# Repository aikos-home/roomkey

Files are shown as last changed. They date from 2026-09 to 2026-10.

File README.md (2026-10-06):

# RoomKey

**A key for every room: a small touch screen on a mechanical keyboard switch, set into an
ordinary German light-switch frame. Doorbell, intercom, alarm and lights, one press away.
Built on ESP32-C6, ESPHome and Home Assistant.**

[Deutsch](README.de.md)

> Status: prototype. The firmware runs on a bare dev board on the desk, the microphone is
> verified, the rest of the parts are ordered. Nothing is installed in a wall yet.
> State of this page: 29 September 2026.

<p align="center">
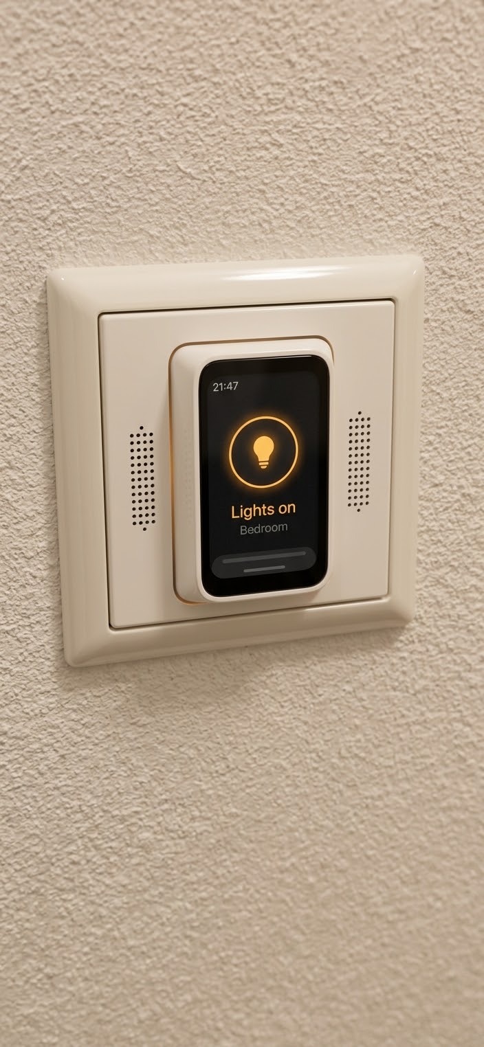
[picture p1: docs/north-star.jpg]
AI-generated concept render: a white light-switch frame with a portrait touch screen key in the middle, speaker and microphone perforations in the white side wings, a soft amber glow around the key
  
  <br><em>Target design — an AI-generated concept render (Google Gemini), not a photo of a built device.</em>
</p>

## What it is

- **A light switch first.** The white rocker around the key still switches the room light,
  with no software involved, so it works without Wi-Fi, without Home Assistant and even
  with a crashed ESP32.
- **A key with a screen.** A 1.47″ touch display on top of a mechanical keyboard switch.
  **Press** does the obvious thing, **hold** does the deliberate thing, and the screen always
  says which is which. Tap and swipe for the rest.
- **The doorbell in every bedroom.** It rings, shows who is calling, and you answer with the
  key: hold to talk, release to listen.
- **The alarm, where you are.** Armed at night? Hold the key for 1.5 s to disarm — Home
  Assistant decides whether that room is allowed to.
- **Local and standard.** ESPHome native API: Home Assistant discovers it with ordinary
  entities, events and actions. No cloud, no custom integration.

It is the in-house counterpart of [Klingelbox](https://github.com/aikos-home/intercom), the
open-hardware door intercom.

## Status

| Area | State |
|---|---|
| UI + interaction state machine (lights, alarm, doorbell, call, menu, info) | ✅ done — runs on the board, verified in simulator and on hardware (scripted tour) |
| Home Assistant contract (subscriptions, light.toggle, disarm script, events, actions) | ✅ **11/11 against a real Home Assistant** (2026.9 dev instance, `tools/ha_contract_test.py`): lights toggle, disarm via HA policy (NIGHT allowed, AWAY refused), ring → answer / talk / hang-up events; also 11/11 against the fake HA incl. audio (`tools/fake_home.py --test`) |
| Demo mode (everything works standalone, no HA needed) | ✅ on by default |
| Status LED (WS2812 on the PoC board; glow ring on the touch board) | ✅ implemented — colours per state, not visually checked |
| Microphone (INMP441) | ✅ **verified on hardware** — wired, recorded: 1 kHz test beep +30 dB, speech +18 dB over the room; 120 Hz high-pass removes knock/handling rumble. Test: `esphome/mic_test.yaml` + `tools/mic_check.py` |
| Intercom audio, voice v2 (shared `aikos_voice` block: RTP/L16 16 kHz, push-to-talk, call model) | ✅ **desk key on v2 since 02.10.**: aikos re-acceptance with the door 71/71; simulator on the same block (`tools/voice_host_check.py`). The key's own audio path (`roomkey.yaml`) stays as the fallback. Listening needs the speaker (WIP, below) |
| Speaker + ringtone (MAX98357A + Waveshare 2030 cavity speaker 8 Ω 2 W) | 🟡 **WIP / opt-in** — compiles, commented out; parts ordered |
| Touch variant of the board (tap / swipe) | 🟡 **WIP** — required by the target design; arrived 02.10.: display, tap and swipe work on the board (`esphome/roomkey_touch.yaml`); chat swipe in a real call, mic, amp and glow ring on it still untested |
| Intercom security | ✅ incoming audio accepted only during an active call; everything else is dropped unheard |
| Door station side | ⬜ other milestone — spec in [docs/intercom-protocol.md](docs/intercom-protocol.md) |
| Optional sensors: SHT31-D climate, LD2410C mmWave presence | 🟡 bought; climate on the shared I²C bus (no extra pins), radar on UART — radar placement still open. No light sensor (decided 06.10.) |
| Enclosure / wall insert | 🟡 fit model + tolerance coupon ready ([hardware/](hardware/)); desk rig (v0) → wall-size fit (v1) next |

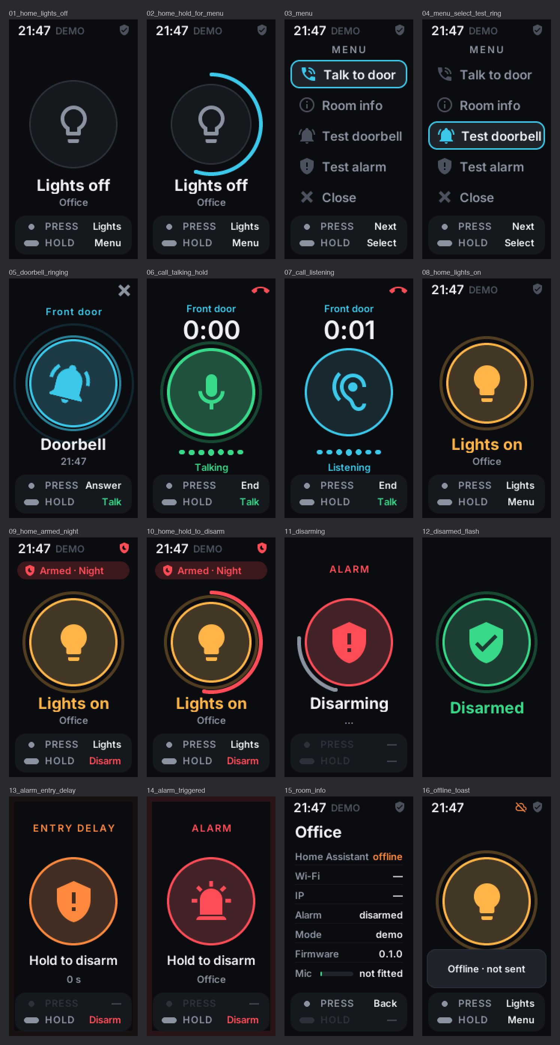
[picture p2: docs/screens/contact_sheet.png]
All screens, rendered by the desktop simulator from the same code that runs on the board


## Inputs

| Screen | Tap | Swipe ↑ | Swipe ↓ | Key press | Key hold |
|---|---|---|---|---|---|
| Home | wakes, shows a hint — never an action | menu | — | all lights | menu · **disarm** when armed |
| Ringing | answer | — | silence this room | answer (on key-down) | answer + talk |
| Call | hold the disc = talk | — | hang up | hang up | push-to-talk |
| Menu | select | — | close | next | select |
| Alarm | — | — | — | hint | **disarm** (1.5 s) |
| **White rocker** | switches this room's light, no software | | | | |

* A tap never switches anything on the home screen: the rocker surrounds the key, so fingers
  brush the screen all the time.
* A mechanical press always starts as a touch; key-down cancels that touch, so one press never
  fires twice.
* The key works on a dark screen — slap it in the dark to switch the lights.

## Hardware

The desk prototype runs on a **Waveshare ESP32-C6-LCD-1.47** (no touch). The target is the
**ESP32-C6-Touch-LCD-1.47** — same chip, touch layer, different size and pinout; the firmware
switches with one line.

### Board comparison (Waveshare drawings)

| | ESP32-C6-LCD-1.47 (PoC, non-touch) | ESP32-C6-Touch-LCD-1.47 |
|---|---|---|
| Outline | 36.4 × 20.3 mm bare PCB | 44.5 × 24.6 mm in black frame, 10.6 mm thick |
| Header | 2 × 9, one GND | 2 × 11, two GND, VBUS, VBAT |
| Mic SCK/WS/SD, L/R | IO18/IO19/IO23, L/R→IO0 | IO7/IO8/IO17, L/R→GND or IO3 |
| Amp BCLK/LRC/DIN, power | IO18/IO19/IO20, 5V | IO7/IO8/IO16, VBUS |
| Key | **IO1** + **IO2** (or the BOOT button) | BOOT + GND |

Firmware: swap the `board:` line in `roomkey.yaml`. The keycap is **not** interchangeable.

### Wiring (desk prototype: ESP32-C6-LCD-1.47)

| Part | Pins |
|---|---|
| Mechanical key switch | **IO1** + **IO2** (IO2 is held LOW by the firmware, because the header's only GND feeds the mic; no soldering; the onboard BOOT button works as the key too) |
| INMP441 mic | VDD→**3V3**, GND→**GND**, L/R→**IO0** (held low by firmware — the header has only one GND), SCK→**IO18**, WS→**IO19**, SD→**IO23** |
| I²S amp (WIP, e.g. MAX98357A) | VIN→**5V**, GND, BCLK→**IO18**, LRC→**IO19**, DIN→**IO20** |

INMP441 is bottom-port: the hole in its PCB must face the room. Mic and amp share the I²S
clocks → half-duplex by design (= push-to-talk, no echo).

Speaker: Waveshare 2030 cavity speaker (8 Ω, 2 W, 20 × 30 × 5.5 mm). Standing on its edge it fits
behind a side wing of the 55 × 55 mm rocker — see the [fit check](docs/fit-check-speaker.png).

## Quick start

```bash
cd esphome
esphome run roomkey_v2.yaml         # build + flash over USB (first time) or OTA (roomkey.yaml = own audio, the fallback)
```
1. **Wi-Fi** (nothing is hardcoded): open https://web.esphome.io in Chrome → *Connect* →
   pick the board → enter Wi-Fi. Or join the hotspot `RoomKey Office` (password: `ap_password`
   in `esphome/secrets.yaml`).
2. **Home Assistant** discovers it; add it with the `api_key` from `esphome/secrets.yaml`,
   then enable *Allow the device to perform Home Assistant actions*.
3. Copy [homeassistant/roomkey_package.yaml](homeassistant/roomkey_package.yaml) into your HA packages.
4. Turn off the key's **Demo mode** switch once the entities exist.

One file per room: copy `roomkey_v2.yaml`, change `node_name`, `room_name` and the entity ids.

## Home Assistant contract

| Direction | What |
|---|---|
| key subscribes | `light.all_lights`, `alarm_control_panel.house`, `binary_sensor.doorbell_button` |
| key calls | `light.toggle`, `script.roomkey_disarm {room, entity_id}` (policy lives in HA) |
| key fires | event `esphome.roomkey {room, node, type}` · type ∈ answer, dismiss, call_door, hangup, talk_start, talk_stop |
| key offers | `ring`, `ring_stop`, `call_state(state)`, `show_toast(message)`, `set_intercom_peer(peer_host, peer_port)`, `simulate_alarm/lights/key` |
| entities | Demo mode, Screen brightness, Input (event: press/hold/…), Screen, Test doorbell, Wi-Fi, IP, intercom counters |

**Security note:** a disarm button in every room is also a disarm button for an intruder.
The key never stores a code — it *asks* HA, and the shipped script only allows disarming
HOME/NIGHT modes and a running entry delay/alarm, never AWAY. Decide that policy consciously.

## Develop without hardware

```bash
cd esphome
esphome compile sim.yaml                                   # desktop simulator (SDL)
.esphome/build/roomkey-sim/.pioenvs/roomkey-sim/program     # SPACE = key, mouse = touch
esphome compile sim_tour.yaml && RK_TOUR=1 RK_TOUR_EXIT=1 RK_SHOTS=shots .esphome/build/roomkey-tour/.pioenvs/roomkey-tour/program  # screenshot every state, cut off from the house
esphome compile sim_v2_check.yaml && python3 ../tools/voice_host_check.py   # voice v2 on the simulator against a fake door
~/.local/share/uv/tools/esphome/bin/python ../tools/fake_home.py --host localhost --test   # HA + door contract test (its audio checks: own audio path)
~/.local/share/uv/tools/esphome/bin/python ../tools/fake_home.py --host aikos-roomkey-desk.local  # interactive fake HA
```
`tour_device.yaml` runs the same tour on the real board and logs frame timings.

## Repository

| Path | What |
|---|---|
| [`esphome/roomkey_v2.yaml`](esphome/roomkey_v2.yaml) | device entry, one per room (voice v2, `aikos_voice`) |
| [`docs/wiring-touch-board.md`](docs/wiring-touch-board.md) | **wiring of the RoomKey Touch prototype**: every wire from the board to mic, amp, sensors, keys, LEDs |
| [`esphome/roomkey.yaml`](esphome/roomkey.yaml) | the same with the key's own audio path (fallback) |
| [`esphome/packages/`](esphome/packages/) | board contracts (PoC, touch, simulator) and feature packages: core UI, HA contract, mic, intercom, speaker |
| [`esphome/src/roomkey_ui.h`](esphome/src/roomkey_ui.h) | UI, input grammar and state machine (LVGL 9) |
| [`esphome/src/roomkey_audio.h`](esphome/src/roomkey_audio.h) | RTP/L16 audio link |
| [`homeassistant/`](homeassistant/) | HA package: disarm policy, ring-stop, door hooks |
| [`tools/fake_home.py`](tools/fake_home.py) | fake Home Assistant + door station: contract test and interactive console |
| [`tools/ha_contract_test.py`](tools/ha_contract_test.py) | the same contract against a real Home Assistant (with [`homeassistant/dev/roomkey.yaml`](homeassistant/dev/roomkey.yaml) stand-ins) |
| [`tools/mic_check.py`](tools/mic_check.py) | records the microphone and checks it hears a test sound |
| [`tools/privacy_scan.py`](tools/privacy_scan.py) | runs before every push |
| [`docs/north-star.md`](docs/north-star.md) | the target design and its decisions |
| [`docs/intercom-protocol.md`](docs/intercom-protocol.md) | audio format and call sequence |
| [`docs/handoff-doorbell-thread.md`](docs/handoff-doorbell-thread.md) | the interface agreed with Klingelbox |

## Performance notes (ESP32-C6, no PSRAM)

RAM 36 % used. Measured on hardware: steady-state LVGL frames 30–80 ms, full view
switches ≈ 100 ms. Software shadows, transform-scaled press animations and a full-screen
alarm tint were replaced by outline halos, size animation and edge bars after the
first hardware run showed 140 ms frames.

## Next steps

1. Enclosure: parametric FreeCAD generator, desk test rig (v0), then a wall-size fit (v1).
2. Speaker, amp and touch board on the bench as they arrive.
3. Wi-Fi + Home Assistant on the real device.
4. Intercom with Klingelbox: a minimal SIP client is the likely path (see the handoff doc).
5. The wall: the insert itself is safety extra-low voltage only (12 V); mains parts (supply, impulse relay)
   sit in certified devices elsewhere, placed by an electrician. Draft and open questions:
   [hardware/docs/insert-design.md](hardware/docs/insert-design.md).
6. Later (decided 30.09.): voice identification, so the family members are told apart even when they
   don't say their name. Local speaker embeddings on the transcriber host, enrolled with ~1 min of speech
   per person through the key's mic. Display only, never for opening doors or disarming. Needs everyone's
   consent; visitors' voices are only compared, never stored.
7. Later (nice to have): translate a resident's answer into the visitor's language on the door screen
   (today every transcript is shown in German; the original words stay in `text_original`).

## Privacy

- The microphone only runs while you hold the key during a call, or while the *Room info*
  screen shows its live level meter. Nothing is recorded or sent otherwise.
- Exceptions you switch on yourself: "Transcriber address" sends a copy of what you say during a call
  (push-to-talk only) to your local transcriber; the WIP test switch "TEST record after ring" records the
  room after every ring and says so on screen. Both are off by default.
- Incoming audio is only accepted during an active call. Keep RoomKeys in the IoT VLAN, like the
  door devices.

## Safety

- Anything on 230 V — the low-voltage supply and the relay for the room light, both in certified devices outside the insert — is a job
  for an electrician. The desk prototype runs on USB only.
- Many older German light-switch boxes have no neutral wire; check before planning a mains supply.

## Licences

- Code (firmware, scripts): [MIT](LICENSE), except the AXS5106L touch driver in
  `esphome/components/axs5106l/`, which keeps its own [MIT licence](LICENSES/MIT-axs5106l-Olivier-Latignies.txt)
- Icon font (Material Design Icons): [Pictogrammers Free License](LICENSES/MDI-Pictogrammers-Free-License.txt)
- Hardware designs (CAD scripts, STL, STEP): [CERN-OHL-P-2.0](LICENSES/CERN-OHL-P-2.0.txt)
- Documentation and images: [CC BY 4.0](LICENSES/CC-BY-4.0.txt)

Designed and written with [Claude Code](https://claude.com/claude-code).

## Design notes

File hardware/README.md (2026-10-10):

# Hardware

Parametric FreeCAD scripts, the same method as [Klingelbox](https://github.com/aikos-home/intercom):
one file holds every dimension, generators read it, `validate()` checks the fit before anything is
printed. Licence: [CERN-OHL-P-2.0](../LICENSES/CERN-OHL-P-2.0.txt).

**→ Build it: [BUILD.md](BUILD.md)** (desk prototype, step by step) · **print it: [print/README.md](print/README.md)** (part list, ready-to-print Bambu Lab A1 files)

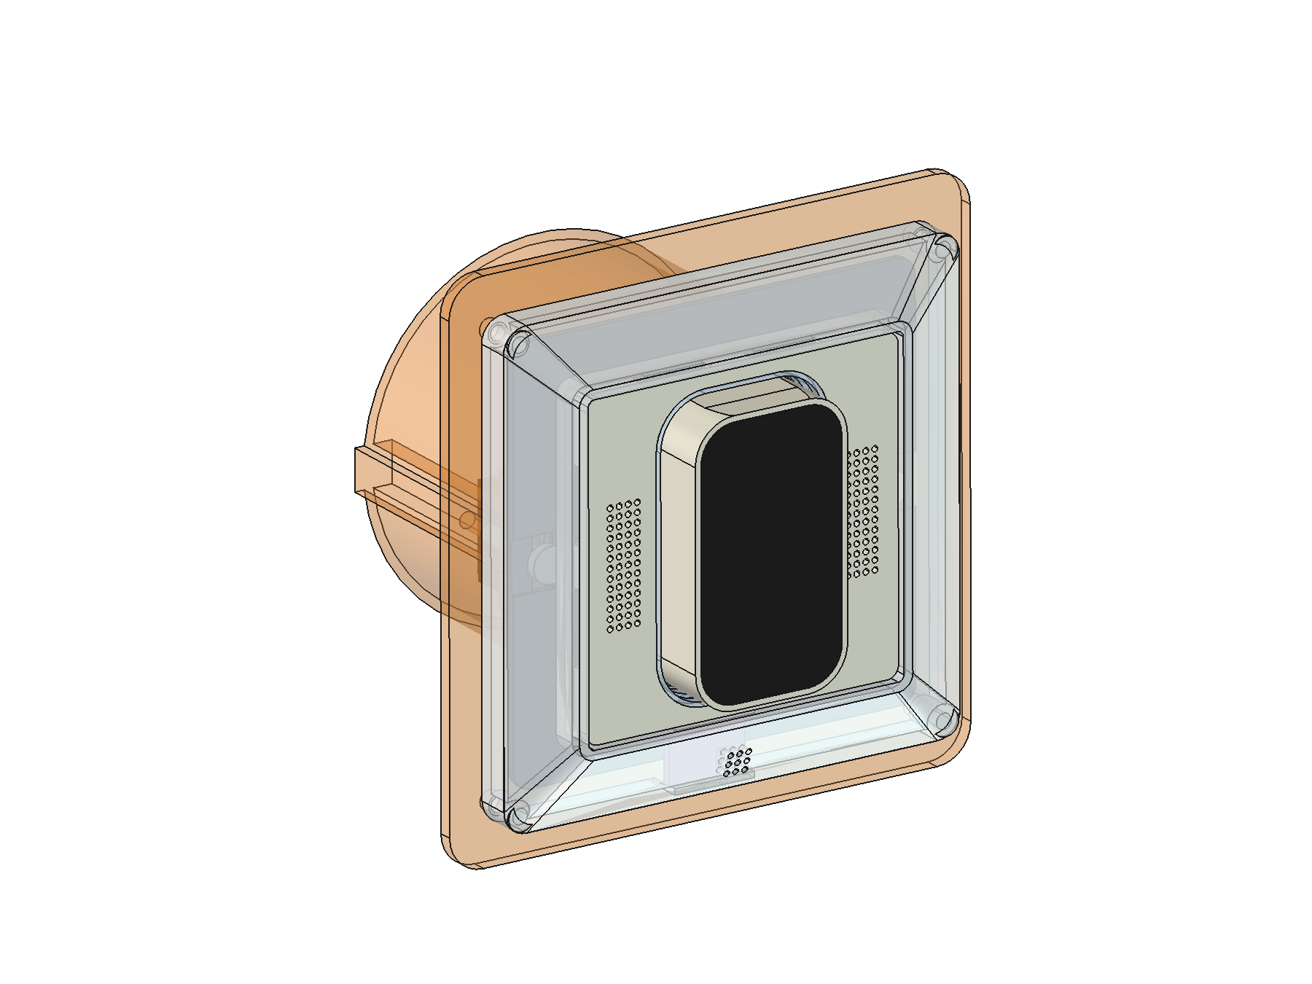
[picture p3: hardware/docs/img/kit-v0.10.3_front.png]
Kit (parts v0.10.3) in the practice box, front 3/4 (FreeCAD)


*Kit (concept v0.7, parts v0.10.3; prototype, WIP, not reviewed): the whole RoomKey in one flush box — touch key, speaker, mic, presence radar,
amplifier, humidity sensor — behind a 1-gang frame. Practice box shown transparent. Real FreeCAD screenshots, made by
[`cad/render_kit.py`](cad/render_kit.py) from the same scripts that write the print files.*

## How this hardware is made — one person and Claude

Everything in this folder comes out of a loop between **one person** (the owner: parts, printer, hands, decisions) and
**Claude** (Anthropic's AI, working in Claude Code: CAD scripts, arithmetic, checks, documentation). Together that covers
the jobs of a small product design team — industrial design, mechanical CAD, tolerance analysis, print engineering,
technical writing and design review. **In practice the owner runs a one-person product design studio.**

**One turn of the loop** (often the same evening, from "this is too tight" to a new print file):

1. **Say it from the bench, in plain words.** Usually one sentence and a phone photo: *"the board fits perfectly but I
   can hardly get it out"*, *"we have two switches — let the key rock so each can be pressed alone, and a press in the
   middle must still do something"*, *"everything goes into one box, except the power supply"*.
2. **Measure the real part.** Calliper values and photos of every module that goes in (speaker, radar, amplifier,
   sensors, the touch board, the wall frame). Each number lands in a parameter file with a tag — **[MEAS]** measured,
   **[DS]** data sheet, **[FREE]** design choice, **[TBD]** assumption — so it is always clear what is known and what is
   a guess. When a value cannot be measured, Claude researches it (vendor drawings, data sheets) and marks it [TBD].
3. **Change the parameters, not a drawing.** Claude edits the parameter files and the FreeCAD generator scripts. No part
   is drawn by hand: every solid, drawing and screenshot is rebuilt from code, so a 0.4 mm change ripples through
   all parts at once.
4. **Let the checks say no before the printer does.**
   - `validate()` runs more than 160 rules per variant (0 errors before anything is exported).
   - Every pair of parts is checked for collisions at rest, key pressed and wobbled, plate pressed at five points.
   - Every printed part must be one solid, and (except the key shell) print without supports: no large surface may
     face the bed in the air.
   - Minimum wall thickness of the printed parts, and clearances reported in millimetres.
   - For the kit, all 41 wires are routed in 3D and checked against the parts; their cut lengths come out as a table.
5. **Hand over print files.** STL per part in print orientation, plus a short print sheet (material, nozzle, layers,
   supports, order) and a wiring sheet. All on one bed of a Bambu Lab A1, PETG.
6. **Print, fit, report back.** The owner prints, tries the real parts and sends the result — which is the next step 1.
   The checks do not catch everything. At the first kit assembly the rocker key simply fell out: the stem forks had been
   sized from a clearance dimension and clamped nothing. The next turn added a catch to the collar, plus a CAD check that
   pulls the key out and must fail to get it free. One turn later the owner dropped the rocker altogether (v0.9).
7. **Review.** Larger revisions go through independent adversarial review rounds: fresh AI reviewers try to break the
   design, and every finding gets a fix or a stated assumption with a test and a fallback
   ([review log](reviews/insert-v0-review-log.md)).

**Rules that hold in every turn.**
- **Safety:** the parts here are extra-low voltage (SELV) only. Everything on 230 V is a certified device, installed by a
  qualified electrician — Claude does not design mains parts, even when asked.
- **The owner decides.** Claude proposes; when a proposal is wrong, it is dropped. Example: Claude moved the sensors into
  a second box to make room; the owner said *"everything in one box"*. The result, kit v0.7, is better: the radar looks
  through the left wing of the plate, the mic hears through a sound tube, and the humidity sensor sits in the frame
  (the owner's idea).
- **WIP is labelled WIP.** Nothing here is built to a standard or certified. Untested features say so.
- **Interfaces are agreed, not guessed.** The pin plan of the kit was checked against the RoomKey firmware by the
  firmware side before it went into this repository.

| | |
|---|---|
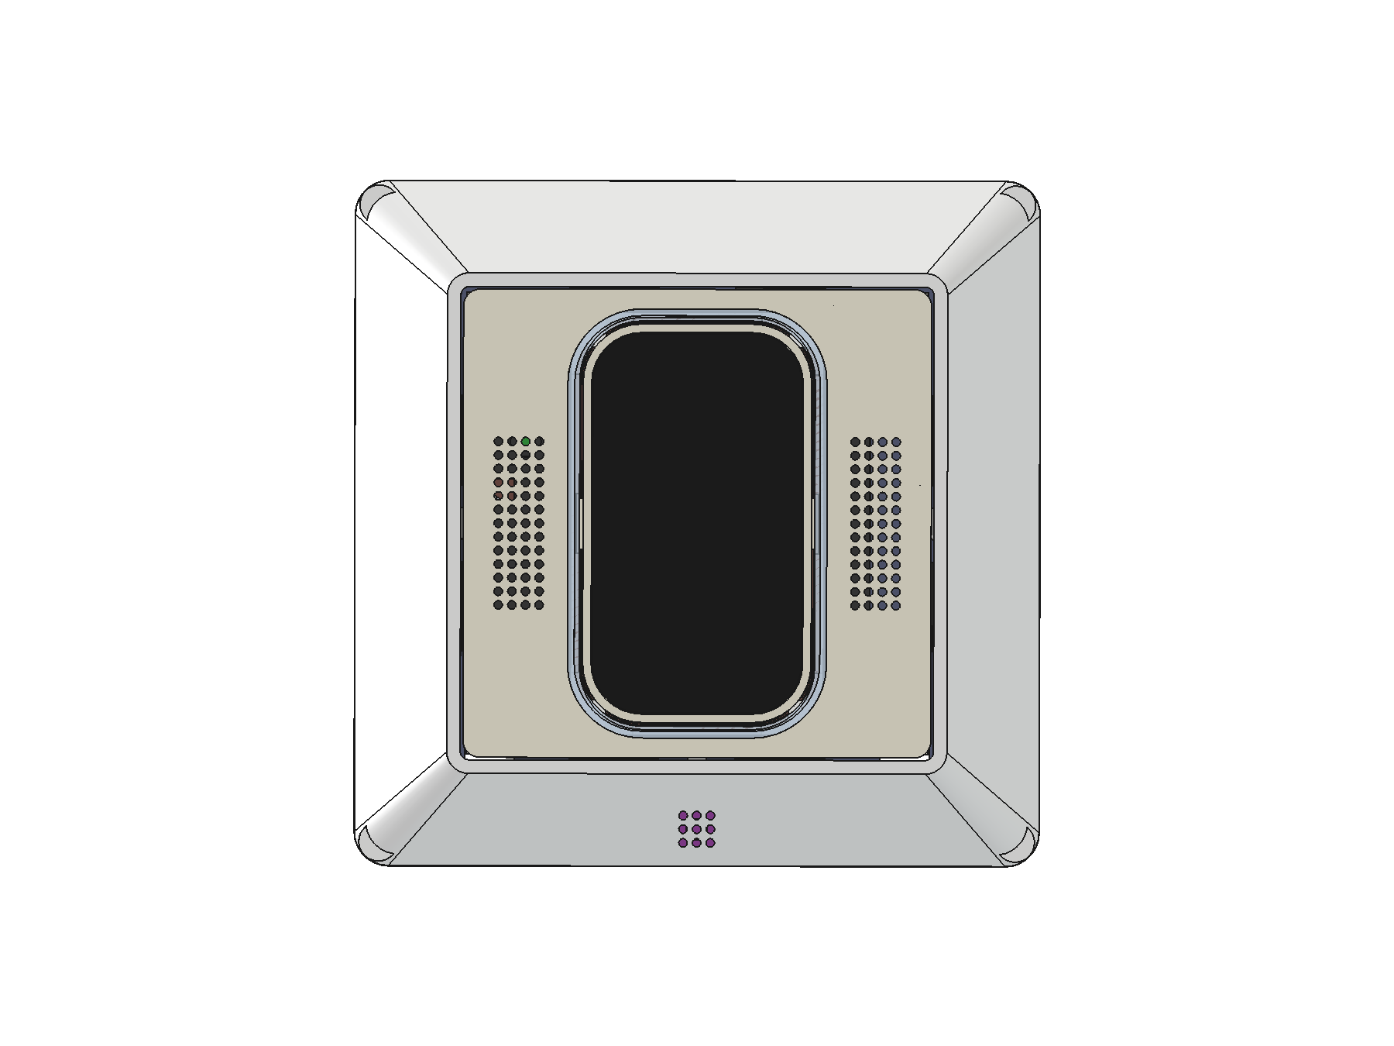
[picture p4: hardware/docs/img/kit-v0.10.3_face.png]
What you see on the wall
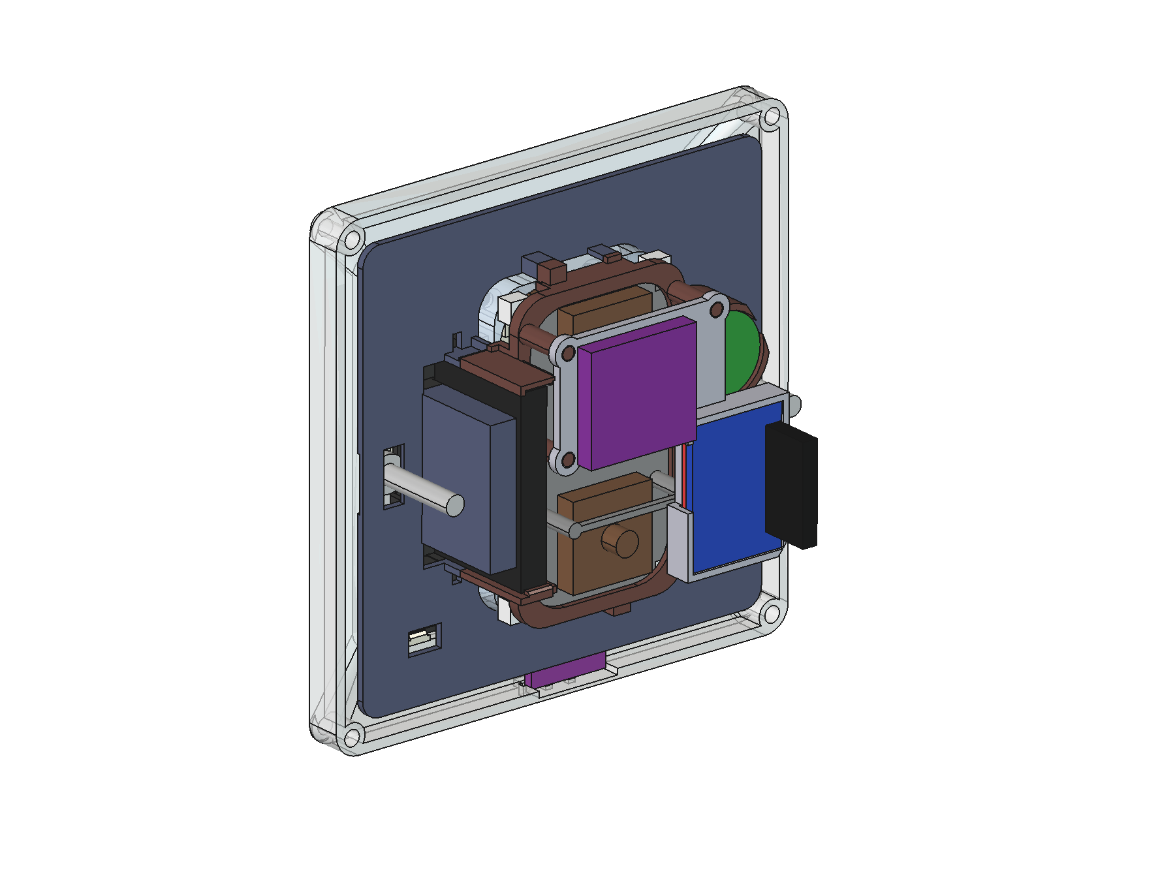
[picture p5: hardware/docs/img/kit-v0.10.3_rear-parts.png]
Rear, without the box: carrier with radar and amplifier, mic, speaker, key switches
|  |  |
| *What you see on the wall: frame, plate with speaker and mic perforation, touch key with glow ring; humidity-sensor vents in the frame.* | *From behind: back carrier with the LD2410C radar (blue) and MAX98357A amplifier (purple), INMP441 mic (green), speaker, the two key switches.* |
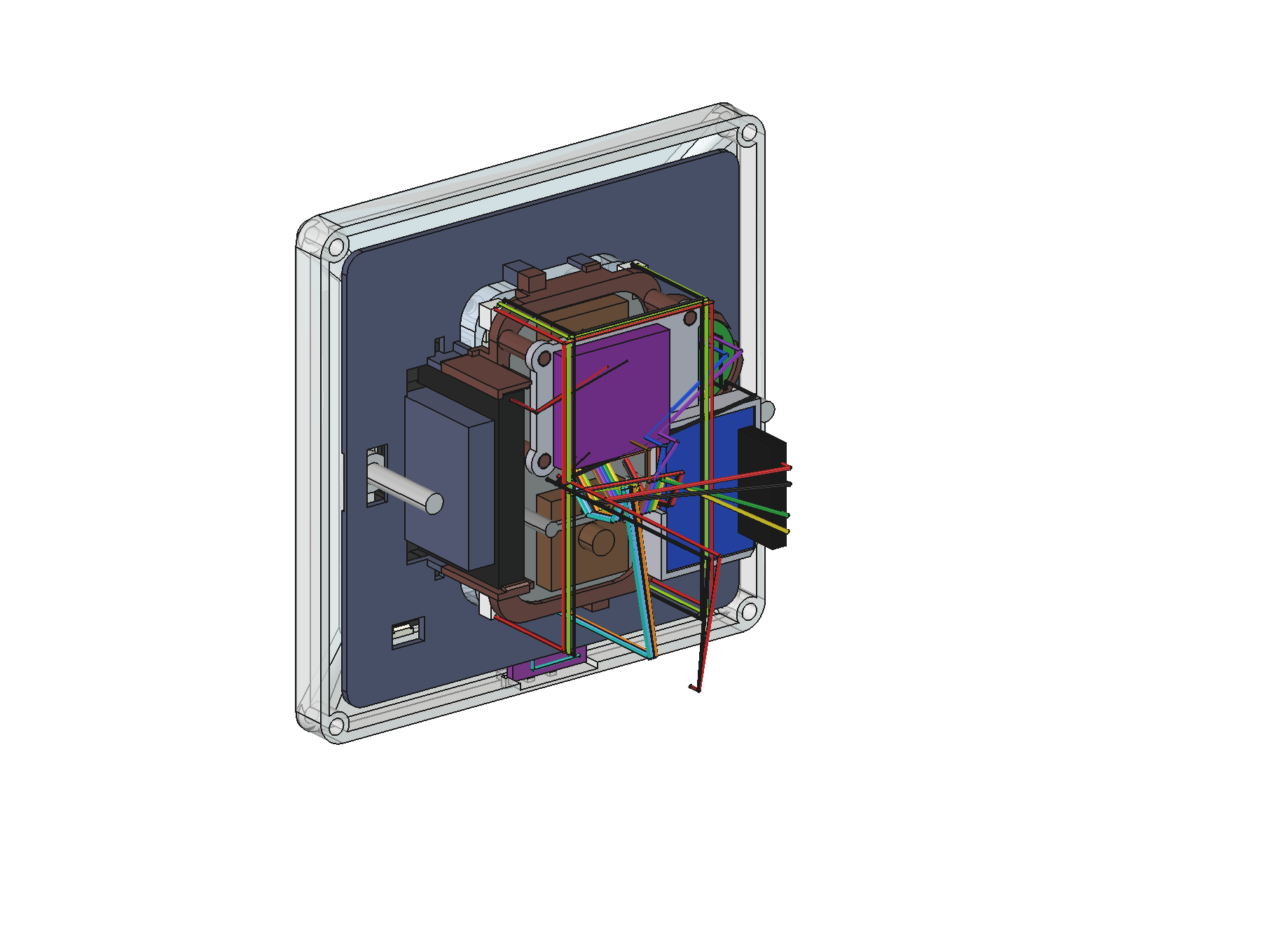
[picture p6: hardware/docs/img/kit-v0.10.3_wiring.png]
Wiring
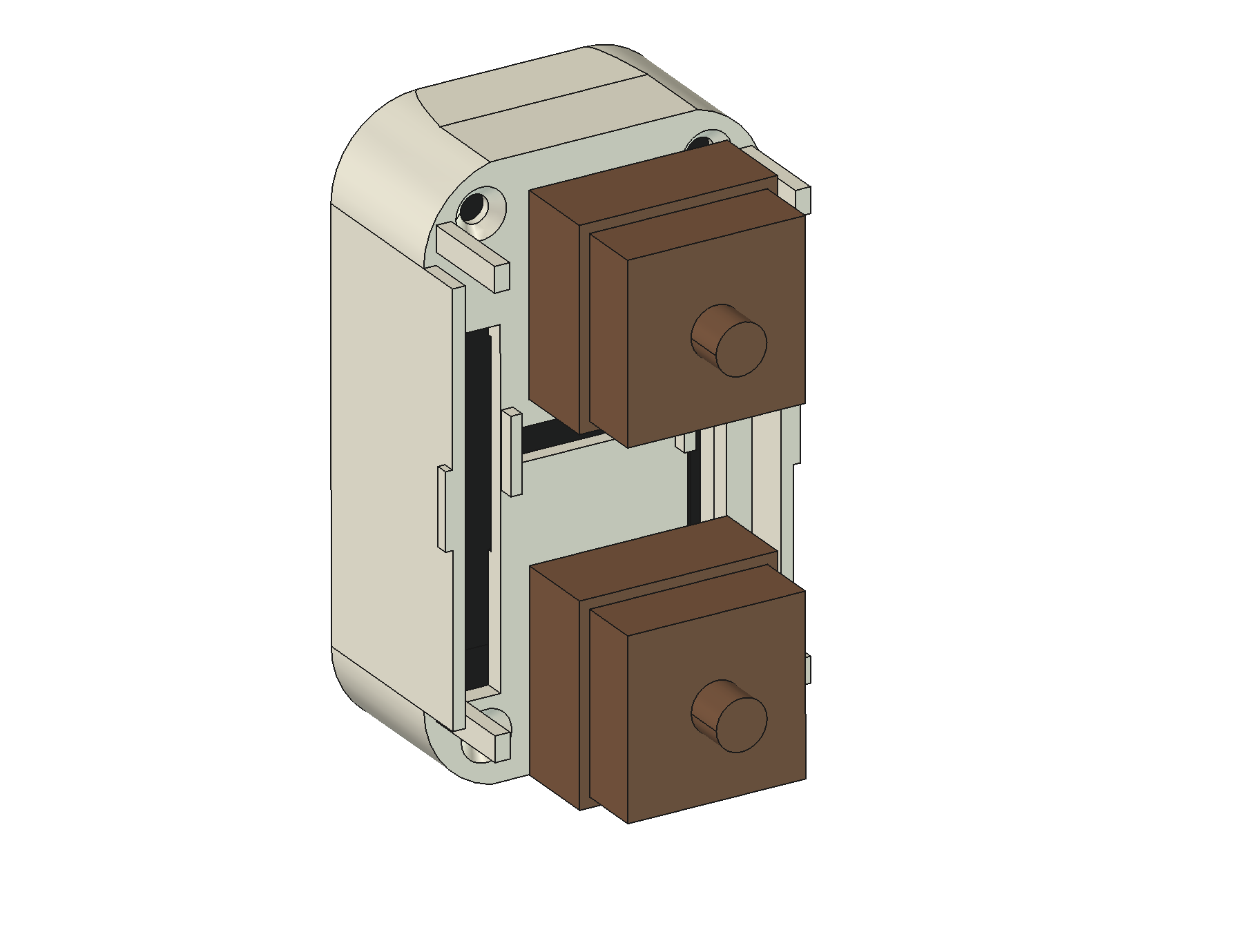
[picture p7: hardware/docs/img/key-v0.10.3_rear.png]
Rigid key v0.9 from behind: fixed socket top, floating socket bottom
|  |  |
| *All 41 wires of the kit, routed in 3D (0.05 mm² silicone wire; cut lengths in [`models/kit-v0.10.3_wiring.json`](models/kit-v0.10.3_wiring.json)).* | *The key from behind (v0.9+): rigid, a fixed stem socket at the top and a floating one at the bottom; both switches are one key.* |

| File | What |
|---|---|
| [`cad/roomkey_params.py`](cad/roomkey_params.py) | every dimension, tagged [DS] datasheet · [MEAS] measured · [FREE] design choice · [TBD] placeholder; `python3 cad/roomkey_params.py` runs the fit check |
| [`cad/make_coupon_v0.py`](cad/make_coupon_v0.py) | tolerance coupon — print this first |
| [`cad/insert_params.py`](cad/insert_params.py) | **wall insert v0.10.4 (draft)**: box, frame, both variants, installation topologies; `python3 cad/insert_params.py` validates L and S |
| [`cad/insert_lib.py`](cad/insert_lib.py), [`make_key_module.py`](cad/make_key_module.py), [`make_insert_L.py`](cad/make_insert_L.py), [`make_insert_S.py`](cad/make_insert_S.py) | FreeCAD generators + collision/clearance checks (rest, key pressed and wobbled with its stems, plate pressed at five points) and print checks |
| [`docs/insert-design.md`](docs/insert-design.md) | **design of the wall insert (v0.10.4 DRAFT)**: concept, stack-up, installation topologies (electrician), BOM, printing, open questions, risks |
| [`cad/desk_lib.py`](cad/desk_lib.py), [`make_practice_box.py`](cad/make_practice_box.py) | **practice box v0.1**: one flush-box replica + a 1-gang frame with the humidity sensor. Prototype, never in a wall |
| [`cad/kit_lib.py`](cad/kit_lib.py), [`make_kit.py`](cad/make_kit.py), [`wiring_lib.py`](cad/wiring_lib.py) | **kit (WIP; concept v0.7, parts v0.10.3)**: the whole RoomKey in one box — back carrier (radar + amplifier), mic sound tube, 41 wires with cut lengths |
| [`cad/view_kit.py`](cad/view_kit.py), [`render_kit.py`](cad/render_kit.py) | open the kit in the FreeCAD GUI (coloured, grouped) and render the images in [`docs/img/`](docs/img/) |
| [`drawings/`](drawings/) | to-scale front views and sections cut from the CAD solids (`tools/insert_drawings.py`) |
| [`reviews/insert-v0-review-log.md`](reviews/insert-v0-review-log.md) | pre-mortems, independent adversarial reviews, scores, resolutions |
| `models/*_print.stl` | ready to slice · `models/*.step` for editing |

Generate (headless, from the repo root):

```bash
PYTHONIOENCODING=utf-8 /Applications/FreeCAD.app/Contents/Resources/bin/FreeCADCmd -c "exec(open('hardware/cad/make_coupon_v0.py', encoding='utf-8').read())"
```

## Coupon v0 — find the fits first

Print flat, PLA, 0.2 mm layers, no supports (≈ 10 min, 9 g). Dots = variant, 1 dot = left.

| Row | Test | Variants (1 / 2 / 3 dots) | Pick |
|---|---|---|---|
| A (switch cut-outs) | press a key switch into the 1.5 mm plate | 13.9 / 14.0 / 14.1 mm | clicks in firmly, no wobble |
| B (mic seats) | drop the INMP441 in | Ø 13.25 / 13.35 / 13.45 mm | goes in without force, doesn't fall out |
| C (stem sockets) | press onto a switch stem | 4.05×1.25 / 4.10×1.30 / 4.15×1.35 mm | snug, no cracking |

The winners go into `roomkey_params.py` as [MEAS]. Repeat in ABS/PETG before the final parts —
they shrink differently.

## Print the kit

**[`print/README.md`](print/README.md)**: the part list, ready-to-print Bambu Lab A1 files (0.4 and 0.2 nozzle; white PETG, clear PLA for the collar and for the key's support contact layers) and the assembly and gluing steps. WIP.

## Wall insert v0.10.4 (DRAFT / WIP, 2026-10-08)

**AI-assisted draft — nothing built, nothing certified, not approved for mains. All 230 V work only by a
qualified electrician of a registered installation company (NAV §13).** Two variants of the in-wall part with the same printed parts, key module and look —
see [docs/insert-design.md](docs/insert-design.md):

* **The insert is SELV-only (12 V in).** No 230 V, no power supply, no relay in the RoomKey chamber; the
  230 V side is certified devices placed by the electrician (where the switch leg ends, behind the partition of a
  two-chamber box, or in the distribution board — decision procedure in the design doc §9). At the common 2-core
  switch leg this usually means a new cable.
* **Variant L — light-switch replacement.** The ivory plate floats on four SMD tactile switches (B3FS) and is a
  push-button: 12 V SELV pulse → certified impulse relay → the light works without Wi-Fi, HA or ESP (and with any
  fault behind the hub's eFuse; FMEA in the design doc §8.2). The glow lights the gap around the key and a
  translucent rim of the plate.
* **Variant S — socket replacement.** Same parts; the plate goes to the ESP only; the socket at that
  position is lost; only sensible at a usable height.

v0.6 adds the owner's first fit test, the rocker key and wider wire slots. v0.8 makes the rocker key captive after the first kit assembly, where it simply fell out. v0.9 drops the rocker (the owner: it scrapes and does not stay in): a rigid key on both MX again, with a fixed and a floating stem socket, keeping the catch and the stop bosses; end-press binding is still desk test R1 (design doc §0, §3). v0.10 makes every part print without supports (supports broke the key and the chassis): the chassis is three prints glued with CA on pins (the one-piece key stays, printed with supports in its pocket); the switch plate is glued in (design doc §0). None of these was reviewed.
Status: **WIP — the adversarial review gate was NOT passed** (4 rounds, scores ≈ 7/10; the remaining MAJOR items need
real parts, a desk rig and measurements — see the review log). CAD closes in all checked states (0 collisions at rest, key pressed, key + stems wobbled ±1.5°, MX2 at the ends of its floating socket,
plate pressed at five points to the nominal and worst-case stop), `validate()` 0 errors, wall check passes. Blocked on
measurements (rocker-to-wall distance ≥ 8.9 mm, frame retention, box interior, conductors behind 5 WAGOs — plan with a
47 mm box), desk-rig tests (key end presses, touch vs key, glow look, mic path, start-up, relay drive at reset) and six
questions to Eltako — list in the design doc §10 and §13. Print
[`make_coupon_v1.py`](cad/make_coupon_v1.py) (switch seat and snap tongues, stem posts, perforation, colour) and the
key shell + switch plate for the end-press test before any other real part.

| More files | |
|---|---|
| [`cad/make_coupon_v1.py`](cad/make_coupon_v1.py) | coupon v1 for the insert mechanics (rows D, E, F, H) |
| [`../tools/insert_drawings.py`](../tools/insert_drawings.py), [`../tools/insert_wallcheck.py`](../tools/insert_wallcheck.py) | drawings and minimum-wall check (any python with numpy + matplotlib, e.g. FreeCAD's bundled one) |

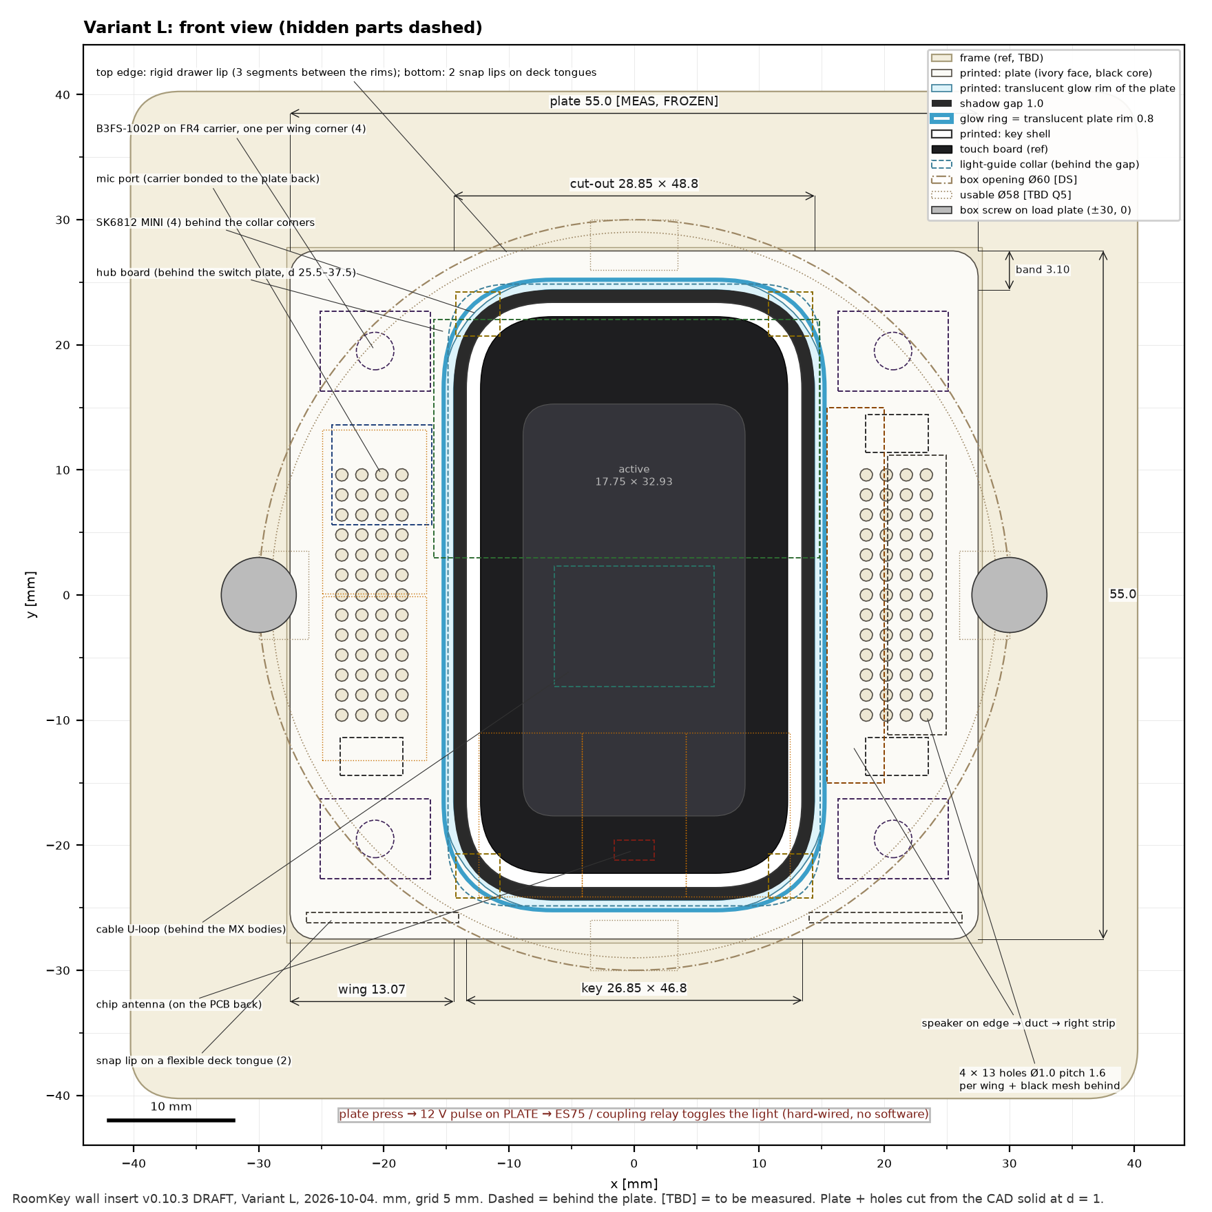
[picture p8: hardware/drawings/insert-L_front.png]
Variant L front


## Plan

**Now (2026-10-04):** first chassis printed and fitted; rocker key and practice box + kit v0.7 ready to print;
parts for the kit arriving. Next: wire the kit on the bench, test the radar through the plate, then the next insert revision.

1. **Coupon v0** — fits for this printer (now)
2. **Desk rig v0** — 55 × 55 rocker face, touch board as the key on two identical MX switches wired in
   parallel (end-press test first, design doc §10), a switch under the rocker as the room-light stand-in (logs only, no mains), speaker on
   its edge with a sound duct, mic, amp, glow LEDs, USB power
3. **Wall fit v1** — same parts inside the real limits (Ø58 box, depth) + a printed dummy flush box
4. **Mounting v2** — screw holes at 60 mm; supply and relay stay outside the RoomKey chamber (SELV-only
   insert) — then the electrician (the v0.5 insert draft models this: [docs/insert-design.md](docs/insert-design.md))

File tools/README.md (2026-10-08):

# tools/

| What | Where now |
|---|---|
| Transcriber (`rtp_recorder.py`, `transcribe_publish.py`, `talk_live.py`, `talk_identity.py`, `transcriber_service.sh`) | **moved** to [aikos-home/aikos `services/transcriber`](https://github.com/aikos-home/aikos/tree/main/services/transcriber), tag `transcriber-v1.0.0` |
| "Who is speaking" eval (`talk_eval.py`, `talk_eval_cases.json`, `eval/`) | **moved** to `services/transcriber/tools/talk_eval.py` and `services/transcriber/tests/eval/` (snapshot test in CI) |

They were removed here on 2026-10-01 after the Mac service switched to the tag (the git history keeps them). Changes
to the transcriber go to aikos-home/aikos only (pull request, `transcriber-unit` green, RoomKey review of the identity
logic, new tag).

Still RoomKey's own: `rtp_play.py` (send a WAV as RTP: stands in for a key or the door), `mic_check.py`,
`fake_home.py` and `ha_contract_test.py` (Home Assistant contract tests), `voice_host_check.py` (the key's voice v2 on
the simulator against a fake door on this machine, build `esphome/sim_v2_check.yaml` first), `privacy_scan.py`, and the CAD helpers
(`cad_preview.py`, `insert_drawings.py`, `insert_wallcheck.py`, and `bambu_kit.py`, which slices the kit into
ready-to-print Bambu Lab A1 files, see `hardware/print/`).

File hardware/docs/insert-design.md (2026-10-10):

# RoomKey wall insert — v0.10.4 (Variant L and Variant S)

> **DRAFT / WIP. AI-assisted design. Not built, not tested, nothing certified.**
> - The insert is a **SELV-only (class III) device**: it never carries 230 V.
> - Everything on the 230 V side is a certified product, installed and tested by a **qualified electrician of an
>   installation company entered in the grid operator's installer register** (NAV §13). Never by the owner, never with
>   parts from this repository.
> - Nothing here is approved for mains.
> - **Review status:** four rounds of independent adversarial review; the quality gate was **not** passed. v0.5 fixes
>   the round-4 findings but was **not** reviewed again — the remaining MAJOR items need real parts and measurements
>   ([review log](../reviews/insert-v0-review-log.md)).
>
> - **v0.6** adds the owner's first fit test, the rocker key, wider wire slots and the kit v0.7 prototype (§0). **v0.8**
>   makes the rocker key captive after the first kit assembly (§0, §3). **v0.9** drops the rocker: a rigid key on two
>   MX with a fixed and a floating socket (§0, §3); **v0.9.1** fixes the speaker tab and the radar tray after the
>   first kit fit, **v0.9.2** closes the radar tray again, **v0.9.3** fits it to the board; **v0.10** makes every part print without supports (§0, §11). None of these was reviewed. (There is no insert v0.7; v0.7 is the kit.)
>
> Date: 2026-10-01, v0.6 and v0.8 2026-10-04, v0.9 2026-10-05, v0.9.1 to v0.9.3 2026-10-06, v0.10 2026-10-07. Licence: CERN-OHL-P-2.0 (hardware), CC BY 4.0 (this text).

**What it is.** The insert replaces the 55 × 55 mm rocker of a German flush-mount switch (or socket) position and
keeps the frame.
- **Key:** a touch board is the keycap. It stands 8 mm proud on two MX switches, framed by a 1 mm gap around which
  the **glow ring** lights up.
- **Plate:** the ivory plate around the key carries the speaker and the microphone behind two perforation strips.
- **Light switching (Variant L):** the plate is also a push-button. It switches the room light through a certified
  impulse relay, **without any software in the path** (north star: [`../../docs/north-star.md`](../../docs/north-star.md)).

| | **Variant L — light-switch replacement** | **Variant S — socket replacement** |
|---|---|---|
| Printed parts | identical: key shell, switch plate, collar, plate (with glow rim), chassis | identical |
| The plate | floating push-button on 4 tactile switches → 12 V SELV pulse on the PLATE line → certified impulse relay **outside** the RoomKey chamber (hard-wired, no software) | same mechanics; the PLATE line goes only to the ESP (HA maps it to the room light — needs a smart light — or a scene); the socket at this position is lost |
| 230 V | only in certified devices: where the switch leg ends (T1a/T1b), in chamber 2 of a two-chamber box (T2), or in the distribution board (T3) — §9 | only in chamber 2 of a two-chamber box (S1) or elsewhere (S2) — §9 |
| In the RoomKey chamber | SELV only: +12 V, 0 V, PLATE | SELV only: +12 V, 0 V |
| Box | **plan with a 47 mm deep box** (box change = plaster work). A standard 40 mm box only if the wall-fit test passes: the parts and 5 × WAGO 221 need ≥ 37.2 mm, but the solid cores probably cannot bend into 2.8 mm (§8.1) | same; only at heights ≥ 70 cm (§9.4) |
| Precondition | a 12 V SELV feed and a relay path must exist. At the common 2-core switch leg (NYM-J 3×1.5) this usually means a **new cable** (§9.2) | a 12 V SELV feed (§9.3) |

**Glossary.**

| term | meaning |
|---|---|
| SELV / class III | safety extra-low voltage (here 12 V DC from a safety-isolating source); a class III device runs only on SELV |
| PE, N, L | protective earth, neutral, line (phase) |
| MCB, RCD, SPD | circuit breaker, residual-current device (30 mA), surge protective device |
| TN-C | old wiring without a separate PE ("klassische Nullung") |
| B3FS, MX | Omron SMD tactile switch (plate); Cherry-MX-style key switch (key) |
| OF, RF, PT | operating force, release force, pretravel of a tactile switch |
| nub gap | air gap between a nub on the plate back and its switch plunger at rest |
| RSS | root-sum-square tolerance stack (statistical); "worst case" = plain sum |
| CLD40 | compression load deflection of a foam at 40 % compression |
| PTC, TVS, eFuse | self-resetting fuse, transient-voltage clamp diode, electronic current limiter |
| FMEA | failure-mode list: what each part's failure does |
| AMS | Bambu multi-material unit (several filaments in one print) |
| d | depth into the wall, d 0 = plate front (§1, coordinates) |

## 0. What changed

**v0 → v0.2 (review round 1: 7 BLOCKERs).** The insert became **SELV-only**; 230 V moved into certified devices
outside the chamber. Floating plate on 4 tactile switches; light-guide collar; mic carrier; U-loop cable.

**v0.2 → v0.3 (round 2: no BLOCKER, ~28 MAJORs).** No foam gaskets between plate and chassis (mic carrier bonded to
the plate, speaker sealed at its grille); glow = translucent plate rim; flange datum + tolerance chain + shims; 8 frame
rims; stainless load plates; T0/T4 and the switch-box inventory; hub GPIO map from the vendor schematic.

**v0.10.3 → v0.10.4 (owner, 2026-10-08: the touch board sits loose in the key shell since the parts are printed with
a 0.2 nozzle).** New `KEY_POCKET_FIT` 0.10/side for the pocket only; `KEY_FIT` 0.15 still sets the key's outer size, so the
shell wall grows 0.05 inwards and nothing outside changes. The fits are now tuned for the 0.2 nozzle (radar tray 0.10
too). L, S, kit: 0 collisions, key captive.

**v0.10.2 → v0.10.3 (owner, 2026-10-08: the collar fits its seat perfectly, but the key scrapes its inner walls).**
Only the collar's inside changes: inner face set back 0.15/side (`COLLAR_IN_EXTRA`, outer unchanged) → key ↔ collar
0.40/side; catch-nub grooves 0.15 deeper (`GROOVE_CLEAR` x 0.1 → 0.25; the groove's back wall 0.65, rule ≥ 0.6 for the
0.2 nozzle). The nubs still overlap the inner face by 0.15; shifted fully sideways the far nub holds by 0.55 — CAD:
key pulled → CAPTIVE at ±0.40. Smallest key ↔ collar gap 0.1 → 0.25 (rest), 0.03 → 0.08 (wobble). 0 collisions.

**v0.10.1 → v0.10.2 (owner, 2026-10-08).**
- **Key back to ONE piece** (the v0.9 shell, byte-identical print file): the owner's one-piece print with supports in
  the pocket fit perfectly; only the chassis broke on its supports. The v0.10 ring/back-plate split is removed;
  `PRINT_WITH_SUPPORTS = {"key_shell"}` — `ceilings()` reports it but does not fail it. Never the chassis.
- **Amplifier pins:** 13.97 (photo) printed too wide, 12.9 (calipers) too close → `AMP_HOLE_PITCH` = their mean 13.435
  (owner's call).
- **Radar tray play 0.15 → 0.10/side:** the same tray fit once and was loose on the next print (print-to-print variance
  ≈ 0.05/side); too tight is fixable with sandpaper, too loose is not. Kit, L, S: 0 collisions, key captive.

**v0.10 → v0.10.1 (owner's print, 2026-10-08: the 2→3 pins did not go into their holes).** The holes open on part 3's
bed face, where the first layers' squish closed the Ø1.4 mouths (0.1 play). Now 0.15 play, a 0.25 × 45° lead-in at
the mouth (`CH_PIN_LEAD`) and a 0.3 point on the pin. Printed v0.10: drill the two holes to 1.5.

**v0.9.3 → v0.10 (owner, 2026-10-07: the whole kit printed with a 0.2 nozzle at 30 mm/s, PETG supports with a PLA
interface — the key shell and the chassis still broke when the supports came out. "Open to gluing (CA) or pin → hole").
WIP: modelled, CAD-checked, not printed.**
- *Why they needed supports (overhang survey, front down):* the key shell's back wall is a 25 × 45 roof over the board
  pocket. The kit chassis: the mic tube stood 1.0 in front of the deck and was the only thing on the bed — the whole
  deck floated; the 71 × 71 flange overhangs the body by ≈ 9.5 all round (≈ 2500 mm²); the rear wall behind the collar
  hangs over the collar seat (a 32 mm bridge on the speaker side, no room for a post); the switch-plate screw bosses and
  the cable-anchor posts hang 3–5 mm free from the ledge.
- ~~**Key = 2 prints**~~ (reverted in v0.10.2) (`key_shell_parts()`): a **ring** (walls, skirts, catch nubs) and a **back plate** (back wall, posts,
  sockets, stop bosses) that sits inside the ring like a lid (0.1/side, `KEY_PLATE_CLEAR`) — the fit locates it, CA from
  behind; the 4 board screws hold board and plate as before. No room for pins in the 1.0 walls; none needed.
- **Chassis = 3 prints** (`chassis_parts()`, all variants): **1 front** (d < flange front: deck, pockets, rims, mic tube),
  **2 flange** (flange + webs to the collar's back face + the speaker duct), **3 rear** (rear wall, ledge, speaker cradle,
  hub posts). Joints: 1→2 glued with the collar through both openings as the jig; 2→3 on **two pins Ø1.2**
  (`CH_PIN_POS` (±5.7, ±26.25), on the island ribs — the only free spots: the plate's tactile switches sit at the corners,
  the speaker on +x, the box's screw domes on the axes) + the web tops, CA.
- **Switch plate glued** onto the ledge (owner's choice) — no screws, no bosses (`SWP_SCREWS = ()`); the **cable anchor**
  (posts + bar) now stands on the switch plate's back.
- **Kit mic tube** flush with the deck front: foam at the plate end 1.5 compressed (`KIT_MIC_FOAM_FRONT`), the module end
  unchanged; the module shelf filled down to the rear part's front face.
- **Frame rims** tied to the deck by webs in the plate-skirt gaps (they print with the front part).
- **Every part prints front down** (collar back down, as before). New check `ceilings()` in every build: planar faces that
  face the bed must be short bridges (span ≤ 16, measured as min(bbox, 4·area/perimeter)); now the widest is 8.7 (the
  insert's mic pocket roof), the kit's 5.7. L, S, kit: 0 collisions, nothing trimmed, key captive, radar tray closed.
- *Open:* the amplifier pins on the carrier — unchanged in CAD since v0.8 (spacing 15.97 outer), but the 0.2-nozzle print
  came out a little too wide; the hole positions are only [PHOTO ±0.5] → owner to measure the two holes.

**v0.9.2 → v0.9.3 (owner's print, 2026-10-06).** The radar slid about in the v0.9.2 tray (≈ 0.5 too long, the short side
just too loose). The board is **22.03** long (caliper photo), not 22.26 (10-03): `RADAR_H` corrected, `KIT_RADAR` now
derived from `RADAR_W/H`, tray play 0.2 → **0.15/side** (= `KEY_FIT` [MEAS]). Pocket 16.14 × 22.33. Kit: 0 collisions,
frame closed.

**v0.9.1 → v0.9.2 (the owner's slicer view and a photo of the radar's antenna face, 2026-10-06; WIP, not printed).**
- *My error in v0.9.1:* the full-width antenna window removed the plate strip under the board's parts edge; next to it
  the cable-loop keep-out (x ±7) takes the tray's +x wall over y −7.8…2.5, so the tray became an open "C" — the floppy
  shape v0.8 had fixed. No check caught it (no collision, still one solid).
- *The photo:* SMD parts run along the **whole** long edge opposite the header, corners included, up to ≈ 4.1 from it;
  the chip reaches 2.3 from that edge. So no plate strip can run under that edge with the board lying on the plate.
- *Fix:* the board sits on **two 1.3 mm ledges** at its short ends, header side only (11.0 from the header edge; the
  parts band starts at 11.6). Every part on the antenna face then floats ≥ 0.2 above the plate, the v0.8 window and the
  plate strip under the parts edge are back, and the tray is closed. Tray 1.3 taller. Reference envelopes from the photo
  (`KIT_RADAR_EDGE` 4.2 × 1.1 [TBD height]); the radar's front parts are no longer exempt from the collision check.
- *New check:* `build_kit` probes the plate strip along the parts edge over the keep-out's y range → "radar tray frame:
  CLOSED", else it fails. Kit: 0 collisions; edge parts ↔ carrier 0.2, pin stubs 0.5, chip 2.5.

**v0.9 → v0.9.1 (the owner's kit fit, 2026-10-06; WIP: modelled, CAD-checked, not printed).** Key, amplifier and
microphone fit as printed.

| Input | v0.9.1 |
|---|---|
| The speaker does not go in: a ≈ 0.5 mm wire tab at the centre of one short end hits the cradle rib. "A hole in one of the towers, not a fork (integrity)." | **Blind tab slot** in the +y cradle rib (towards the amplifier): open to the back (the speaker and its wires come from behind), closed to the front, 4.4 wide (tab 3.4 [TBD] + 0.5/side), 0.9 beyond the speaker end; the rib is thickened outward there so 0.8 of wall stays behind the slot. The +y snap hook is dropped (the slot cut its root and left it as a loose 2nd solid; at the round speaker end it caught nothing). `SPK_TAB` overhang 1.8 (photo) → 0.5 (owner). The speaker reference now carries the tab. New hard check: every printed part is exactly ONE solid. |
| The radar does not sit flat in the intended orientation (header to the wall): small SMD parts on the antenna face, along the long edge opposite the header, land on the carrier. (Turned by 180°, the header pin stubs do the same.) | The antenna **window spans the full board width** → the board rests only on its two short ends (1.5 / ≈ 3 mm). New references: "LD2410C edge parts" (`KIT_RADAR_EDGE` [TBD]) and "LD2410C pin stubs" (`KIT_RADAR_STUBS` [TBD]); both clear the carrier by 0.1. |

CAD: L, S and the kit 0 collisions; key still captive. Print folder `roomkey-bausatz-v0.9.1/` (new: chassis, carrier).

**v0.8 → v0.9 (the owner's verdict on the rocker, 2026-10-05; WIP: modelled, CAD-checked, not printed, not reviewed).**

| Input | v0.9 |
|---|---|
| "Die Idee mit der Wippe ist an sich schlecht. Es führt zu zu vielen Problemen mit der Integrität und Usability." Two problems: a rocking key on stem tops, skirts in the collar and stop bosses may scrape instead of gliding; and it did not stay in (v0.7 fell out, the v0.8 catch was a patch). | **Rigid key on the two MX** (the owner chose it from three options: this, one centre MX + a 2u stabiliser, a printed plunger). The forks and rocking pads are gone; the v0.5 **stem posts with cross sockets** are back (coupon v0 row C fit): **fixed** on MX1 (top), **floating** on MX2 (bottom: its y-arm slot runs through the post, its x-arm slot is 1.80 wide → the stem floats ±0.25 along y, so a pitch error cannot strain the two stems against each other). The key moves straight in and out only. — §3 |
| Keep the key captive | The **v0.8 catch** (nubs in the collar grooves) and the **4 stop bosses** (stop at 3.4, before MX bottom-out) stay unchanged; socket friction holds the key as well. CAD: 0 collisions in L, S and the kit; key pulled → **CAPTIVE**; MX2 shifted ±0.25 → its post still clears the housing window (0.10). |
| Top / bottom functions | Not needed by the firmware today: it already ORs both switches into one key (`key_raw`). If they are ever wanted, they come from the touch point at the click (the AXS5106L touch panel), not from the mechanics. Wiring unchanged (KEY1 = BOOT, KEY2 = IO6). |
| Still open | End-press binding (desk test **R1**) — the reason v0.6 went to the rocker. If R1 fails, the documented fallback is one centre MX + a 2u plate-mount stabiliser. |

**v0.6 → v0.8 (the owner's first kit assembly, 2026-10-04; WIP, not reviewed).**

| Input | v0.8 |
|---|---|
| "Nothing stops the rocker, with the ESP32 module, from simply falling out." | **Key catch:** a rigid nub on each side skirt runs in a groove in the collar's inner face. The groove is open to the back and closed towards the room, so the key is **captive**. The CAD check pulls the key and requires a hit, also when the key is shifted sideways. — §3 |
| Why: the stem forks clamped nothing. Their gap of 4.10 was the cross socket's slot length, which has play; the stem arm is ≈ 4.0. Even a tight fork is a weak spring, so friction alone cannot hold the key | fork gap 3.90 [TBD coupon] for a light pinch; retention comes from the catch, not from friction — §3 |
| The collar must come out for key service | **the collar is no longer glued**: the plate holds it. Assembly: key → collar → plate. The acoustic seam it used to seal is open (fallback: a thin foam ring) — §4, §11 |

**v0.5 → v0.6 (the owner's first print and wishes, 2026-10-02 … 04; WIP, not reviewed).**

| Input | v0.6 |
|---|---|
| First chassis printed (PETG, A1): the touch board fits "extremely perfectly" but is hard to get out; the USB port is no problem | removal = **push-out through the screw hole** (owner tried it: ok); no USB port in the insert — §3 |
| "Two switches — let the key rock so each one can be pressed alone; a centre press must still do something" | **rocker key**: both MX read separately (KEY1 / KEY2), centre press = both; forks, stop bosses and tapered ends; CAD checks rest, pressed, rocked both ways and wobbled — §3 |
| The cable slot under the display is too narrow; pins or wires must go straight back from the header holes | middle slot wider; **header slots** in the key back for pre-soldered pins or wires — §3 |
| Real speaker measured (19.32 × 29.81 × 4.57, stadium shape, paper-thin white ring) | reference body updated; hooks on the straight part are **still open** — §6.2 |
| WS2812B-MINI 3535 ordered (2.0 high) | LED corner notches in the switch plate — §6.3 |
| Production goal: print → plaster → silicone mould → UV resin | noted, not designed for yet; PETG for the prototypes — §10 |
| Whole RoomKey in ONE box, bench power from a lab supply | **practice box v0.1 + kit v0.7** (radar, amplifier, mic, humidity sensor in the frame, 41 wires) — §10 |

**v0.4 → v0.5 (round 4: no BLOCKER, 19 MAJORs; not re-reviewed).**

| Round-4 finding | v0.5 |
|---|---|
| "Works down to 7.6 mm rocker-to-wall" false: the retention needs ≥ 8.9 | Q1 threshold **≥ 8.9 mm**, derived in `validate()` from the pressed snap lips; below it: redesign (thinner deck/lips) — §2 |
| Misconnection text described one case; the fuse protects only +12 V with a low-impedance return; the most likely miswire (lamp as return) leaves the SELV side live | per-conductor **matrix** (§8.1); **RCD 30 mA and a voltage + insulation check before connecting are preconditions** (§9.1); fuse breaking capacity ≥ 1500 A, creepage around it; "SELV only behind the key" qualified |
| IO5 (RELAY_DRIVE) floats at reset → relay pulses at power-up / boot loops | 100 k pull-down + 20 ms qualifier ahead of the one-shot; desk-rig test R12; strapping list corrected — §8.2 |
| eFuse checked against the largest single load; named part cannot do 0.4 A; SNT61 trip point unknown | rule uses the **summed peak (0.37 A) with ±7 % tolerance**; 60 V-class eFuse, OVLO 17 V, SMBJ24A [TBD part]; light-path-vs-hub-short as BLOCKED-ON-DATA (Q4f, test R14, fallback) — §8.2 |
| RF spring distance had a sign error (8.1 mm pressed, not 11.5) | corrected, WARN, closer metal listed (contact leaves, cable wires) — §8.5 |
| Wall-check slices missed the speaker hooks (0.2–0.6 layer stack) | hooks 1.2 thick (tip 0.8); planes through every lip and hook; claim qualified — §10 |
| Touch gestures can fire the key; power-cut state (Q4e) without assumption/fallback; 40 mm box headline; owner measurements inside a 230 V box not flagged; stale mains-in-box text in the north star | each with assumption, test (R13, R15) and fallback; **47 mm box as planning default**; every question tagged owner / electrician, wall-fit prototype defined (§13); north-star note added |
| Mic wires squeezed under the carrier; coupon not in the V-0 chassis material; end-press fallback collides with the cable path | **mic wire well** beside the pocket with an S-loop and a foam plug (§6.1); coupon row D bases in the V-0 filament (§10); binding judged **likely**, both key modules for the first rig (§3) |

**v0.3 → v0.4 (round 3: no BLOCKER, ~15 MAJORs).** Full record: [`../reviews/insert-v0-review-log.md`](../reviews/insert-v0-review-log.md).

| Round-3 finding | v0.4 |
|---|---|
| End presses of the key: the 6–7° pitch model was physically impossible (two stems cannot tilt), the CAD check exempted the colliding pair, the stop bosses landed on a housing shape that does not exist | **Pitch model and stop bosses removed.** MX moved to (0, +15) / (0, −13): the key overhangs its stems by 8.4 / 10.4 mm, like a keycap edge. The key stops at MX bottom-out. CAD checks the key **and its stems** wobbled ±1.5° at rest and pressed, **without** the key ↔ housing exemption: 0 collisions. End presses beyond the stem play are a **desk-rig test** with a named fallback (stabiliser) — §3 |
| Shadow gap "stays dark" was false | Described as it is: **the gap glows** (it looks onto the lit collar); the rim glows dimmer. Decision Q12 with a mask fallback — §4 |
| Terminal zone held one WAGO | **5 × WAGO 221-412 modelled** (3 SELV joints, PE cap, spare-core cap) at d 25.6–44.2 → box ≥ 37.2 mm. Conductor bends: WARN + wall-fit test + fallback (47 mm box) — §8.1 |
| T1 cost/feasibility understated | T1 split into **T1a** (lamp / ceiling box) and **T1b** (wall junction box → new box, plaster work); ES75 needs **≤ 10 A protection** (B16 → B10 or a fuse); luminaire responsibility; T1-LED enclosure sized from the parts (≥ 95 deep) — §9 |
| Switch datum on solder over an unsupported ledge | **SMD B3FS-1002P** on a **flat-backed** carrier; wires soldered from the back into a slot in the flange; the seat's bridge sag is a term in the chain — §5.1 |
| Speaker not located in x; "front volume opens only to the room" false | **Foam strip behind the speaker** presses it onto its face gasket; hooks got a lead-in; leak paths listed honestly — §6.2 |
| A hub fault stopped the light; "cannot exceed the B3F rating" false | **eFuse (0.4 A) on the hub branch**, RELAY_DRIVE through a series Schottky, FMEA of the +12 V / PLATE nodes, claims rewritten — §8.2 |
| 230 V misconnection understated | **250 V AC entry fuse** ahead of everything; **UL94 V-0 chassis mandatory**; text says what really happens — §8.1 |
| SNT61 start-up and mic path untested, no fallback | Assumption + test + fallback for both — §6.1, §8.3 |
| Coupon printed differently from the parts | **0.10 mm layers for plate, chassis and coupon**; support blockers in the carrier pockets; coupon has the pad and the real B3FS seat — §10 |
| Wires inside the key had zero margin | 0.4 mm channel in the key back → 1.2 mm clearance — §3 |
| Many smaller items (press force counted touching switches, plate ↔ frame only at rest, wrong tongue stiffness, firmware power-save, coupled boxes, 411.3.3, chamber-2 accessibility, glossary, drawing captions, S-specific questions …) | fixed or turned into stated assumptions with a test and a fallback; see the review log |

## 1. Files and how to regenerate

| What | Where |
|---|---|
| every insert dimension + `validate()` (both variants) | [`../cad/insert_params.py`](../cad/insert_params.py) (imports [`../cad/roomkey_params.py`](../cad/roomkey_params.py)); sources in `SOURCES` |
| FreeCAD part builders, collision/clearance checks, section export | [`../cad/insert_lib.py`](../cad/insert_lib.py) |
| generators | [`make_key_module.py`](../cad/make_key_module.py), [`make_insert_L.py`](../cad/make_insert_L.py), [`make_insert_S.py`](../cad/make_insert_S.py), [`make_coupon_v1.py`](../cad/make_coupon_v1.py) |
| models | `../models/` (details below) |
| drawings (to scale, cut from the CAD solids) | [`../drawings/`](../drawings/): `insert-{L,S}_front`, `_sections`, `_plan-sections`, `_layers`, `_retention`, `key-module_section`, `insert-topologies` (schematic) |
| minimum-wall check of the printed parts | [`../../tools/insert_wallcheck.py`](../../tools/insert_wallcheck.py) |
| review record | [`../reviews/insert-v0-review-log.md`](../reviews/insert-v0-review-log.md) |

Contents of `../models/`:
- **Printed parts:** `key_shell`, `switch_plate`, `collar`, `plate_{L,S}`, `chassis_{L,S}`, `coupon-v1`. Each comes as
  `.step` (assembly position) and `_print.stl` (print orientation).
- **Plate for the AMS multi-part print:** `plate_{L,S}_body_print.stl` + `plate_{L,S}_glowrim_print.stl`.
- **Assemblies and references:** `insert-{L,S}_assembly.step` (incl. switches, WAGOs, speaker, foam, hub envelope),
  `insert-{L,S}_wall-reference.step` (box + frame, with [TBD] values), `insert-{L,S}_printed-assembly.stl`.
- **Check reports:** `insert-{L,S}_check.json`.

```bash
python3 hardware/cad/insert_params.py            # rules for L and S → ERROR / WARNING / INFO / OK (must be 0 errors)
python3 hardware/cad/insert_params.py --tbd      # every [TBD] value and what to measure
FC=/Applications/FreeCAD.app/Contents/Resources/bin/FreeCADCmd
for f in make_key_module make_insert_L make_insert_S make_coupon_v1; do
  PYTHONIOENCODING=utf-8 $FC -c "exec(open('hardware/cad/$f.py', encoding='utf-8').read())"; done
PY=/Applications/FreeCAD.app/Contents/Resources/bin/python   # any python with numpy + matplotlib
$PY tools/insert_drawings.py && $PY tools/insert_wallcheck.py
```

**State of this revision.**
- `validate()`: **0 errors** in L (29 warnings, 139 OK, 18 info) and S (21 warnings, 137 OK, 17 info). A WARNING is an
  open item with its assumption, test and fallback; INFO lines are assumptions and never count as OK.
- FreeCAD: every printed part is a valid single solid. **0 collisions** in all of these states:
  - at rest (all pairs);
  - key fully pressed (key, stems and board moved; MX bottom-out);
  - key **and stems** wobbled ±1.5° about x and about y, at rest and pressed — only the stems-in-housing and
    stem-in-socket pairs are exempt;
  - plate tipped at five press points, to the nominal stop (all pairs) and to the RSS worst-case stop.
- Wall check: no free wall below 0.8 mm found in any printed part (§10, with its sampling limits).

**Reading `insert-*_check.json`.** Three 0.0 values are designed contacts, each labelled "by design": a lip on its
catch face (the pivot), the collar back face on the rear wall, the speaker front edge on the plenum floor.

**Coordinates.** Front view: origin = plate centre on the plate front face, x right, y up. **d = depth into the wall**
(d 0 = plate front, d 9.0 = wall plane [TBD Q1]). CAD: Z = −d.

**Tags.** **[DS]** data sheet / norm / vendor drawing · **[MEAS]** measured · **[FREE]** design choice · **[TBD]**
assumption until measured (list: `--tbd`).

## 2. Stack-up (both variants)

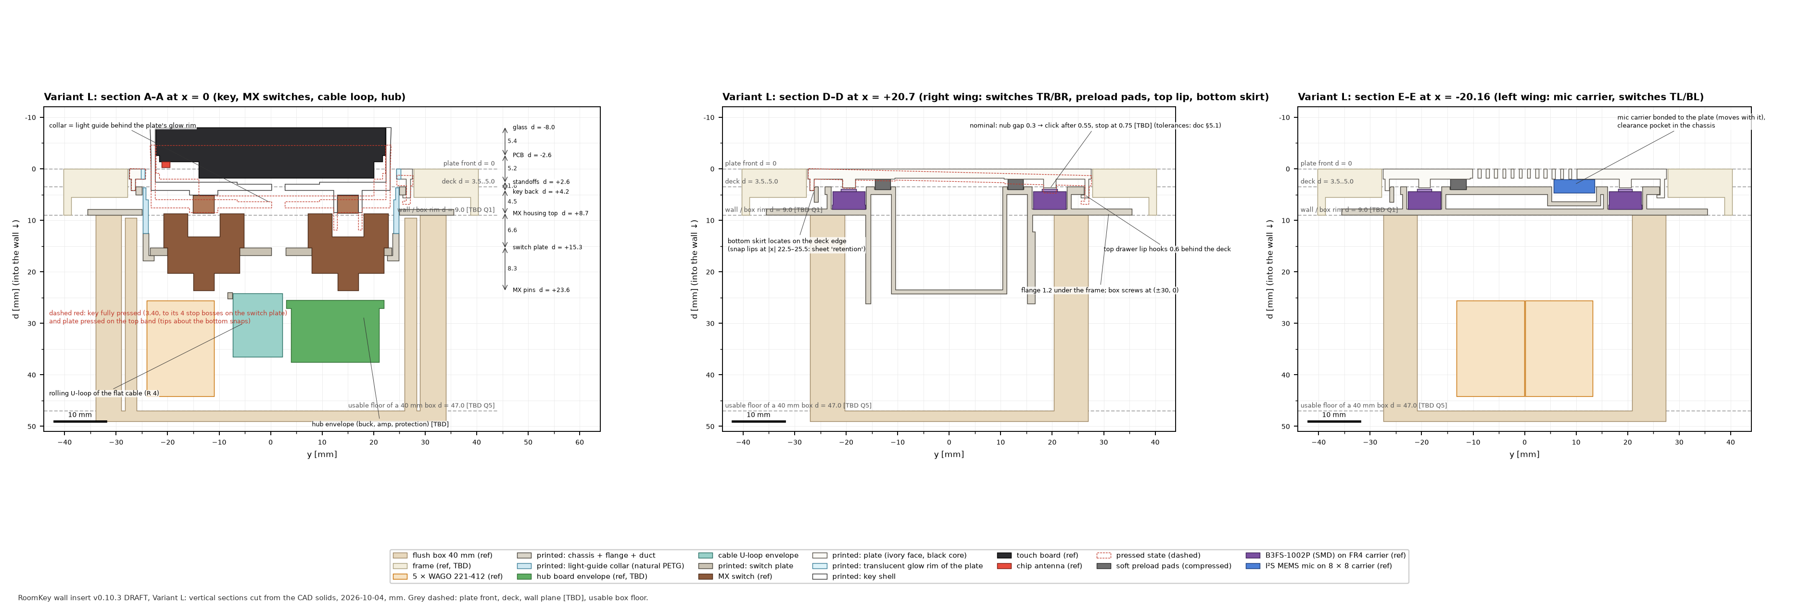
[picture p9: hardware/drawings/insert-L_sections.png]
section A–A, Variant L


| d (mm) | Part | Source |
|---|---|---|
| −8.0 … −2.6 | touch board display module (glass → PCB front, 5.4) | [DS] Waveshare side view |
| −1.4 … −0.3 | ceramic chip antenna on the PCB back, non-USB end | [DS] drawing; size [TBD] |
| 0 … 2.0 | plate skin (ivory face over black core; 0.8 translucent glow rim at the key opening) | [FREE] |
| 2.0 … 4.2 | plate skirts (locate on the deck edges); nubs 2.0–3.6 (Ø2.5 × 1.6) | [FREE] |
| 2.1 … 4.7 | mic carrier, bonded to the plate back (moves with the plate) | [FREE] / [TBD] |
| 3.9 … 7.8 | **B3FS-1002P** plunger tip 3.9 → body 4.4–7.0 → FR4 carrier 7.0–7.8, **carrier on the flange front face (datum)** | [DS] Omron |
| 3.5 … 5.0 | chassis deck; bottom tongues with rib to 6.5; preload pads in 0.5 pockets | [FREE] |
| 3.6 … 12.5 | translucent light-guide collar (2.6 thick at the corners) | [FREE] |
| 4.2 … 8.0 | key side skirts (roll limit) | [FREE] |
| 5.0 … 5.6 / 6.5 … 7.1 | top drawer lip / bottom snap lips (catch faces 5.0 / 6.5) | [FREE] |
| 5.0 … 5.6 | plenum floor over the speaker's front edge | [FREE] |
| 5.6 … 25.6 | speaker 2030 on edge (grille → foam face gasket → channel → plenum → right strip), foam strip behind it | [DS] Waveshare |
| 7.8 … 9.0 | flange (under the frame) with stainless load plates; box screws at (±30, 0) | [FREE] / [DS DIN 49073] |
| 12.6 … 14.9 | 4 × SK6812 MINI on the collar's thick corners | [DS] |
| 15.3 … 16.8 | switch plate (MX plate mount 1.5) | [DS] Cherry |
| 20.3 / 23.6 | MX housing bottom / pin tips | [DS] Cherry |
| 24.0 … 36.5 | cable U-loop envelope | [FREE] |
| 25.5 … 37.5 | hub board envelope (PCB + parts both sides) | [TBD] |
| 25.6 … 44.2 | **5 × WAGO 221-412 standing**: 3 below the hub (y −24.1 … −11), 2 left of it (x −24.9 … −16.6) | [DS] WAGO / [FREE] |
| 47.0 | usable floor of a 40 mm box (2 mm floor/entries) | [TBD Q5] |

**Depth budget.** Parts and WAGOs end at d 44.2 → the box must be ≥ 37.2 mm deep. A standard 40 mm box leaves
2.8 mm, plus the gaps beside the WAGOs, for the conductors to bend in — probably not enough: **plan with a 47 mm box**
(§8.1).

**Front zone.** The switch stack is built from the flange datum:
- plate 2.0 + nub 1.6 + gap 0.3 + B3FS 3.1 + carrier 0.8 + flange 1.2 = 9.0 = the assumed rocker-to-wall distance.
- **The design needs ≥ 8.9 mm** (validate: the pressed snap lips must still end 0.3 before the wall at the worst-case
  press). The switch stack alone would allow 7.6 (the nub shrinks), but the lips, tongues and flange windows are fixed
  to the plate. Above 8.9 the chassis is regenerated for the measured value; below it the deck and lips must be made
  thinner (a redesign). **Q1 gates the first print.**

## 3. Key module (shared)

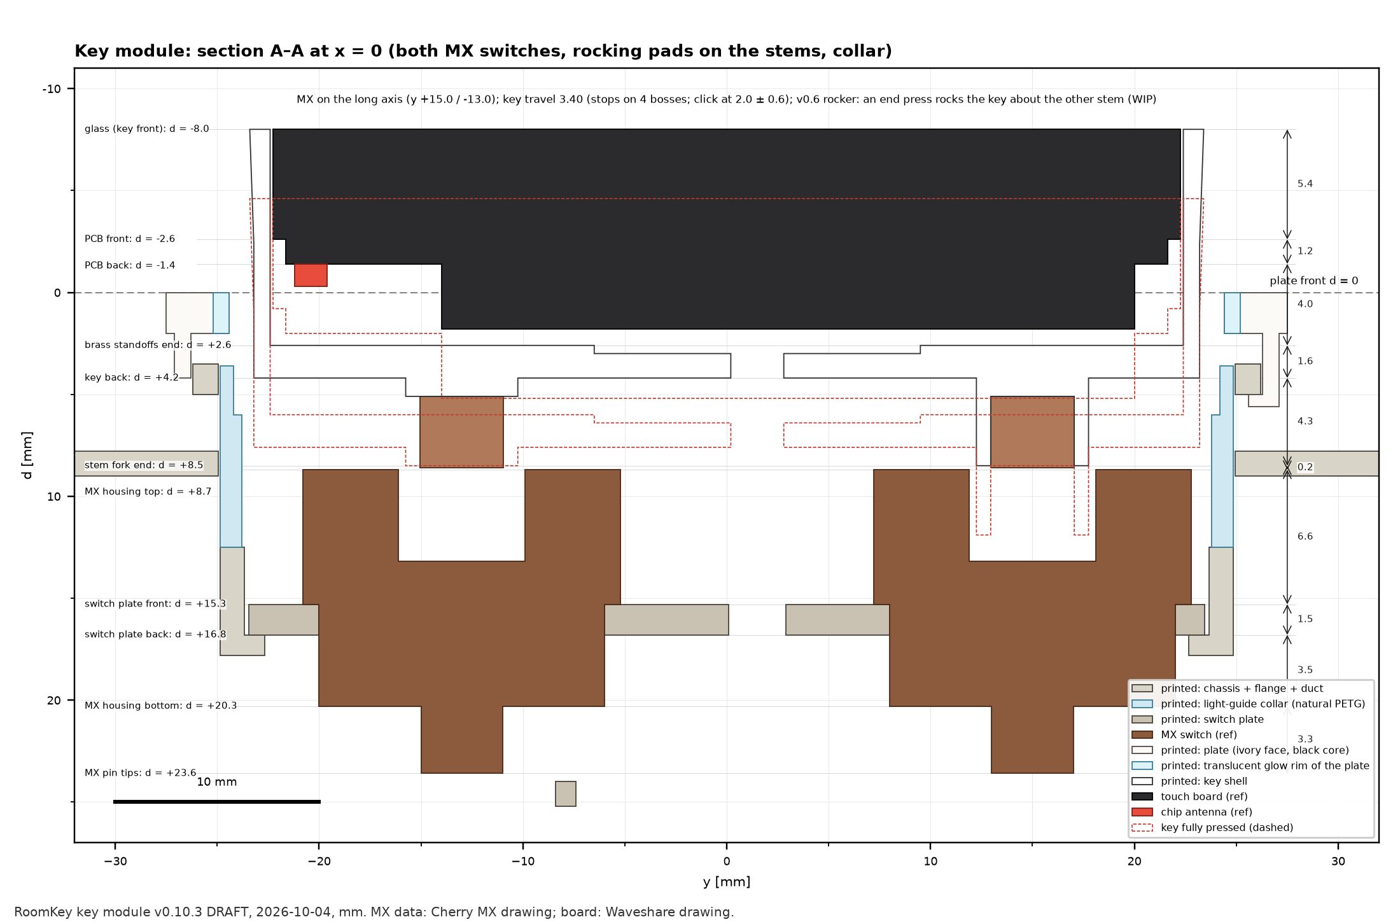
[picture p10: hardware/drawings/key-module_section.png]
key module


**Key shell** (printed front down in the **plate's ivory**, supports inside the pocket, §10). Its front edge is a plain
90° edge and its 8 mm side walls show layer lines; the render's key looks softer (option: a 0.4 × 45° front chamfer).
The 1.0 mm ivory walls have no black core: backlight/glow bleed through the key sides is part of light test R2.
- Pocket 24.85 × 44.80 R5.9 for the board frame (0.15 fit).
- The board is screwed from behind with 4 × M2 × 4 DIN 965 into its brass standoffs [DS]: top pair 17.78 apart,
  bottom pair 17.00 apart, 39.00 vertical. Female M2 thread is [TBD]; fallback M2 nuts.
- Back wall 1.6, screw heads flush. A **0.4 mm channel** in its inner face carries the 14 wires: a band x ±10.4,
  y −6.5 … 9.5 to the cable slot, plus a strip along each header column (|x| 7.4–10.4, y −16.6 … 10.5: the pins run
  y +9.65 … −15.75 [DS drawing]).
- Two stem posts Ø5.5 with MX cross sockets 4.10 × 1.30, 3.4 deep (coupon v0 row C, v1 row E). v0.9: MX1 (top) is
  the **fixed** socket (full cross); MX2 (bottom) **floats** ±0.25 along y (its y-arm slot runs through the post, the
  x-arm slot is 1.80 wide). The fixed socket locates the key; the floating one only holds it in x.

**Guidance: the two MX stems guide the key**, on the long axis at (0, +15.0) and (0, −13.0), pitch 28.
- The key overhangs the stems by **8.4 (top) / 10.4 (bottom)** — about a 1u keycap's stem-to-edge distance (9.1).
- **Both switches are the same brown (tactile)**, so both ends feel the same. v0.9: each stays on its own pin (KEY1 =
  BOOT, KEY2 = IO6) and the firmware ORs them into one key.
- The **side skirts** (long sides only, |y| ≤ 16.5) run in the collar with 0.25 clearance per side. They limit roll
  and keep the key off the plate.

**Force map** (the owned no-name browns: 2.0 ± 0.7 oz = 0.56 ± 0.2 N each [DS of that part]; measure on the rig):

| press point | switches moved | force | bump |
|---|---|---|---|
| centre (between the stems) | both | ≈ 1.1 N (0.7–1.5) | two at once (felt as one) |
| off-centre, between the stems | both: the stem play (±1.5°) allows only ±0.7 mm of travel difference, less than the 2.0 mm pretravel | ≈ 1.1 N | two, slightly staggered |
| key end (beyond a stem) | both, if the key slides; **binding likely** (below) | unknown | — |

**Touch vs key.** The north star says a tap never acts on Home. But published touchscreen studies give 0.8–1.2 N for
swipes — inside the key's actuation range. *Assumption:* normal swipes and taps do not push the key 2 mm down. *Test
R13:* 3 people, 100 swipes from each end and the centre, 100 taps → 0 key-downs. *Fallbacks:* heavier switches
(≥ 1 N each, then repeat R1), firmware: a touch that moved > 2 mm suppresses key-down, and Ringing answers on key-up
after a still press (WIP — the firmware is not changed in this revision).

**Travel and stop.** v0.9 (kept from v0.6): the key stops on **4 stop bosses** that land on the switch plate after
**3.4**, before MX bottom-out (4.0), with both switches past their worst actuation point (2.6). The press ends on the
plate, not on the stems. The key back is then 1.1 above the modelled MX housing top. The stem posts enter the housing
windows with 0.35 per side (0.10 when MX2 sits at the end of its ±0.25 float).

**Wobble (CAD).** The key, its board and **both stems** are tilted ±1.5° (KEY_WOBBLE_DEG [TBD], typical MX stem play
1–2°) about x and about y, at rest and pressed. Only the stem-in-housing and stem-in-socket pairs are exempt.
- No collision. Smallest gaps (v0.9): key ↔ collar 0.03 (roll, about y), key ↔ MX housing 0.26, key ↔ plate 0.79.
- The collar's inner face is set back 0.4 at the short sides over its first 2.4 mm, for the key ends.

**End presses — BLOCKED-ON-DATA, binding likely.**
- *Estimate (review round 4):* an end press puts a moment of ≈ 24·F on the two stem guides; with μ ≈ 0.15 and ≈ 6 mm
  of guide length the friction is ≈ 1.2·F — a sticking drawer. Optimistic values (μ 0.1, 7 mm) still need ≈ 3.7 N.
  The CAD cannot model friction; the overhang (8.4 / 10.4, like a keycap edge) does not prevent this.
- *Test R1 (desk rig, first thing to print: key shell + switch plate + two MX):* press every 5 mm along the key; 1000 ×
  at each end; with a fingertip and a knuckle. Pass: every press clicks, no sticking.
- *Fallback:* one centre MX + a plate-mount 2u stabiliser in the 1.5 mm switch plate (geometry from the bought part).
  It **collides with today's cable path** (11.2 mm wide at y +1.5, through the key back and the switch plate): the
  cable must be split into two bundles beside the centre switch. **Not modelled yet** — build this fallback key module
  alongside the first rig and test both.

**Rocker key — SUPERSEDED by v0.9 (owner, 2026-10-05: the rocker idea is bad in itself).** The rocker text below and
the v0.8 catch reasoning are kept as history. The catch nubs, grooves and stop bosses are still in the model; the forks,
rocking pads and the rocked CAD state are not.

**Rocker key — owner's wish, 2026-10-02 (v0.6, WIP: modelled, not reviewed, test print pending).** Both MX are read
**separately** and the key **rocks**: top end → top switch, bottom end → bottom switch, centre → both. The owner's words:
viewed from the side the key should be "funnel-shaped"; and "the press in the middle should do something".
- **Why the old key could not rock:** the full cross sockets made the key a rigid frame on two stems. Rocking one end down
  by the 2.0 mm pretravel needs ≈ 4° of tilt over the 28 mm stem pitch; MX stems allow 1–2°. The same constraint made
  the end presses bind (R1, see above), so the rocker replaces that problem.
- **Fork mounts:** each stem is held by a fork, not a socket.
  - Two prongs (0.8 thick, 2.0 wide, gap = the old 4.10 socket arm) pinch only the **end faces of the stem's x-arm**.
    These faces are normal to x, so turning about x stays free while the pinch still holds the key on.
  - A **rocking pad** (a cylinder about x, R 1.5) rests on the stem top.
- **Stop bosses:**
  - Four bosses (|x| 11.25–12.4, y +18.5 / −16.5, 2.0 long) land on the switch plate.
  - **Centre press:** the key stops after **3.4** (both switches past their worst actuation point 2.6; MX bottom-out 4.0
    is not reached).
  - **End press:** the key rocks about the far stem's top until the near pair lands, at **≈ 6.1°**. The near switch
    then travels **2.96** (≥ 2.6 + 0.3); the far switch stays at its top stop (0 travel), so top and bottom separate
    cleanly.
  - The bosses sit outboard of the near stem, so the far fork carries only a small pull (≈ 0.1·F) under a hard end
    press.
- **Funnel:** the short-end walls are set back 0.2, rising over 5.6 behind the glass (the 1.0 wall keeps 0.8). It is
  invisible from the front.
- **CAD check (both variants):**
  - States: key rocked to its stop at both ends (key + board turned about the far stem, near stem down, far stem
    still), pressed to the bosses, and wobbled ±1.5° at the deepest travel before a boss lands.
  - **0 collisions.**
  - Gaps when rocked: plate edge 0.25–0.27, collar 0.13–0.14, MX housings ≥ 0.25, forks in the housing window 0.25.
  - Wall check: OK.
- **Costs and open points:**
  - a **15th cable wire** (IO6 = KEY2; IMU INT2 must stay disabled) [TBD RoomKey software];
  - firmware: centre = both switches within a window (≈ 100 ms, rig);
  - **an end press needs only ≈ 0.43 N** (one switch, lever 28/36.4), so touch test R13 is harder. Mitigation: a key
    event during a moving touch is dropped (firmware); fallback: heavier switches;
  - ~~the pull-off force of the fork pinch~~ → v0.8: the key is held by the catch below, not by the pinch;
  - the real MX window shape (6.2 [TBD]).
- **Test print** (owner, PETG, A1, 0.10): only the new key shell, on the 01.10. parts. File:
  `druck/roomkey-taste-v0.6-wippe/` with `DRUCKEN.md`.

**Owner's verdict, 2026-10-05: the rocker concept is dropped.**
> "Die Idee mit der Wippe ist an sich schlecht" — too many problems with integrity and usability: it is unclear that
> rocking can ever glide instead of scrape, and a rocking key does not stay in the housing.

A replacement key is being designed (WIP). The v0.8 key shell and collar below are interim parts. The firmware needs
no change for a single switch on BOOT (RoomKey software, 2026-10-05).

**Key catch — v0.8 (owner, 2026-10-04: "nothing stops the rocker, with the ESP32 module, from simply falling out"; WIP,
modelled, not reviewed).**
- *The cause (my error):* the forks had a 4.10 gap, the cross socket's slot length, which has play; the stem arm is ≈ 4.0.
  So they clamped nothing. A tighter fork would still be a weak spring (0.8 × 2.0 × 4.3 prongs), good for tens of grams.
- *The catch:*
  - A rigid **nub** sits at the free end of each side skirt: 6.0 long, 1.0 high, 0.55 proud of the skirt, at y 0.
  - It runs in a **groove** in the collar's inner face. The groove is 0.1 deeper than the nub and 0.5 longer per end; it is
    **open to the collar's back face** and closed towards the room, 0.45 in front of the nub at rest.
  - Pressing and rocking move the nub deeper into the groove (free). Pulling stops at the groove's front wall, with an
    overlap of 0.30 per side. The key's side play of 0.25 can free only one side at a time.
- *The collar is not glued any more.* The plate overlaps its front face, so the collar cannot leave while the plate is
  on.
- *Assembly:* key onto the stems → collar from the front over the key (the nubs enter the open groove ends) → plate.
- *Service:* plate off → collar out → key off.
- *CAD check:* the key is pulled 0.60 towards the room, centred and shifted ±0.25 sideways; it must hit the collar every
  time, and pulled 0.40 it must not. Rest, pressed, rocked and wobbled stay without collision.
- *Fork:* the gap is now 3.90 [TBD], a light pinch so the key does not rattle on its stems.

**Shadow gap.** 1.0 ± 0.21 (RSS: plate location 0.1 + print 0.1, switch-plate screws 0.1, MX cut-out 0.05, stem play
0.1, socket 0.05). If the key moves further, its skirt touches the collar at 0.75 gap. **It glows** (§4).

**Switch plate.** 1.5, flat print, MX cut-outs 14.0 (coupon v0 row A). Fixed with 2 × M2 × 4 DIN 965 from the front
at (±10.5, 1.5) into ledge bosses.

**Cable.** 14 × AWG30 fine-stranded silicone wires, laid flat (11.2 × 0.8).
- Order: VBUS, GND, BOOT, IO4, IO3, IO5, GND, IO7, GND, IO8, IO16, GND, IO17, 3V3. Ground sits next to the I²S clocks.
- Route: from the header pads across the 0.4 channel, through the slots in the key back and the switch plate at
  y +1.5, then a **rolling U-loop, R 4.0** behind the MX bodies, clamped under an anchor bar.
- Inside the key the wires lie in **1.2 mm** between the board-back parts (3.2 [TBD Q8]) and the channel floor.
  Fallbacks: AWG32 (0.6), or a polyimide flex jumper. Use a board **without pre-soldered headers**.
- **Life target 250 k presses** on the desk rig (30 y × 20/day = 219 k). Fallback: the flex jumper.

**Removal and BOOT.**
- **Fit test 2026-10-02 (owner, real touch board, PETG, A1, 0.10 layers):** the board fits the pocket "extremely
  perfect" (KEY_FIT 0.15 → [MEAS]), but it is **hard or impossible to get out** again.
  - **Removal = push-out** (tried by the owner, 2026-10-02: "ok, not super easy — it's ok like this"). With the key off
    its stems and the screws out, push the board out to the front through the Ø2.2 screw holes in the key back. They
    sit over the brass standoffs; use a toothpick or a 1.5 mm hex key. **No spudger slot** (it was considered: hidden
    in the long sides behind the plate front; dropped).
- **Wires (owner's request 2026-10-03, v0.6):**
  - The central slot is now **12.8 × 2.6** (was 1.4 wide) for 15 wires, or thicker prototype leads.
  - **A 3.0 × 27.5 slot runs through the key back under each pin column** (x ±8.89, y −16.6 … +10.9), so pins or wires
    can leave the header holes straight back. These slots replace the old channel strips.
  - The webs that remain: 0.99 to the central slot, 0.90 to the bottom screw's countersink, 2.04 to the wall. The
    centre strip with the forks stays tied to both solid end regions.
  - Beside a column the pins pass the MX housing with ≈ 0.8 clearance. Anything sticking out must end ≤ 7 mm behind
    the key back: the switch plate is 11.1 behind it at rest and 7.7 when pressed. A standard 2.54 header's long pins end
    ≈ 3 behind it. Flat wiring to the central slot still
    works (the band channel stays).
- The key pulls off its stems (target ≥ 10 N, coupon row E) and hangs on its cable. Behind it there is SELV only.
- The key (26.85 × 46.8) is not a small part.
- **USB (owner's decision 2026-10-01, for v0.6): no USB port in the insert.** The shell's closed top wall leaves no room
  for a plug at the board's USB-C. Flow: first flash and Wi-Fi setup over the bare board's USB-C on the bench; then
  assembly, 5 V over the header (VBUS from the hub); every update over the air. USB is needed only for a rescue (a
  firmware that never brings up OTA): key off, 4 screws, board out of the shell — its USB-C is free (the cable leaves
  from the header pads, away from the USB end), and the hub's Schottky stops back-feed from the laptop's VBUS.
  *Fallback if rescues become common:* the header carries the native USB lines (pin 14 USB_P, pin 16 USB_N, pin 1 VBUS,
  pin 3 GND [DS schematic]; pins 10/12 are SCL/SDA) → 2 more cable wires (16) and a USB-C socket (with 5.1 k on CC) behind the key.
- The key shares GPIO9 (BOOT strap) with the board's button: powering up with the key held enters ROM download mode.
  That is also a **failure mode**: a key held or stuck when the power returns leaves the RoomKey in download mode
  (screen dark) until the next power cycle — the light still works. Recovery: release the key, power-cycle (MCB of the
  12 V supply). Flashing: over the air, or the board's USB-C with the board out of the shell.

**Board LEDs.** The board's always-on red PWR LED and the charger STAT LED (blinks with no battery) are **covered with
black tape** at assembly. They would shine through the 1.0 mm shell.

## 4. Plate, glow ring, wings

front view, Variant L

**Plate.** 55.0 × 55.0 [MEAS, FROZEN], corner R 2.0 [TBD Q7].
- Skin 2.0: ivory face 0.6 [TBD, coupon row H 0.6/0.9/1.2] over a black core, one AMS colour change → opaque.
- Cut-out 28.85 × 48.80 R7.9. Wings **13.07**, bands **3.10**.

**Glow — what it will really look like** (round-3 ray checks, CAD geometry):
- The collar's lit front face (d 3.6, x 13.675–14.875) lies **directly behind 0.75 mm of the 1.0 mm gap** (0.35 at
  the short sides). Looking into the gap you see the frosted, lit light guide: **the gap itself glows**, brightest
  near the corner LEDs.
- The plate's **0.8 mm translucent rim** (co-printed natural PETG, flush with the face) lies 0.45 mm over the lit
  face, 1.6 mm behind it. It glows too, dimmer. Being flush, it is visible wherever the plate is — but the key stands
  8 mm proud: from more than ≈ 13° off-axis the key hides the far-side gap and rim. A standing adult looks down at a
  switch at 105 cm by 30–40°, so the **lower glow line is mostly hidden**, and the upper gap shows the lit key side wall.
- Together: a glowing line at the key base, as in the render — not a dark gap with a lit rim.
- **LEDs off:** the gap shows a pale natural-PETG band instead of a black shadow.
- **Q12 (the owner, on the desk rig):** keep it (glowing gap), or **mask the collar's inner 0.75 mm** (black paint or
  tape on its front face) → dark gap + lit rim, dimmer overall. Test LEDs on and off, in daylight and at night,
  **from standing height and from the bed**, not head-on.

**Collar.** Translucent frosted PETG. Wall 1.2 on the straight runs; the outer corner radius is 5.0, so the corners are
2.6 thick along the diagonal.
- The **4 × SK6812 MINI** sit centred on those thick corners (d 12.6), facing forward.
- v0.8: the collar is **not glued**. It sits in the deck seat (0.1 fit) and the plate holds it in, because the key's
  catch runs in its grooves and the collar must come out for key service (§3). The 0.1 seam it used to seal is open:
  fallback, a thin foam ring on its outer face (§6.2) [TBD rig].

**Glow uniformity (WIP).** The corners are nearest the LEDs; the middle of the long sides will be dimmer.
- Test: desk rig with the real collar and plate.
- Fallbacks: a diffusing texture on the collar front face, then 2 more LEDs (2020) at the long-side midpoints.

**Perforation.** 4 × 13 holes Ø1.0, pitch 1.6 (web 0.6, coupon row F) in each wing.
- **Black acoustic mesh** (0.2) sits in a 0.2 recess of the plate back behind both strips.
- Left strip: the 2nd column, top row (x −20.16, y +9.6) is the **mic port**. The mic carrier is bonded over the top
  three rows; its front is **black solder mask over everything**, the ESD ground ring included (nothing bare visible
  through the 11 blind holes, no exposed copper 2 mm behind the port).
- **Pressing the wings means pressing on the grille** (the press zone is the perforation). Care: dry cloth only, no
  spray. Option: a hydrophobic acoustic vent membrane at the mic port.
- Right strip: all 52 holes open into the speaker plenum (41 mm²).

**Frame.** Opening 55.6 [TBD Q2] → 0.3 per side around the plate (§5.3 for the pressed state).

## 5. Floating plate (push-button), both variants

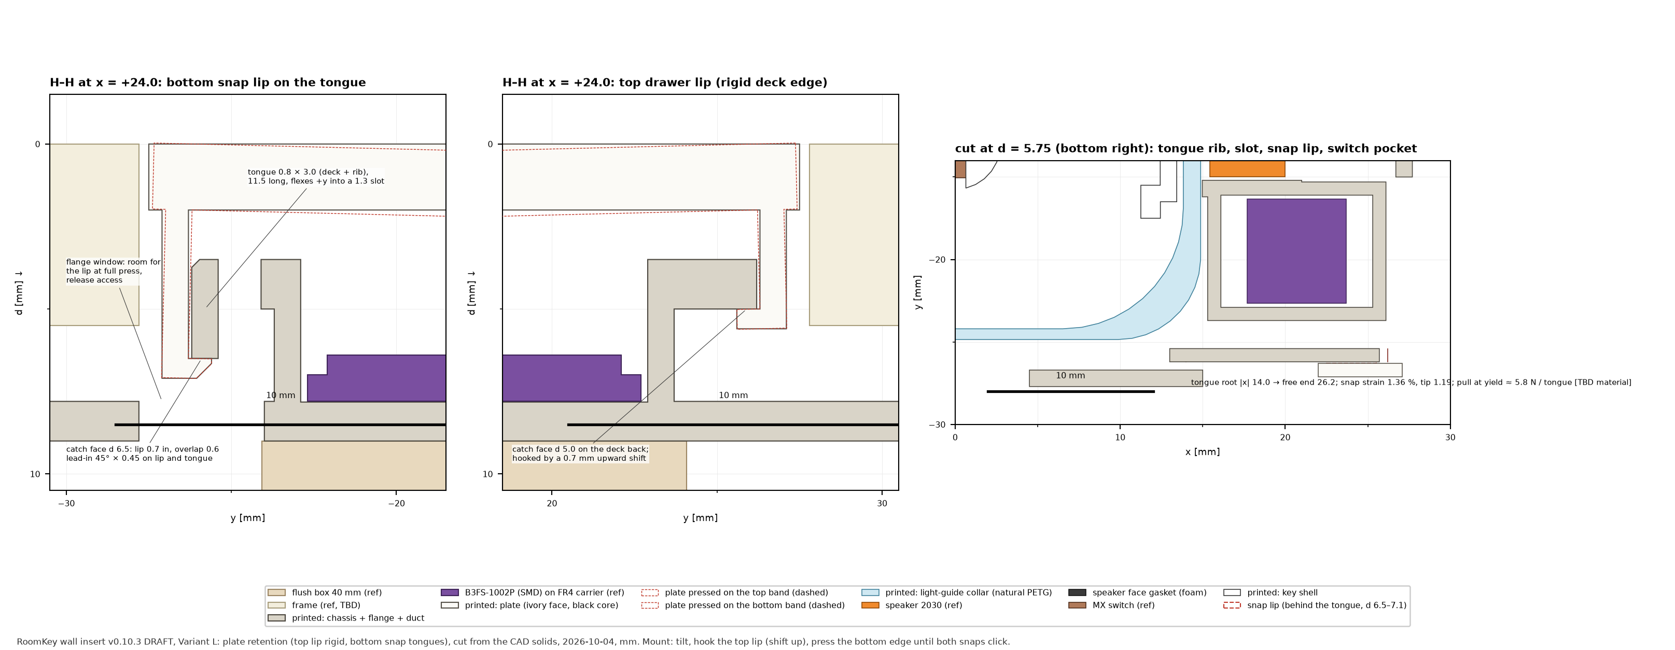
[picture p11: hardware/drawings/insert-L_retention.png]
retention detail


### 5.1 Switches, datum, tolerance, stops

**Switches.** 4 × **Omron B3FS-1002P** (SMD, flat) at (±20.7, ±19.5) [DS]: body 6.0 × 6.3, height 3.1 ± 0.2,
plunger Ø3, OF 1.47 ± 0.49 N, RF ≥ 0.49 N, PT 0.25 +0.2/−0.1, 300 k operations, 1–50 mA at 3–24 V DC, silver
contacts, bounce ≤ 5 ms.
- Each is reflowed onto an **FR4 carrier 8.8 × 6.4 × 0.8 with a flat back**. The pads are cut to ±4.4 (Omron's
  land pattern reaches ±4.8): the carrier cannot be wider, because its pocket wall would hit the plate skirt. The toe
  fillet is only 0.4 → check the joints on coupon row D.
- Two plated wire holes sit 2.0 mm off-centre towards the plate centre, 1.2 apart along y, under the switch body
  (≥ 0.7 from the pads, front side tented). The two wires are soldered **from the back**; their joints sit in a
  1.6 × 2.6 slot in the flange. The slot stays inside the carrier pocket and reaches r 27.1, so the wires drop into the box (inside Ø58 [TBD Q5]), not
  onto its rim.
- The carrier goes **in from the front** (plate off) and rests on the **flange front face = the datum** around the
  slot. Glue dot. Nothing (no solder) lies between the carrier and the datum.
- In the print the datum is the downward-facing roof of the carrier pocket: a 9.2 mm bridge. Its sag is in the chain.
- The switches are the travel stops. Nub Ø2.5 × 1.6 on the plate back; nominal nub ↔ plunger gap 0.30.

**Nub-gap chain** (the switch cannot pre-click unless the gap goes below −0.15):

| contribution | ± |
|---|---|
| plate: nub tip ↔ lip catch faces (print Z) | 0.10 |
| chassis: deck back / tongue back ↔ flange front (print Z) | 0.10 |
| FR4 carrier 0.8 ± 10 % | 0.08 |
| B3FS height 3.1 [DS] | 0.20 |
| solder under the SMD switch + glue line under the carrier | 0.05 |
| carrier seat printed as a bridge (sag) | 0.05 |
| plate seating on lips / snaps | 0.05 |
| **RSS / worst case** | **±0.27 / ±0.63** |

- **RSS:** gap 0.03 … 0.57 → never pre-actuated.
- **Worst case:** gap −0.33 … 0.93 → a single switch can pre-click or click late.
- **Therefore every switch is checked at assembly** (§11) and corrected with **0.05 mm polyimide shims** under its
  carrier (less gap) or by sanding its nub (more gap).

**Travel.**
- Click after ≤ 1.02 at a switch (RSS). Stop after ≤ 1.12 (incl. 0.1 seating allowance), ≤ 1.32 at a plate corner.
  The plate back stays 0.18 off the deck.
- Worst-case stack: a late switch clicks only after 1.38, but a plate corner lands on the deck after 1.50 (corner /
  switch travel ≈ 1.14) → pressed at the corner, that switch may **not** click. The per-switch check finds it; a shim
  fixes it. The deck is the secondary stop that protects the switches.

**Press force** (model `press_force()`): the plate tips about the easiest supporting line of its lip contacts.
Switches that are touched but have not clicked add their rising pretravel force; the preload pads are included:

| press point | nominal | switches clicking |
|---|---|---|
| wing centre (left / right) | 2.2 / 2.3 N | 1 |
| wing next to the key | 2.4 N | 1 |
| wing outer edge | 2.0 N | 1 |
| top / bottom band centre | 2.0 / 2.0 N | 1 (two diagonal lines tie) |
| wing top / bottom quarter | 1.9 N | 1 |
| corner (−24, 24) | 1.6 N | 1 |

- Range 1.6–2.4 N nominal, ≤ 3.1 N at OF max. The key needs ≈ 1.1 N at its centre.
- **One switch clicks** at every tested point; pressing on to the stop may click a second one. The four are in
  parallel, so PLATE sees one closure either way (bounce ≤ 5 ms < the ES75's 20 ms minimum command [DS]).
- Life: 300 k operations per switch; presses spread over four switches.

**Abuse.** A 30 N palm slap, worst case on **one** switch, vs SW_MAX_FORCE 20 N [TBD — Omron publishes no static
load]. Test: coupon row D, 30 N on one cell for 1 min, then it must still click at the same force. Fallback: a printed
stop ring around each nub, sanded to land 0.1 after the click.

### 5.2 Preload (anti-rattle)

The nubs do not touch the plungers at rest. Three soft PU pads keep the plate on its lips:
- 5 × 3 × 2.5, extra-soft, CLD at 40 % ≈ 10 kPa [TBD];
- positions (−21, −12.9), (21, ±12.9), in 0.5 pockets in the deck;
- 0.5 compressed at rest → **0.22 N**, 5 × the plate weight; included in the press forces above.

They are **not seals**. Fallback: leave them out (0.3 mm of free play), or cut them smaller. Coupon row D has one.

### 5.3 Retention, location, frame rims

**Top edge.** A rigid drawer lip (three segments, 0.7 inward, catch face d 5.0) hooks behind the deck's rigid top
edge with 0.6 overlap.

**Bottom edge.** Two snap lips (|x| 22.5–25.5, catch face d 6.5, 45° × 0.45 lead-in) clip over two **flexible deck
tongues**.
- Tongues: 0.8 wide in the deck plane, 3.0 deep, free from the slot's round end (x 14.65) to 26.2 → **11.55 long**;
  0.25 lead-in on the front-outer edge. They flex in y, i.e. in the layer plane of the print.
- Snap at the lip end nearest the root: **root strain 1.36 %** (limit 1.5 %, E 2.0 GPa [TBD]). The tip deflects 1.19
  into a 1.3 slot and clears the switch pockets by 0.52.
- Forward stiffness 13.2 N/mm. Pull on the bottom edge ≈ **5.8 N per tongue at yield** (12 N for both). The frame
  covers the plate edges. Coupon row D pull test.

**Location.** Every skirt overlaps the deck edges by 0.7 with **0.1 clearance** → the plate is located ±0.1 in x and
y (+ print tolerance).
- When the plate tips, the skirt on the **pivot side** comes to ≈ 0.03 from the deck edge (CAD "plate without lips ↔
  chassis"). With print tolerance it may touch there, where the relative motion is ≤ 0.1 mm: friction near the hinge,
  not a stop. Test: the first **full-size** plate on the printed chassis (coupon row D tips about an 18 mm base and
  cannot reproduce this), press the far edge 20 ×: it must click and return without sticking. Fallback: sand the
  skirt's inner face (location ±0.15, shadow gap ±0.24 RSS).
- These 0.1 mm fits (skirt ↔ deck edge, collar seat, rims ↔ frame) sit in the first 7 layers of the chassis print:
  **elephant-foot compensation on** (≈ 0.1) in the slicer, or a 0.3 × 45° chamfer on those bed edges.

**Plate ↔ frame.** 0.30 nominal at rest, ≥ 0.10 with frame and plate at their limits. **Pressed at an edge**, the
plate's front edge moves outward: CAD 0.16 at the RSS stop → with both ±0.1 off-centre ≈ −0.06 (touch). Test on the
wall-fit prototype; fallback: chamfer the plate's front edge 0.2 × 45° and recut the rims to the measured opening (Q2).

**Mounting (bench).**
1. Tilt the plate **≥ 6°**, bottom edge forward (at 4–5° the mic carrier touches its pocket wall).
2. Shift it up 0.7 and push the top edge in; let it drop → the top lip hooks.
3. Press the bottom edge until both snaps click.

**Release** (insert out of the box only).
1. Slide a 0.5 mm feeler gauge in sideways between the bottom skirt (ends at d 4.2) and the flange, at |x| 15.5–21.5.
   The window on the tongue's outer face is 6.0 × 2.3.
2. Push the tongue inward; lift that corner. Repeat on the other side.

The flange has a window at each snap so the lip has room at full press.

**Frame rims.** 8 rims (|along| 4.5–15 on all four sides, 1.0 thick, d 3.5–7.8) stand in gaps of the skirts and the
top lip.
- They reach **2.0 mm into the frame's opening tunnel** [TBD].
- Their outer face sits at opening/2 − 0.1 and is cut to the **measured** opening (Q2).
- They locate the frame ±0.1. **They do not hold the frame forward** (§7).

## 6. Audio, light, sensors

### 6.1 Microphone
**Carrier.** An I²S MEMS mic, bottom port, on an **8 × 8 × 0.8 carrier PCB** (custom, black solder mask, stack 2.6
[TBD]).
- Parts: INMP441 is obsolete; ICS-43434 is not recommended for new designs; SPH0645LM4H-B is a candidate. Use whichever
  is purchasable; only the footprint changes (Q10).
- **Bonded to the plate back** over the port with a die-cut PSA ring (0.1). This seals the port without any gasket
  force; the carrier moves with the plate.
- The chassis gives it a clearance pocket: 0.35 around, a closed floor behind its maximum travel (CAD ≥ 0.26 at the
  worst press).

**Wiring.** 5 × AWG32 silicone wires (3V3, GND, SCK, WS, SD; L/R tied low on the carrier) leave the carrier
**sideways at its bottom edge** in a flat S-loop into a **3 × 3 wire well** beside the pocket (x −24.5…−21.5,
y 2.3…5.3), walled down to the flange and open into the box. No wire lies between the carrier and a floor, so a press
never squeezes them. A **removable foam plug** closes the well (it would connect the front volume to the box), so the
plate can come off tethered, with the 30 mm service loop in the box. Wire flexing is part of life test R8.
- The mic parts differ in more than the footprint: SPH0645 has its own I²S data format and needs BCLK ≥ ≈ 1 MHz, so the
  firmware changes with the part (Q10).

**Mic path — BLOCKED-ON-DATA.**
- *Assumption:* the Ø1.0 × 2 mm port and the 0.1 PSA ring on an FDM surface give a usable response.
- *Test:* desk rig with `tools/mic_check.py` through a printed plate coupon. Pass: ≤ 6 dB below the bare mic, no peak
  > 6 dB below 4 kHz.
- *Fallbacks:* ironed seal land, a 0.5 mm die-cut gasket, port Ø1.2.

### 6.2 Speaker and acoustics
**Mounting.** Waveshare 2030 (20 × 30 × 5.5, grille on a 20 × 30 face [DS]).
- It stands on its edge right of the collar: x 15.4–20.9, d 5.6–25.6.
- It goes **in from behind**. Its front edge rests on the 0.6 mm plenum floor; **snap hooks** (0.4, 45° lead-in) on
  the cradle ribs catch its back edge; the hooks are 1.2 thick (tip 0.8 after the lead-in).
- A **foam strip** (0.8 → 0.55) between the collar and the speaker's back face pushes it +x onto the **foam frame on
  its grille face** (0.8 wide, 0.5 → 0.3). Both are compressed in the CAD position.
- Sliding the speaker 20 mm in over pre-compressed foam can shear it. Assembly: cover both foams with 0.1 mm PET film,
  slide the speaker in, pull the films out. The back strip is backed by the rear wall only to d ≈ 17.8; behind that it
  presses on the speaker alone (v0.6: extend the backing).
- **Real part (owner's photo, 2026-10-02) — v0.6 must fix the mounting:**
  - Confirmed: the Waveshare 2030 pair on one 4-pin PH1.25 connector.
  - **Measured: 19.32 × 29.81 × 4.57** (owner's calipers; vendor drawing 20 × 30 × 5.5). It is 0.93 thinner, so the
    duct moves in, but never inside the deck mouth (that left a 0.03 sliver; the channel is now 3.87 wide). The duct
    now stays 1.04 mm from the screw domes (was 0.87); `validate()` 0 errors, wall check OK.
  - The outline is **almost a stadium**: near-semicircular ends, straight sides only ≈ 10.5 long. The hooks sit at
    y ±14.6…15.0 on the back edge, that is, at the corners of the CAD's box. There the real speaker is not present, so
    the hooks catch nothing.
  - A **white ring is already on the grille face** (≈ 1.4 wide from the photo). It is **paper-thin**, and 4.57 includes
    it, so it is not a compressible gasket: the planned foam face gasket stays. If it is the release liner of an adhesive
    ring [TBD], the speaker can be bonded to the duct face. That would hold and seal it at once, with the hooks only as
    a backup.
  - The wire leaves at the **centre of a short end** through a small tab (≈ 3.4 wide, 1.8 overhang from the photo).
  - v0.6: a stadium-shaped reference body, hooks on the straight part (|y| ≤ 4), a tab notch, and back foam / gasket
    retuned to the real thickness.
  - Still [TBD]: whether the white ring is a liner over adhesive.

**Sound path.** Grille → face gasket → 3.1 mm channel → plenum (a 1.5 mm recess in the deck) → 52 holes (41 mm²).

**Leak paths (stated honestly).** There are no gaskets between plate and chassis, so the plate–deck gap is part of the
speaker's front volume. It opens:
- to the room: strip holes 41 mm², the shadow gap ≈ 140 mm², the frame gap;
- to the box, through small slots: key ↔ collar 0.25 (into the well, then the switch-plate cable slot), the collar
  seam (sealed by the continuous glue bead), the mic wire hole (silicone), the switch wire slots (covered by the
  carriers).
- The speaker's back is its own sealed cavity, so a leak into the box costs little. The mic sits in the same front
  volume as the speaker, 42 mm away, and also near the shadow gap: echo coupling is a firmware matter (half duplex).

**Estimates** [TBD, measure through the printed duct + plate + mesh].
- The quarter-wave of the ≈ 22 mm path is ≈ **3.9 kHz**, inside the chime band (2.5–4 kHz).
- **SPL at 1 m ≈ 65–71 dB**: 1.0 W, +3 dB for the wall (half space); sensitivity 82–88 dB/1 W/10 cm is not published.
  Target 70–75 (Q6).
- **Fallback:** the RoomKey is the *secondary* chime; the main bell and HA media players carry the loud signal.

### 6.3 LEDs
4 × SK6812 MINI on 0.8 carriers (3.5 × 3.5, the LED's footprint), 5 V, daisy-chained with 3 wires per hop through the
rear-wall windows. Data from IO4 through a 74AHCT1G125 on the hub.
- **Owner's parts, 2026-10-03:** the glow ring stays. The owner ordered **WS2812B-MINI 3535** (RGB, 3.5 × 3.5 × **2.0** [DS
  vendor]).
  - The windows deepen with LED_T, and the switch plate gets 4 corner notches (the 2.0 LEDs reached 0.1 into it).
  - 0 collisions in L/S/kit; wall check OK.
  - Kit prototype: wires soldered straight to the LED pads, chain BR → TR → TL → BL, data from IO4 at 3.3 V into
    5 V LEDs, no level shifter [TBD: add one if they flicker].
- A 100 nF per LED does not fit on a 3.5 × 3.5 carrier. The design puts 100 nF + 10 µF at the chain start on the hub and
  keeps the hops short. If the desk rig shows flicker: wider carriers with an 0402 beside the LED [TBD, check the
  windows in CAD first].
- The LEDs (r 28.1) are, after WAGO 4/5 (r 28.18), the tightest radial items (28.5 allowed at Ø58). If Q5 finds the
  box tighter: 2020 LEDs on the same centres (r 27.4); the WAGOs → the 47 mm box with WAGOs lying flat.
- Firmware caps brightness at 45 % (0.12 W avg, 0.72 W strobe). **Requirement:** the ring must reach HA only through
  that cap (§8.2).

### 6.4 Deferred sensors
VEML7700, SHT31-D and the LD2410C/B radar do not fit: the wings are full, and the LD2410C is 16 mm wide vs a 13.07 mm
wing. Planned for v1.

**Humidity/temperature sensor IN THE FRAME (owner's idea, 2026-10-03; kit prototype, WIP).**
- The SHT31-D breakout lies **flat under the bottom border of the (practice) frame**, chip side forward, 0.8 below the
  face skin. Vents: 3 × 3 Ø1.0 through the face over the chip, plus 3 air inlets in the bottom skirt — **both on the
  frame's centre line** (owner, 2026-10-04): the board sits 2.92 left of centre so that its chip is at x 0. The frame's tunnel
  wall is thinned to 0.7 and its skirt to 0.6 over the board's length. Along the slope the board does not fit (its
  thickness at the tilt).
- Its 4 wires run under the frame's tunnel wall and through a **Ø2.5 hole in the kit chassis' flange at (0, −27.0)**
  (rim gap, inside the box opening) into the box, then with the key cable to SDA/SCL/3V3/GND.
- Outside the warm box, in room air, below the electronics: the best place available.
- **The light sensor does not fit the frame:** its board is 16.4 wide and the border holds about 11 (the middle bar of
  a 2-gang frame 15.4). It needs the small chip (VEML6030) later.
- Check: 0 collisions; board ↔ frame 0.2, ↔ chassis 1.0.

**Light sensor (owner, 2026-10-03): it should report how bright the room is** (to HA), among other things. The v1
concept (WIP):
- *Part:* a VEML6030 (same family as the VEML7700, 2 × 2 × 0.65) on the custom mic carrier behind the left strip. The
  VEML7700 chip on the breakouts is 6.8 × 2.35 × 3.0, too tall.
- *Window:* a **translucent dot** (natural PETG, co-printed like the glow rim) in place of one or two strip holes. Bare
  Ø1.0 holes would give a narrow, strongly attenuated view; the dot diffuses and widens the view, which suits a
  room-brightness reading.
- *Accuracy:*
  - Calibrate once against a lux meter.
  - Relative brightness is then reliable; absolute lux ≈ ±20–30 %, like any wall sensor (it sees the room from the wall).
- *Crosstalk:* display and glow ring are ≥ 15 mm away and the plate core is black. If needed, the firmware reads during
  a short dim.
- *Wiring:* I²C (SDA, SCL) adds 2 wires → 17 [TBD RoomKey software].

## 7. Chassis, flange, box

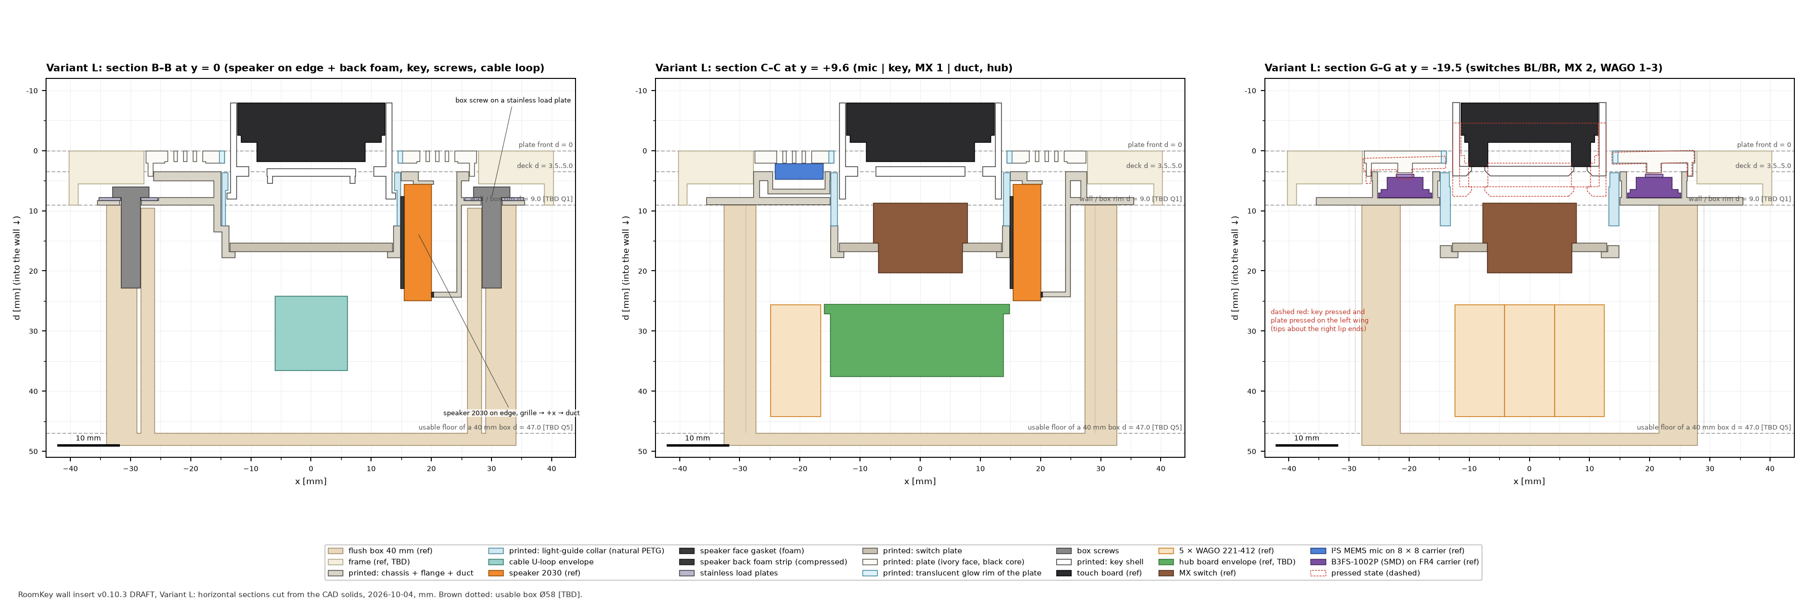
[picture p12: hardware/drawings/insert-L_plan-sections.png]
plan sections, Variant L


**Chassis.** One printed part, front down (§10), **black UL94 V-0 filament (mandatory)**, so the plate–deck gap stays
dark and a fault in the box cannot spread. It contains:
- deck 52.4 × 52.4 with the collar seat, the switch pockets (flat seats, wire slots) and the mic pocket;
- plenum with floor, channel, speaker cradle with hooks;
- rear wall behind the collar (LED windows, island ribs), ledge + bosses for the switch plate, hub posts, cable anchor;
- **flange 71 × 71 × 1.2** with 3.6 × 9 slots for the box screws at (±30, 0), load-plate recesses and snap windows;
- 8 frame rims, 3 pad pockets and the mic wire well.

**Box screws.** 2 × 3.2 × 15 device screws on **stainless load plates**.
- Load plate: 9.8 × 8.8 × 0.5, in a 0.5 recess of the flange front face, x 25.5–35.3.
- **Snug by hand with a screwdriver, no power tool.** At ~0.2 N·m ≈ 250 N → 4.6 MPa on the PETG (limit 5 for
  permanent load). Nothing limits over-torque mechanically, and electricians often drive device screws at 0.5–0.8 N·m
  (≈ 11 MPa). The flange is also the switch datum, and boxes often sit 1–3 mm recessed or skewed in the plaster.
- **BLOCKED-ON-DATA:** *assumption* — the box rim is flush and flat within ±0.3 and the screws are only snug; *test* —
  repeat the per-switch click check **after** wall mounting (§11); *fallbacks* — the switch program's steel support ring
  as the mounting base (it bridges a recessed box), or steel compression sleeves under the load plates (v0.6). Q1b asks
  for rim offset, flatness and the box type.
- The stack under the frame is flange 1.2 + head 1.8 = 3.0, vs 3.5 free [TBD Q2]; low-head screws (≤ 1.8) are in the
  BOM. Fallback if less is free: the switch program's own steel support ring (Q2).

**Box interior** [TBD Q5]. Usable Ø58; 4 screw domes reaching to r 26.
- Every part in the box is checked against both. The closest are the duct (0.87 to a dome), the WAGOs (1.1 to a
  dome; r 28.18) and the LEDs (r 28.1 ≤ 28.5).
- **Fallback:** up to 1 mm tighter → narrow the duct channel (3.1 → 2.1) and the hub (−2 mm), 2020 LEDs, WAGOs flat in
  a 47 mm box. Tighter still → this box type is replaced (electrician).
- Hollow-wall boxes and old boxes **without screw domes** (devices held by claws) are part of Q5/Q1b; for them the
  insert needs the program's support ring with claws (fallback, not modelled).

**Heat in the chamber** ≈ 0.32 W (buck loss, amplifier idle, glow LEDs). PSU and relay losses are elsewhere.

**Frame retention [TBD Q2].** If the frame was held by the old rocker (common in 55-type programs), the rims locate it
but do not hold it forward. At **socket** positions the frame is usually clamped by the socket's centre screw, so this
fallback is near-certain for Variant S. Fallbacks, in order:
1. Clips on the rims, once the frame's inner edge is measured.
2. Thin removable foam pads between the frame back and the wall.
3. The program's steel support ring, if its claws hold the frame.

## 8. Electrical (SELV side only)

### 8.1 Interface, terminals and marking
**Pigtail.** 3 conductors from the hub (H05V-K 0.5 mm², 15 cm): **+12 V, 0 V, PLATE** in L; +12 V and 0 V in S.
- The electrician joins them to the SELV cores with **WAGO 221-412**. Five are modelled in the box (standing,
  d 25.6–44.2): 3 SELV joints, the PE cap, a cap for the spare core.
- The PE of any cable in the box stays PE: capped in a WAGO 221, never used as a SELV conductor, never cut off.
- The insert can be pulled without touching any 230 V **if the installation is correct and was verified** (§9.1):
  there is none in this chamber by design. After a suspected miswire, treat the insert as live (matrix below).

**Conductors — BLOCKED-ON-DATA.**
- *Assumption:* the solid 1.5 mm² cores (11 mm stripped) bend from the box entry to the WAGO entries in the 2.8 mm
  behind the WAGOs and the gaps beside them.
- *Evidence against it:* a solid 1.5 mm² core is ≈ 2.7 mm over its insulation and enters the WAGO axially; a 90° turn
  needs ≈ 5–6 mm. The NYM sheath end (Ø ≈ 10–11), the box entries and the core reserve are not modelled, and loose
  WAGOs on stiff cores push on the hub and the insert. **Expect the fallback.**
- *Test:* wall-fit prototype (§13: on the desk, a new loose 40 mm box, a spare frame, a real NYM-J 5×1.5 — never at a
  live position).
- *Fallbacks:* **a 47 mm deep box (the planning default)** with the WAGOs lying flat behind the hub, or push-in PCB
  terminals for 1.5 mm² on the hub with defined conductor exits instead of the pigtail.

**Marking (mandatory).**
- Every cable converted to SELV: **"SELV 12 V DC — kein 230 V"** at both ends, a SELV marker sleeve on every
  converted core at both ends, and the circuit documentation (test record).
- On the insert (flange label and pigtail tag): the class III symbol and **"12 V DC SELV only, max 15 V"**.

**230 V misconnection (what really happens).** A converted switch leg looks like a 230 V leg. The **1 A slow-blow,
250 V AC entry fuse** sits in the pigtail **+12 V only** (breaking capacity ≥ 1500 A, UMT-H class, ≥ 3 mm creepage on
the hub [TBD part]); PLATE and 0 V are not fused.

| someone connects L to … | return path | what happens |
|---|---|---|
| +12 V | N or PE on 0 V (low impedance) | the entry fuse opens (or the MCB trips first); the TVS fails short; the hub is destroyed |
| +12 V, PLATE or 0 V | **the lamp** ("old switch leg restored": L on one core, switched L on another), 0.02–0.3 A | **no fuse opens.** The TVS conducts on every half-wave (several W) until it fails; the lamp may glow; after that the **whole SELV side — hub, key cable, board — sits at line potential** |
| PLATE or 0 V | N or PE | no fuse in that path: the MCB clears the short through the hub copper |
| any core | none (the others open, or only the isolated SNT61) | nothing flows, nothing opens — the RoomKey even keeps working, **with every SELV part at line potential**; only an RCD protects a person |

What protects people is therefore **not** the hub: it is (1) the marking, (2) the electrician's **verification before
connecting** — each SELV core measured against PE and the other circuits (no voltage), insulation resistance SELV ↔
PE / 230 V at 250 V DC ≥ 0.5 MΩ with the pigtail disconnected (0100-600) — and (3) an **RCD 30 mA on the circuit**,
a precondition for every topology (§9.1). The V-0 chassis (rated at ≤ 0.8 mm, §10) is a mitigation, not a guarantee.

### 8.2 Hub (custom board, envelope x −16…14.8, y 3…22, d 25.5–37.5 [TBD])
```
pigtail +12 V ─ entry fuse 1 A T 250 V AC ─┬─ SMBJ24A (does not conduct at a 24 V source)
                                           ├─ PTC 50 mA hold, V max ≥ 30 V ─► 4 × B3FS in parallel ─► PLATE out (relay input, §9)
                                           │                                                          ├─ PLATE TVS (SMBJ24A), 4.7 k bleeder (L and S)
                                           │                                                          ├─ 47 k ─ NPN (10 k, 100 nF) → IO3 (PLATE_SENSE, active low)
                                           │                                                          └─◄ Schottky ◄─ P-FET ◄─ one-shot ◄─ 20 ms qualifier ◄─ 100 k pull-down ─ IO5 (RELAY_DRIVE, L only)
                                           └─ eFuse (60 V class, ILIM 0.43 A ± 7 %, OVLO 17 V, soft-start [TBD part]) ─ 2 × 100 µF/25 V ─ TSR 1-2450 ─ 5 V
                                                 (hub rail; it also feeds the RELAY_DRIVE P-FET)                         ├─ Schottky ─► board VBUS
                                                                                                                           ├─ 470 µF + MAX98357A (SD_MODE: resistor from 5 V)
                                                                                                                           └─ SK6812 chain (IO4 → 74AHCT1G125 → 330 Ω)
IO8 (I²S WS, strapping): 10 k pull-up on the hub → ROM download mode stays reachable
ESD: TVS on +12 V and PLATE; TVS array on IO3/IO5/BOOT and on the I²S lines IO7/IO8/IO17; 100 Ω series on the I²S lines
```

**FMEA of the +12 V and PLATE nodes** (Variant L):

| fault | light | ESP / key | note |
|---|---|---|---|
| ESP crashed, unflashed, or the board missing | **works** | dead | the B3FS switch 12 V into the relay input |
| any short behind the eFuse (caps, TSR, amp, LEDs, board) | **works — if** the SNT61 holds 12 V at the eFuse's maximum 0.46 A (BLOCKED-ON-DATA, below) | dead | |
| eFuse input capacitor or eFuse input short | dead | dead | an MLCC that cracks is a classic short: on the +12 V node, ahead of the limit |
| SMBJ24A short | dead | dead | +12 V collapses (SNT61 shuts down or the entry fuse opens) |
| a 24 V SELV source fitted by mistake | **works** (B3FS at their 24 V limit, ES75 12–24 V) | off (OVLO 17 V) | the label says "max 15 V"; both TVS are SMBJ24A and do not conduct at 24 V |
| ESP resets, boot loops, power returns | **no pulse** | — | IO5 floats then [DS]: pull-down + 20 ms qualifier; test R12 |
| PLATE TVS short | dead | works | PLATE clamped, the PTC trips |
| RELAY_DRIVE P-FET short (D–S) | toggles once, then dead | works | PLATE held high: no further edges; the Schottky stops back-feed |
| a B3FS stuck closed | toggles once, then dead | works | same |
| entry fuse or PTC open | dead | entry fuse: dead / PTC: works | |
| PLATE shorted to 0 V | dead | works | one pressed switch carries the source current for the PTC trip time (≤ 1 s): contact wear, not a hazard |

So the light survives any **software** fault and — if the SNT61 holds — any fault **behind the eFuse**, but not a
short in the parts on the +12 V / PLATE nodes — like any electronic push-button. Full independence would need the
ES75's internal control voltage with an isolated plate contact: a hub redesign (isolated switches, opto input), not in
v0.5.

**Hub short vs light — BLOCKED-ON-DATA.** *Assumption:* the SNT61 keeps 12 V at 0.46 A (eFuse max) + PLATE, 94 % of its
0.5 A rating; Eltako publishes no shut-off threshold (Q4f). *Test R14:* hard short on the hub rail; the plate must still
toggle the relay 20 ×. *Fallbacks:* firmware never runs chime and strobe at full power together (peak ≈ 0.30 A) and
ILIM 0.35 A; or the 10 W SNT61 (0.83 A). The eFuse is checked against the hub's summed peak (0.37 A at 12 V: chime +
strobe + Wi-Fi TX) with its ±7 % tolerance (0.40 … 0.46 A).

**Relay drive at reset.** IO5 is MTDI, a strapping pin with **no pull at reset** [DS ESP32-C6 Tab. 3-1], and the IMU's
INT1 on the same net is high-Z. During reset, the bootloader or a boot loop, IO5 floats. So the drive input has a
100 k pull-down and a 20 ms qualifier ahead of the one-shot: only a deliberate level fires it. *Test R12:* 100 power
cycles, 100 resets, a forced boot loop, the board missing — no relay pulse. *Fallback:* arm the one-shot from a second
line (a 15th wire).

**GPIO map** [DS vendor schematic]:
- The header gives IO1/IO2 (they carry the LCD SPI and TF lines), IO3 (10 k pull-up), IO4, IO5 and IO6 (IMU
  INT1/2), IO7, IO8, IO16/17 (UART0; 499 Ω in series on IO16), SDA/SCL, ESP_RST, VBAT, USB and BOOT.
- The insert uses IO3, IO4, IO5, IO7, IO8, IO16, IO17 and BOOT (14 cable wires). No I²C expander is needed. IO1/IO2
  are unused by the insert but not free; IO6 is free but not in the cable.

**Firmware requirements (WIP — the firmware is not changed in this revision).**
- IO3 becomes PLATE_SENSE (today the board package drives IO3 low for the mic L/R; L/R moves to the carrier).
- **Never enable the IMU's INT1** (it shares IO5 = RELAY_DRIVE; tap/motion events would fire the relay one-shot).
- **Never insert a microSD card** (IO3/IO4 are the TF slot's lines).
- GPIO16 carries the ROM boot log into the amp's DIN; BCLK/WS are idle during boot, so the amp stays silent [DS,
  verify on the rig]. The amp's SD_MODE gets a resistor from 5 V on the hub (its internal 100 k pull-down would keep
  it off; value sets the channel — (L+R)/2). There is **no hardware mute**: a hung CPU with looping I²S DMA plays a
  tone until the watchdog resets it (accepted risk; a 15th wire to IO6 would allow a gated SD_MODE).
- The glow ring reaches HA only through its 45 % cap (`internal: true` or colour correction), strobe included.
- A key action on Home waits 250 ms and is dropped if PLATE_SENSE fires (palms and elbows hit both — desk-rig test
  with a flat hand, R11).
- The ESP never pulses the relay within 1 s after a plate press, and masks PLATE_SENSE during its own pulse.
- Relay pulse 100 ms, lock-out 400 ms (ES75: 20/300 ms [DS]).
- Only **"toggle"** is offered for the room light; the north-star "key press = all lights" **excludes** it, because
  the ESP cannot know its state and a toggle could switch it on (§9.4, Q3c).

**Area check** (estimate): parts 512 mm² × 1.3 routing = 666 mm² vs 557 mm² (back side) + 270 mm² (front strips
beside MX1, ≤ 7.7 tall). Fallback: a second board level behind the first (d 37.5–42.5), beside the WAGOs; it stays
inside the 40 mm box. Part numbers for FETs, Zeners, PTC, ESD arrays, eFuse and the entry fuse: Q10.
- The 5 V crest current during a ring (TX + amp + strobe) is ≈ 1.0 A, the TSR's rating: 470 µF low-ESR at the amp,
  and scope 3V3 on the rig during chime + TX + strobe (two Schottkys in the VBUS path leave ≈ 4.3 V for the board's
  LDO).

### 8.3 Power

| at 5 V (estimate, bench [TBD]) | avg | peak |
|---|---|---|
| ESP32-C6 + LCD + touch, Wi-Fi **without** power-save (the firmware sets `none`) | 0.65 W | 1.95 W (TX 354 mA [DS]) |
| MAX98357A + 2030 (chime, capped to 1.1 W) | 0.05 W | 1.10 W |
| glow ring (45 % / red strobe) | 0.12 W | 0.72 W |
| misc | 0.01 W | 0.02 W |
| **at 12 V (buck 85 % at light load [TBD])** | **0.98 W** | **4.46 W** of the 6 W SNT61 |

- **Standby per room ≈ 2.3 W** continuous (ES75 1 W [DS] + SNT61 0.1 W [DS] + insert 0.98 W through the SNT61 at
  81 % [DS]).
- **Start-up — BLOCKED-ON-DATA.** The SNT61 switches off on overload and restarts [DS]. *Assumption:* it starts into
  the eFuse's soft-start (2 × 100 µF + TSR). *Test:* bench cold start, 20 ×. *Fallback:* slower dV/dt, less bulk
  capacitance.
- **Key self-heating:** ≈ 0.65 W in the key → ΔT ≤ 27 K on the key surface (upper bound, no conduction into the
  chassis). **Pass: ≤ 15 K above ambient** on the key front after 1 h (thermocouple). Fallbacks in order: Wi-Fi
  `power_save_mode: light` with an intercom-latency test, then backlight dimming (≈ 0.1 W).

### 8.4 ESD/EMC concept (tests planned, not done)
The insert is class III and floating: there is no earth to dump a discharge into. The concept is distance and local
clamps.

**Distances.** The intent is that every conductive part is ≥ 3.5 mm behind any opening; not shown for the key's
glass/shell seam and the 1.0 mm shell wall at the shadow gap — those are test points. Known exception, the mic
carrier:
- The mic carrier sits directly behind a Ø1.0 port.
- It gets a ground ring on its front face (under the solder mask and the PSA ring), an ESD diode array and 100 Ω series resistors on SCK/WS/SD. Its ground
  returns through AWG32 in a 30 mm loop (≈ 50–80 nH), so the hub array also clamps IO7/IO8/IO17.

**Other lines.**
- BOOT: the board already has RC on it (10 k + 100 nF [DS]); a TVS at the hub is added.
- The long PLATE and +12 V lines are clamped at the hub.

**Tests.** ±4 kV contact / ±8 kV air at the key glass, the glass/shell seam, key shell, plate, perforations and gaps
(IEC 61000-4-2 levels, lab or borrowed gun). Pass: no reset, no relay pulse. Test the mic carrier first.

**Fallbacks** if it fails: an insulating acoustic spacer tube that puts the mic ≥ 3.5 mm back; a graphite-coated deck
front face tied to 0 V; larger distances.

### 8.5 RF
**Antenna position.** The chip antenna (PCB back, non-USB end) sits 0.3 mm in front of the plate at rest; pressed, it
is inside the plate aperture.

**Distances to metal** (check JSON):
- MX2 spring: ≈ 11.7 mm at rest, **≈ 8.1 pressed** — below the 10 mm wanted (the spring is 4.1 mm beside the chip in
  plan); the MX2 contact leaves and pins are closer still (the plastic housing: 9.0 / 5.0);
- the 14 cable wires at the header: ≈ 6–7 mm;
- speaker 2030: 15.7 / 14.7; LED carriers: 15.8 / 12.8; B3FS BL: 16.4 / 15.1;
- box screws: 32 mm; hub: 34 mm;
- a **metal** frame edge: 6.6 mm in-plane [TBD Q2] — below the 10 mm wanted;
- the board's own brass standoffs: 5 mm (given). Brass is metal at 2.4 GHz; **nylon** M2 screws at the bottom pair
  remove only the screw heads.

**Acceptance test R7.** RSSI bare board / in the key **with the cable wired** / in the wall, at rest and pressed, with a
hand on the key:
- pass = ≤ 6 dB loss and ≥ −70 dBm at the position.

**Fallbacks.**
1. Rotate MX2 so its contact leaves face +y (away from the chip); retune the board's matching network (C25 2.7 pF,
   C2 1 pF, C1 not fitted [DS schematic]).
2. An access point or mesh node in the room.

## 9. Installation (for the electrician)

**Owner's input 2026-10-03 (WIP, to be decided with the electrician; the owner will hire one):**
- The owner wants the whole system **behind one frame**, powered from the wall (blue/brown).
  - The printed insert stays **SELV-only** (E1): the mains side is a certified device, installed and connected by the
    electrician (E2).
  - A two-chamber box (S1/T2) is "hardly possible, rather not at all" at the owner's positions. So the **12 V supply sits
    outside the RoomKey box**, and the electrician picks one of three options from what Q3 finds:
    - a DIN-rail supply in the distribution board (T3);
    - a certified supply in an adjacent box behind a blank cover;
    - a supply at the lamp or ceiling box (T1).
  - In every case a SELV line runs to the RoomKey.
- **Shelly 1 Mini Gen3** as relay and supply? [DS]
  - **It supplies nothing:** the Shelly is fed from 110–240 V AC and has no low-voltage output, so a 12 V supply is still
    needed.
  - **Its SW input is at line potential** and must never be wired to the RoomKey (SELV).
  - Its relay is potential-free (8 A), so it could switch the light as a Wi-Fi relay at the lamp or junction box, with
    the RoomKey talking to it over the network. But then **software sits in the light path**, against the north star
    ("the plate switches the light without software"). That is the owner's call; Variant S already works this way.
- **Owner, later on 2026-10-03:** "RoomKey and relay in one common flush box", and something cheaper than the SNT61.
  - **Not in the RoomKey box:** relay and supply carry 230 V. A shared box would put 230 V next to the uncertified printed
    SELV device with its thin wires. A loose mains conductor or an insulation fault would then reach the touchable
    key/screen, and the box is full anyway. This is the one hard boundary (E1).
  - **What comes close, with the common 2-core switch leg (R1):**
    - At the lamp or ceiling box (230 V is there anyway), the electrician installs a certified 12 V supply plus a
      certified relay (e.g. a Shelly 1 Mini Gen3).
    - The two former switch-leg cores are converted to SELV (+12 V / 0 V, labelled, verified, §8.1, §9.1) and feed the
      RoomKey.
    - The RoomKey switches the light over Wi-Fi, so the light path holds software (owner's call).
    - This needs no new cable and no two-chamber box.
  - **Cheaper supplies:**
    - any certified, marked SELV 12 V (or 5 V) supply rated for flush boxes, chosen by the electrician;
    - a USB charging insert (5 V, Variant S);
    - for several rooms, one DIN-rail supply in the distribution board, if SELV lines exist.
    - Never open modules (HLK-PM01 class).
- **Owner's decision, 2026-10-03 (planning default, WIP): RoomKey only at positions with ≥ 2 coupled boxes**, e.g. a light
  switch above a socket.
  - The RoomKey replaces the switch.
  - The **certified 12 V supply goes into the socket's box**, installed and connected by the electrician. Likely a deeper
    box there: a socket insert plus a supply of ≈ 45 × 45 × 18 does not fit a 40 mm box.
  - **Only the SELV line passes the box connection.** The electrician makes sure no 230 V conductor can reach the
    RoomKey box (route, fix, cover the passage).
  - Variant L: the light relay (impulse relay or Wi-Fi relay) also sits on the 230 V side, behind the socket if it fits,
    otherwise at the lamp. The switch-leg cores leave the RoomKey box.
  - This is §9 topology T2/S1 with two standard boxes instead of one two-chamber box.

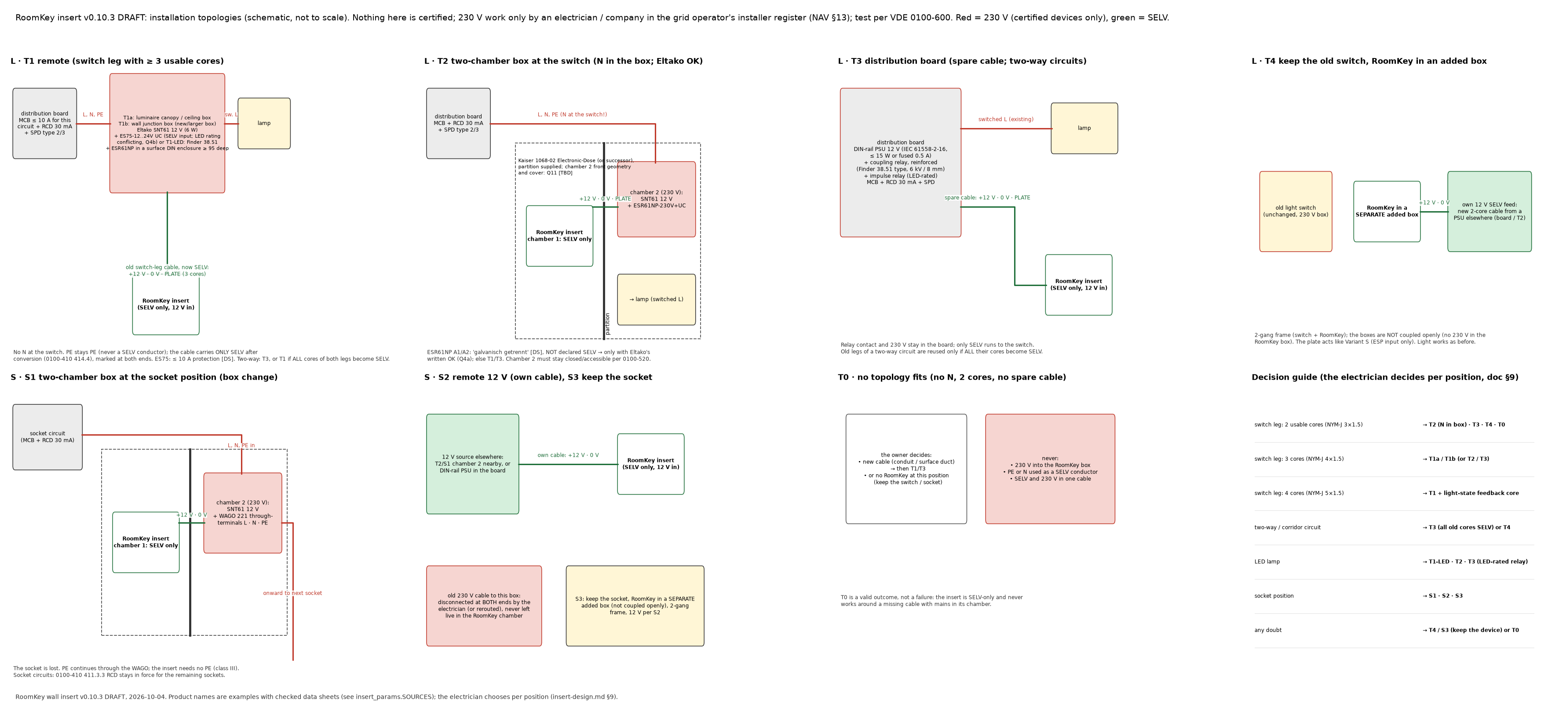
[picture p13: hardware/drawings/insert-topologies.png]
installation topologies


### 9.1 Common rules
- **Who:** a qualified electrician of an installation company entered in the grid operator's installer register
  (NAV §13).
- **Protection:**
  - **RCD 30 mA on every circuit involved — a precondition for every topology** (the misconnection matrix in §8.1 shows
    why); for new or modified lighting circuits it is required anyway (0100-410 411.3.4), for socket circuits too
    (411.3.3; S1/S2 modify them);
  - SPD type 2/3 as required by the Eltako data sheets;
  - older homes may need both retrofitted in the board — a real cost (§9.4).
- **Verification before connecting the insert** (0100-600, test record): each converted core measured against PE and
  against the other circuits (no voltage); insulation resistance SELV ↔ PE and SELV ↔ 230 V at 250 V DC ≥ 0.5 MΩ, with
  the pigtail disconnected (WAGOs open) so the hub is not stressed; then connect.
- **12 V source:**
  - a **safety isolating source** (IEC 61558-2-16 or equivalent); the Eltako SNT61 is class II to EN 60950, output
    ±1 % [DS], but its data sheet does not say "SELV" → Q4c;
  - **power-limited: ≤ 15 W, or fused ≤ 0.5 A at the source**. The SNT61-12VDC/10W (0.83 A, the current catalogue
    part) is ≤ 15 W and qualifies without a fuse.
- **Converted cables** carry only SELV (every non-PE core) and are marked (§8.1).
- **Coupled boxes:** neighbouring boxes joined by an open coupling (Verbindungsstutzen) count as one chamber. No 230 V
  may be reachable through the coupling from the RoomKey box: close the coupling, move the 230 V out, or this position
  becomes T2/T4 or gets no RoomKey.
- **Where SELV and 230 V leads share a box or chamber** (lamp box, T1 enclosure, chamber 2), the electrician applies
  0100-410 414.4.2:
  - SELV cores insulated for the highest voltage present and kept in their sheath up to the device, or separated;
  - SELV joints (e.g. the ES75's STOCKO adapter leads, the 0 V split) **in sleeving or in an insulating enclosure of
    their own** (a small separate SELV junction box), never loose next to 230 V terminals; adapter leads rated
    300/500 V;
  - through the Kaiser partition only through its intended passage (Q11).
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

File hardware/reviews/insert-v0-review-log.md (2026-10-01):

# Insert v0 — adversarial review log

Design: [`../docs/insert-design.md`](../docs/insert-design.md). Gate (from the brief): every criterion
≥ 8/10 from every reviewer, mean ≥ 8.5, zero open BLOCKER/MAJOR, in **two consecutive rounds by
fresh reviewers**; at most 6 rounds. Items blocked on real-world data count as resolved only if the
design handles them explicitly (assumption + fallback + question for the owner).
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

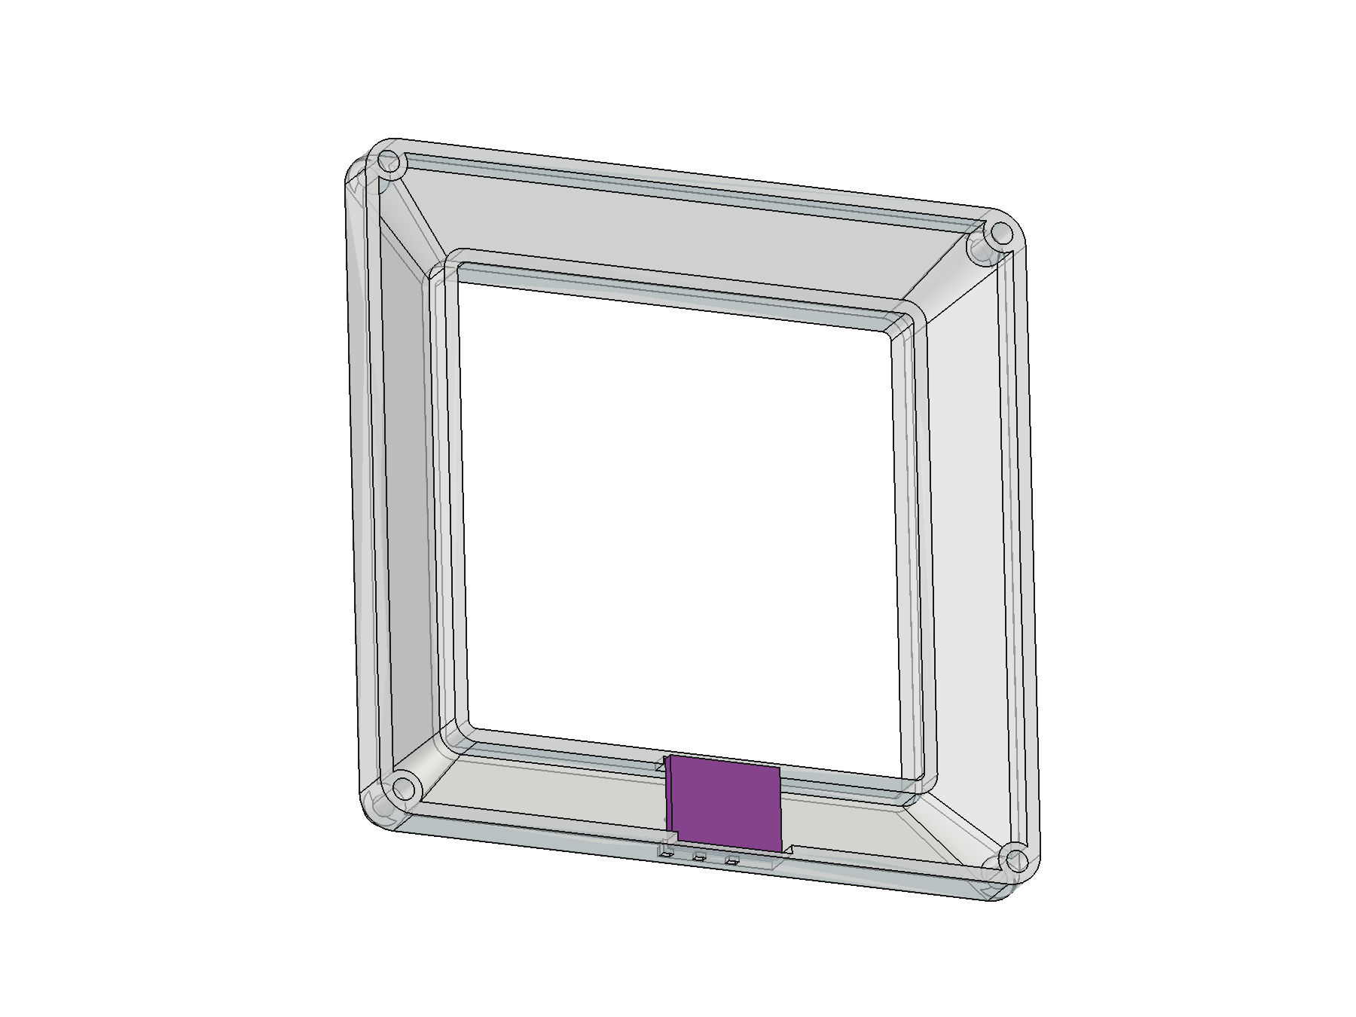
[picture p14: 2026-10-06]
hardware/docs/img/frame_humidity-sensor.png

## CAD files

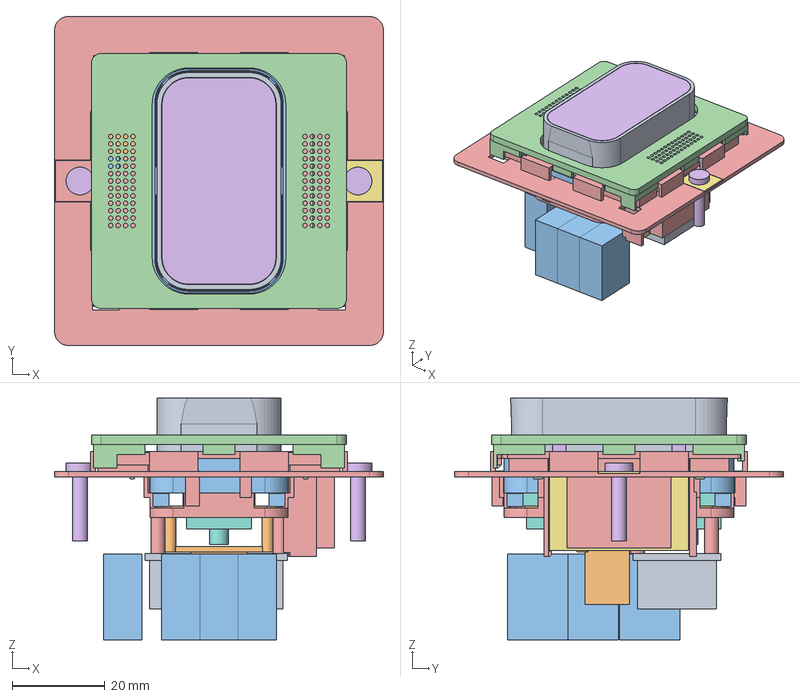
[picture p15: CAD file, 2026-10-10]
hardware/models/insert-L_assembly.step
71.0 x 71.0 x 52.2 mm

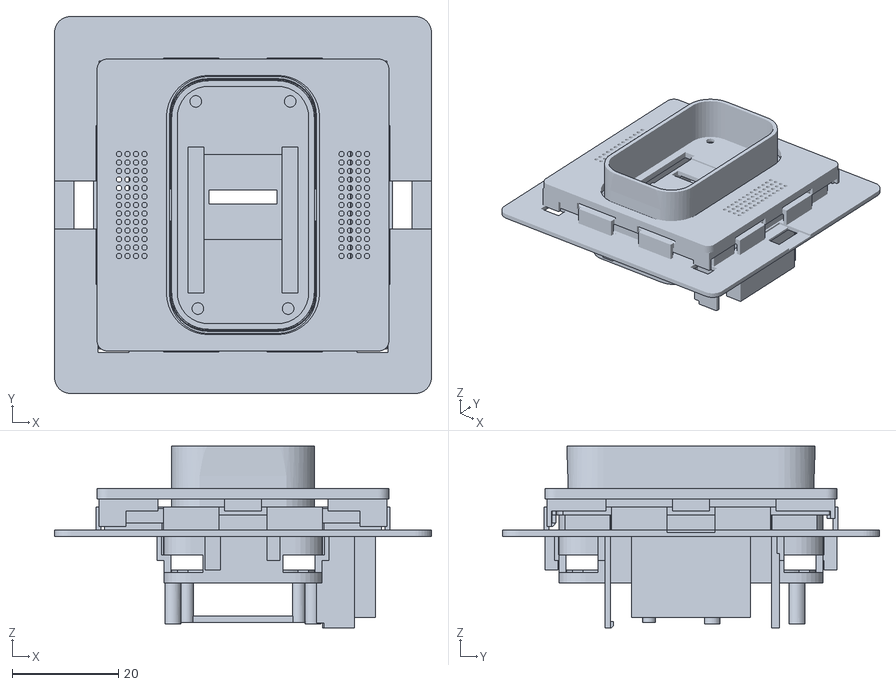
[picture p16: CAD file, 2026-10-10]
hardware/models/insert-L_printed-assembly.stl
71.0 x 71.0 x 34.2

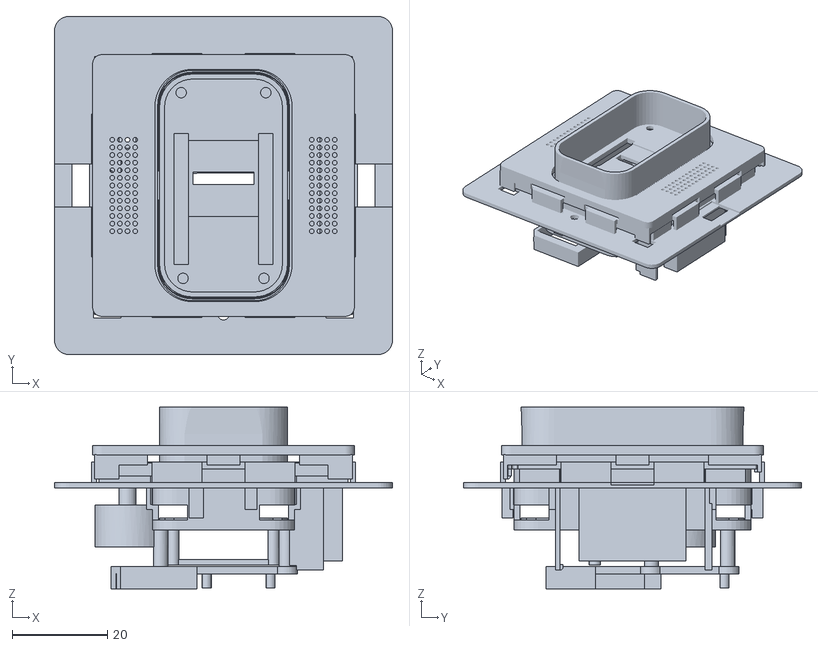
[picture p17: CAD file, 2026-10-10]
hardware/models/kit-v0.10.4_printed-assembly.stl
71.0 x 71.0 x 38.2

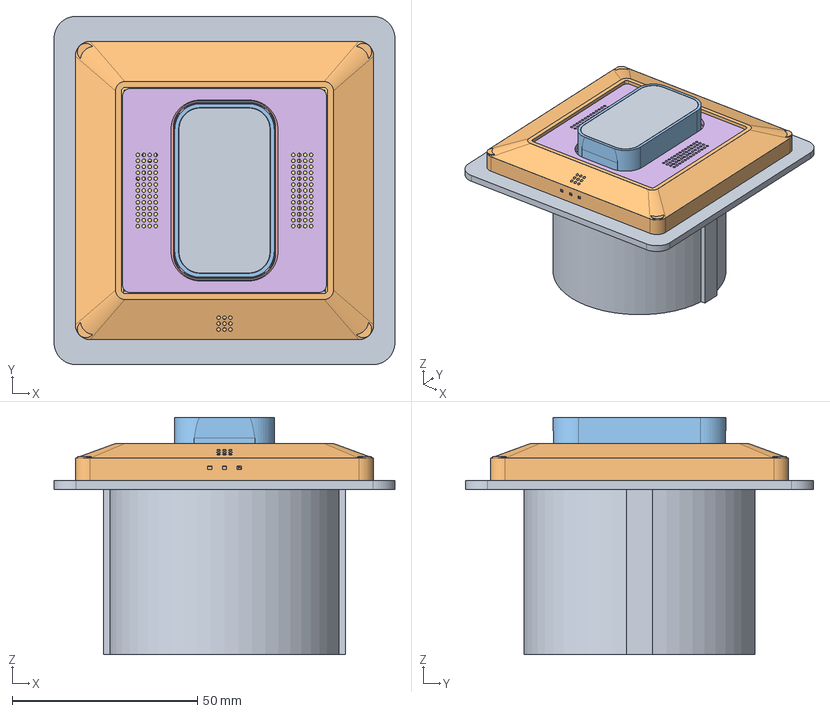
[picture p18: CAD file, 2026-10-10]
hardware/models/kit-v0.10.4_assembly.step
92.0 x 94.0 x 64.0 mm

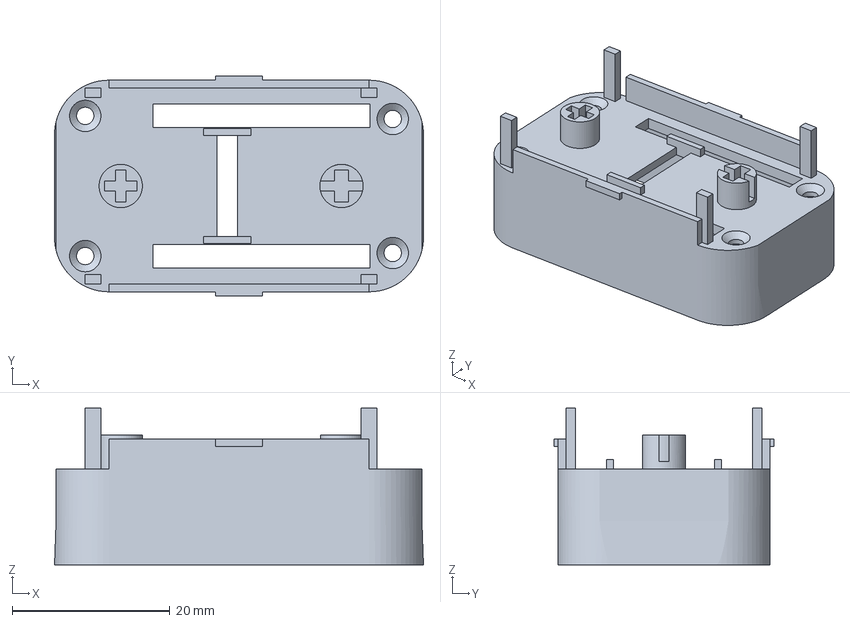
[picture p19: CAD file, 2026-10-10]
hardware/print/bambu/roomkey-kit-v0.10.4_B-key_0.2nozzle.gcode.3mf
46.8 x 28.0 x 19.9 mm

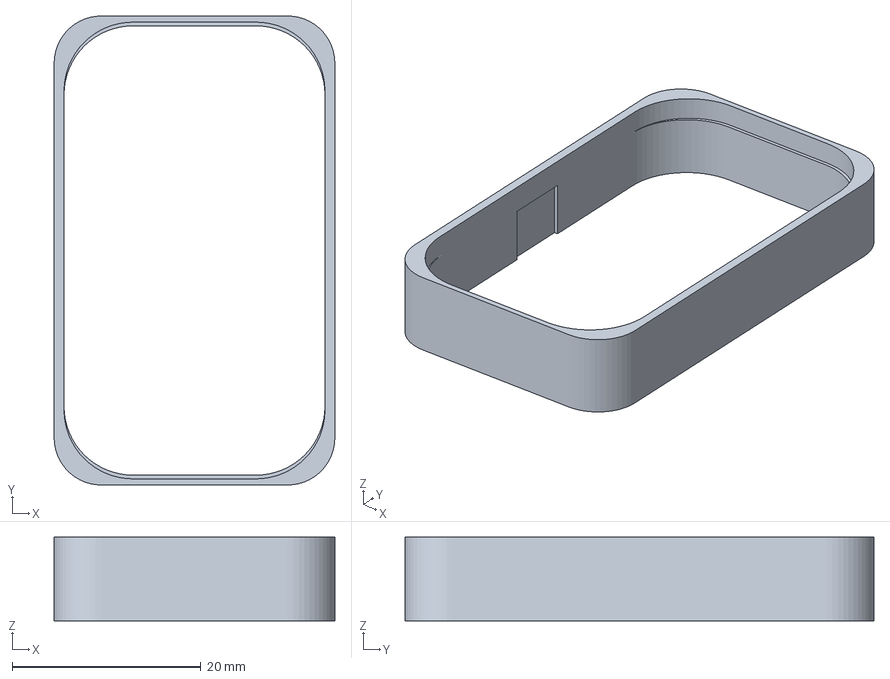
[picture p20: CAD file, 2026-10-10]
hardware/print/bambu/roomkey-kit-v0.10.4_C-collar-pla_0.2nozzle.gcode.3mf
29.8 x 49.7 x 8.90 mm

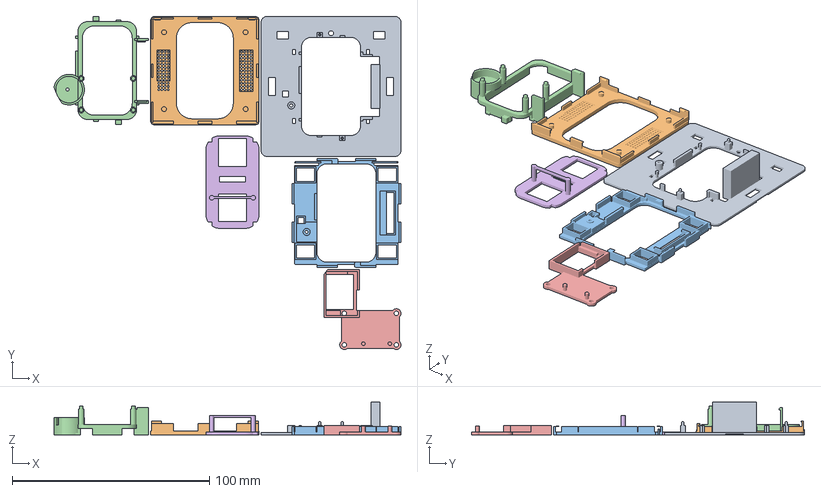
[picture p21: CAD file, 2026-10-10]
hardware/print/bambu/roomkey-kit-v0.10.4_A-petg_0.2nozzle.gcode.3mf
176.0 x 168.9 x 16.5 mm
kit_chassis_2_flange_print.stl
plate_S_print.stl
kit_chassis_1_front_print.stl
kit_chassis_3_rear_print.stl
kit_back_carrier_print.stl
switch_plate_print.stl

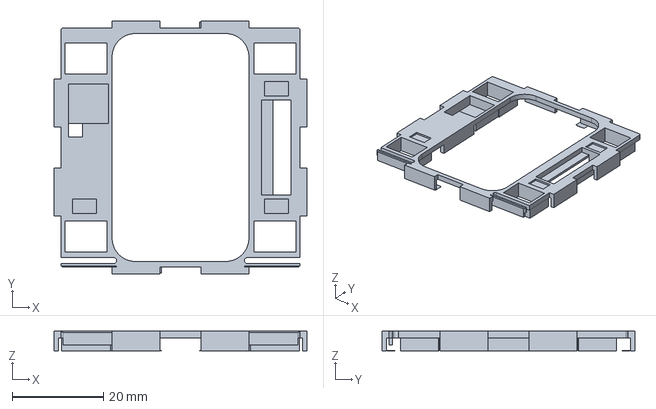
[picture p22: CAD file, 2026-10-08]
hardware/models/chassis_L_1_front.step
55.4 x 55.4 x 4.30 mm

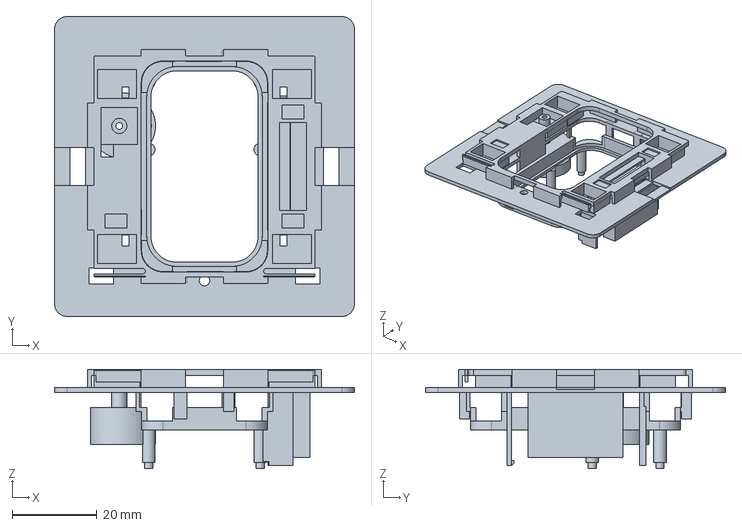
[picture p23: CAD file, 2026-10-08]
hardware/models/kit_chassis.step
71.0 x 71.0 x 23.5 mm

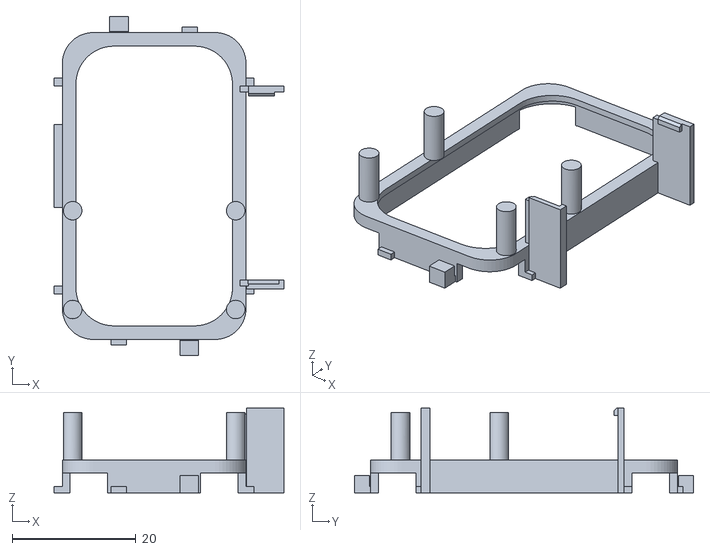
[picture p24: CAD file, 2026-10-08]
hardware/models/chassis_S_3_rear_print.stl
37.2 x 54.9 x 13.7

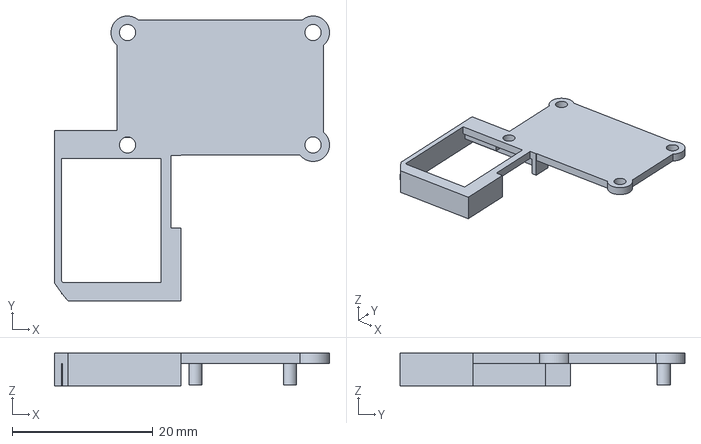
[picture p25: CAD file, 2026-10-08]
hardware/models/kit_back_carrier.step
39.2 x 40.5 x 4.66 mm

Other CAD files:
hardware/models/key_shell_print.stl
hardware/models/key_shell.step
hardware/print/bambu/roomkey-kit-v0.10.4_B-key_0.4nozzle.gcode.3mf
hardware/print/bambu/roomkey-kit-v0.10.4_C-collar-pla_0.4nozzle.gcode.3mf
hardware/print/bambu/roomkey-kit-v0.10.4_A-petg_0.4nozzle.gcode.3mf
hardware/models/chassis_L.step
hardware/models/chassis_L_1_front_print.stl
hardware/models/chassis_L_2_flange.step
hardware/models/chassis_L_2_flange_print.stl
hardware/models/chassis_L_3_rear.step
hardware/models/chassis_S.step
hardware/models/chassis_S_1_front_print.stl
hardware/models/chassis_S_2_flange.step
hardware/models/chassis_S_2_flange_print.stl
hardware/models/chassis_S_3_rear.step
hardware/models/collar.step
hardware/models/collar_print.stl
hardware/models/coupon-v0.step
hardware/models/coupon-v0_print.stl
hardware/models/coupon-v1.step
hardware/models/coupon-v1_print.stl
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

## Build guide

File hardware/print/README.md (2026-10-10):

# RoomKey kit — printing (parts v0.10.4, WIP)

> **Prototype for the desk. WIP: modelled and CAD-checked; the parts of this exact revision are not all printed and
> tested yet.** The kit is the whole RoomKey in one practice box, powered from a lab supply (5.0 V, about 1 A). It is
> SELV only. Never put it into a wall box, and never connect it to 230 V.

## What you print

Nine parts. Everything is **white PETG** except the light-guide collar, which is **clear PLA**. Every part prints flat
**without supports**, with one exception: the key shell needs supports inside its board pocket.

| # | Part | STL (in [`../models/`](../models/)) | Material | On the bed | Supports |
|---|---|---|---|---|---|
| 1 | Front plate 55 × 55 | `plate_S_print.stl` | PETG white | visible face down | none |
| 2a | Chassis, front part (deck, pockets, frame rims, mic tube) | `kit_chassis_1_front_print.stl` | PETG white | front down | none |
| 2b | Chassis, flange with webs and 2 pins | `kit_chassis_2_flange_print.stl` | PETG white | front down | none |
| 2c | Chassis, rear part (rear wall, ledge, speaker cradle, posts) | `kit_chassis_3_rear_print.stl` | PETG white | front down | none |
| 3 | Key shell (holds the touch board) | `key_shell_print.stl` | PETG white | front edge down | **tree supports in the pocket** |
| 4 | Light-guide collar | `collar_print.stl` | **PLA clear** | back face down | none |
| 5 | Switch plate with cable anchor | `switch_plate_print.stl` | PETG white | front down | none |
| 6 | Back carrier (radar tray, amplifier pins) | `kit_back_carrier_print.stl` | PETG white | flat, tray up | none |

The STL files are already oriented for printing.

## Bambu Lab A1 files (ready to print)

[`bambu/`](bambu/) holds sliced `.gcode.3mf` files for a Bambu Lab A1 with an AMS lite, for a **0.4** and a **0.2**
nozzle. There are three plates per nozzle:

| Plate | Parts | Filaments | Time 0.4 / 0.2 nozzle |
|---|---|---|---|
| `A-petg` | 1, 2a, 2b, 2c, 5, 6 | PETG white | ≈ 3 h 47 / 6 h 42 |
| `B-key` | 3, with supports | PETG white (part + support body), **PLA clear (support contact layers only)** | ≈ 1 h 54 / 3 h 22 |
| `C-collar-pla` | 4 | PLA clear | ≈ 43 min / 58 min |

- **Settings:** precise and slow. Layers 0.10 mm, 3 walls, outer walls 25 mm/s, inner walls 40 mm/s, first layer 15 mm/s,
  bridges 15 mm/s, 20 % gyroid infill. Textured PEI plate. Base presets: *0.12mm Fine @BBL A1* (0.4) and *0.10mm Standard
  @BBL A1 0.2 nozzle* (0.2); filaments *Generic PETG* and *Generic PLA*.
- **Plate B, the key shell:** tree supports from the build plate. The support body is PETG; the **interface (the layers
  that touch the part) is PLA**, with a top Z distance of 0. PLA does not bond to PETG, so the supports come off clean
  without tearing the thin walls. The A1 purges every filament change into its waste chute; there is no prime tower.
- **Before you print:** map the filaments to your AMS slots (white PETG / clear PLA) in Bambu Studio or Bambu Handy.
- **Re-slice:** [`../../tools/bambu_kit.py`](../../tools/bambu_kit.py) rebuilds all six files from the STLs (Windows,
  Bambu Studio installed).
- **Other printers:** use the STLs with the same settings. All parts except 3 need no supports. Short bridges up to
  9 mm print without support.

## Assembly

The assembly and gluing steps, the bought parts and the first tests are in **[../BUILD.md](../BUILD.md)**.

## Fits found on real prints (A1, PETG, 0.10 mm layers)

**The fits are tuned for a 0.2 nozzle** (the RoomKey parts are printed with one since 2026-10-08). A 0.4 nozzle
prints holes and pockets a little smaller: if the touch board or the radar is too tight, sand the inner walls lightly.

| Fit | Value | How it was found |
|---|---|---|
| Touch board in the key shell | 0.10 / side | 0.15 was "extremely perfect" with a 0.4 nozzle, loose with the 0.2 |
| Key in the collar | 0.40 / side | 0.25 scraped |
| Radar in its tray | 0.10 / side | 0.15 fit once, then was loose on the next print |
| Amplifier pins | pitch 13.435, Ø 1.9 | 13.97 too wide, 12.9 too close |
| Chassis pins 2b → 2c | Ø 1.2 in Ø 1.5 + 45° lead-in | 0.1 play closed up on the bed face |

Design background and change log: [`../docs/insert-design.md`](../docs/insert-design.md) (§0 changes, §11 assembly).

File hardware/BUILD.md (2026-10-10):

# Build guide: RoomKey desk prototype (kit, parts v0.10.4)

> **WIP prototype, for the desk only.** Never put it in a wall and never connect it to 230 V. Power comes from a lab
> supply. Nothing here is certified or reviewed. The in-wall product is designed in [docs/insert-design.md](docs/insert-design.md).

The kit is the whole RoomKey in **one** flush box: touch key, speaker, microphone, presence radar, amplifier and a
humidity sensor in the frame. It goes into a printed **practice box**, a flush-box replica with a 1-gang frame, so it can
be built and tested on the bench.

Kit in the practice box

## Status (2026-10-08)

| Part | State |
|---|---|
| Practice box + frame | printed and fitted ✓. Frame vents centred |
| Chassis (3 glued parts, v0.10), plate, switch plate (glued) | printed and glued ✓ |
| Key: touch board in a rigid one-piece shell on two MX switches (v0.9) | printed, fits ✓. v0.10.4: board pocket 0.10/side for the 0.2 nozzle (0.15 was loose) — not printed yet |
| Collar (light guide), v0.10.3: 0.15 mm wider inside, the key scraped | not printed yet |
| Back carrier, v0.10.2: amplifier pins 13.435 apart, radar play 0.10 | not printed yet |
| End-press binding of the key (desk test R1) | not tested yet |
| Radar range through the plate | not tested yet; this is the key test |
| Audio (mic, speaker loudness), glow ring | not tested yet |

## 1. What you need

**Bought parts:**

| Part | Notes |
|---|---|
| Waveshare ESP32-C6-Touch-LCD-1.47 (touch board) | the key's face. 24.55 × 44.50 × 10.6 |
| 2 × MX-style key switch, plate mount (3-pin) | under the key; both are one key in the firmware |
| HLK-LD2410C presence radar | 15.84 × 22.03; header soldered |
| MAX98357A I²S amplifier breakout | mounting holes 2.2; solder the speaker to its pads, not the screw terminal |
| Waveshare 2030 cavity speaker | 19.3 × 29.8 × 4.6 (sold as a pair on one plug) |
| INMP441 microphone module (round) | Ø13.1 |
| SHT31-D humidity/temperature breakout | sits in the frame's bottom border |
| 4 × WS2812B-MINI 3535 LEDs | glow ring |

There is no light sensor in the RoomKey (decided 2026-10-06). Every measured dimension and its source are in
[`cad/roomkey_params.py`](cad/roomkey_params.py).

**Small parts:**
- 4 × M3 × 8 for the frame;
- 4 × M2 × 4 countersunk for the touch board;
- 2 × device screws 3.2 × 15 (or M3 × 16) for the insert;
- 2 foam rings for the mic tube, 3.5 outside and 1.5 inside: **2 mm** thick at the plate end, 0.8 at the module end;
- gel cyanoacrylate glue (CA) and hot glue;
- 0.05 mm² silicone wire, plus thicker wire for the 5 V node (see the wiring doc);
- a lab supply.

## 2. Print

Everything is in **[print/README.md](print/README.md)**: the part list (material, orientation, supports), the
**ready-to-print Bambu Lab A1 files** for a 0.4 and a 0.2 nozzle, and the fits found on real prints. In short:

- **white PETG** for everything except the collar, which is **clear PLA**;
- every part prints flat **without supports**, except the key shell. Its supports sit in the board pocket, with
  **PLA as the support interface** so they come off clean;
- slow and precise: 0.10 mm layers, outer walls 25 mm/s.

The practice box and frame print as before (PETG, no supports, 0.20 mm layers):

| File in [`models/`](models/) | Part |
|---|---|
| `practice_box_print.stl` | practice box (box + "wall" plate) |
| `practice_frame_1x_print.stl` | 1-gang frame, AS 500 size, with the sensor pocket |

## 3. Assemble

Glue with **gel CA**, used sparingly and only on faces that touch. Roughen them with fine sandpaper first.

1. **Frame:**
   - Lay the SHT31-D flat into the pocket behind the frame's bottom border: chip side forward, pins to the left (front
     view). Fix it with a dot of hot glue, not on the chip.
   - Screw the frame to the practice box with 4 × M3 × 8 from behind.
2. **Chassis (2a front, 2b flange, 2c rear):**
   - Put 2a on 2b and **push the collar through both openings**: it aligns them. Glue the ribs and rims from the
     outside, not at the collar opening. When the glue has set, take the collar out.
   - Put 2c onto the two pins of 2b and glue the web tops. If a pin does not go in, drill its hole to 1.5 mm, or cut
     it off and align by eye.
3. **Switches:**
   - Clip both MX switches into the switch plate and wire them.
   - Lay the plate onto the ledge in 2c, from the front, and fix it with 2–3 dots of CA. The switches still pull out to
     the front.
4. **Key:**
   - Lay the touch board into the key shell from behind and screw it in with 4 × M2 × 4.
   - Press the key straight onto both switch stems, like a keycap. The top socket is tight; the bottom one floats a
     little along the key's length, on purpose.
   - Slide the collar over the key from the front; its grooves take the key's catch nubs. Do **not** glue it.
   - Put the plate on. The plate holds the collar, and the collar holds the key captive.
5. **Speaker:** slide it in from behind with its **wire tab pointing up**, into the slot of the upper cradle rib.
6. **Mic:** put the 2 mm foam ring on the plate end of the sound tube and the 0.8 mm ring on the other end. Press the
   INMP441 into its holder (upper left, behind the ledge): labelled side forward, port on the tube.
7. **Back carrier:**
   - Lay the radar into the tray: **antenna side forward, header towards the box wall.** It rests on two ledges at its
     short ends. Fix two corners with hot glue.
   - Push the amplifier onto its two pins, components to the back.
   - Push the carrier onto the four pins and fix it with a drop of glue.
8. **Wiring:** follow [`../docs/wiring-touch-board.md`](../docs/wiring-touch-board.md). It has every pin, the shared
   lines, wire gauges and the **5 V node** for bench power, and it is checked against the firmware.
   [`models/kit-v0.10.3_wiring.json`](models/kit-v0.10.3_wiring.json) holds 3D-routed lengths from an earlier per-part
   plan; use them only as length estimates.
9. **Into the box:** slide the insert into the practice box and fix it with the 2 device screws.

**Service:** the plate comes off first, then the collar, then the key. The touch board comes out of the key shell by
pushing it through a screw hole.

## 4. Power and first tests

- **Power:** set the supply as described in "Power without USB" in the wiring doc. That is 5.0 V, with the current limit
  raised once the amp and LEDs are on. The 5 V goes into the node at the parts; the board's VBUS gets it through a
  Schottky diode. Never apply 12 V to the 5 V node.
- **Tests:**
  - **Key:** press it every 5 mm along its length and many times at both ends (test R1). Every press must click and
    come back; nothing may stick. The key must not fall out.
  - **Touch:** taps and swipes must not trigger the key.
  - **Radar:** compare the range with and without the insert in front.
  - **Speaker:** compare a chime at full volume with your doorbell, using a level app at 1 m.
  - **Mic:** check the level.
  - **Humidity:** check that the reading follows the room.

## Regenerate the files

All parts come from Python scripts; see [README.md](README.md). Run headless, from the repo root (macOS path shown; on
Windows use `C:\Program Files\FreeCAD 1.1\bin\FreeCADCmd.exe`):

```bash
FC=/Applications/FreeCAD.app/Contents/Resources/bin/FreeCADCmd
for f in make_key_module make_insert_S make_practice_box make_kit; do
  PYTHONIOENCODING=utf-8 $FC -c "exec(open('hardware/cad/$f.py', encoding='utf-8').read())"; done
```

Each run prints its collision, clearance and print checks. They must report 0 collisions, the key check must report
"CAPTIVE", and the radar tray "CLOSED". `python tools/bambu_kit.py` then rebuilds the Bambu files (Windows, Bambu
Studio installed).

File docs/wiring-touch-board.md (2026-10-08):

# RoomKey Touch — wiring (prototype)

Every wire from the board to each part of the RoomKey Touch prototype: microphone, amplifier and speaker, sensors, keys and
glow ring. It is checked against the firmware (`esphome/roomkey_touch.yaml` and its packages, `main` 2026-10-05).

Scope: **prototype on the bench and the desk replica** ("table A" in the insert's file, `features/roomkey-einsatz.md` §4).
The wall insert v1 differs: IO3 and IO5 go to the plate and the relay there, and the radar has no place yet.

**SELV only:** 5 V from USB-C. Nothing here ever touches 230 V.

Which part goes to which pad, colour-coded by part

*Back of the board, USB-C at the top. Next to each pad are the part pins that go there. Colours: mic purple, amp coral, SHT31-D teal, radar blue, MX1 pink, MX2 red, glow ring green; grey = leave free. The ground wires are spread over the three GND pads by part group.*

## The board: Waveshare ESP32-C6-Touch-LCD-1.47

Header H1: 2 × 11 bare pads, 2.54 mm pitch. The silkscreen names the pads by GPIO number. The view is from the **back**
(components side), USB-C at the top. **From the front (display side) the two columns are mirrored.**

```
                 USB-C
     left column          right column
   VBUS  ● H1-1      H1-2  ●  VBAT   (not used: no battery in aikos)
   GND   ● H1-3      H1-4  ●  GND
   TXD   ● H1-5      H1-6  ●  GND
   RXD   ● H1-7      H1-8  ●  3V3
   RST   ● H1-9      H1-10 ●  SCL
   1     ● H1-11     H1-12 ●  SDA
   2     ● H1-13     H1-14 ●  13     (USB D+, don't use)
   3     ● H1-15     H1-16 ●  12     (USB D−, don't use)
   4     ● H1-17     H1-18 ●  9      (BOOT)
   5     ● H1-19     H1-20 ●  8
   6     ● H1-21     H1-22 ●  7
```

| Pad (silkscreen) | H1 | GPIO | Used for |
|---|---|---|---|
| VBUS | 1 | — | **5 V** (from USB-C): amplifier, radar, LEDs |
| GND | 3, 4, 6 | — | ground for every part |
| TXD | 5 | GPIO16 | I²S data **out** → amplifier DIN |
| RXD | 7 | GPIO17 | I²S data **in** ← microphone SD |
| 3V3 | 8 | — | **3.3 V** (on-board regulator, 800 mA): microphone, SHT31-D |
| SCL | 10 | GPIO19 | I²C clock: SHT31-D (shared with the board's touch and IMU) |
| SDA | 12 | GPIO18 | I²C data: SHT31-D (shared with the board's touch and IMU) |
| 3 | 15 | GPIO3 | radar TX → ESP (UART RX) |
| 4 | 17 | GPIO4 | glow ring data → first LED's DIN |
| 5 | 19 | GPIO5 | ESP (UART TX) → radar RX |
| 6 | 21 | GPIO6 | key bottom (MX 2) |
| 7 | 22 | GPIO7 | I²S bit clock (BCLK/SCK): microphone **and** amplifier |
| 8 | 20 | GPIO8 | I²S word select (WS/LRC): microphone **and** amplifier |
| 9 | 18 | GPIO9 | key top (MX 1); also the board's BOOT button |
| RST, 1, 2, 12, 13, VBAT | 9, 11, 13, 16, 14, 2 | — | **don't connect**: reset, display bus, USB, battery (its charger runs at 2 A, see "Bench: a battery") |

## Every wire, by part

### Microphone INMP441 (I²S)
| INMP441 | → board pad | Note |
|---|---|---|
| VDD | 3V3 | **3.3 V only** |
| GND | GND | |
| L/R | GND | left channel (the firmware reads the left slot) |
| SCK | 7 | shared with the amplifier's BCLK |
| WS | 8 | shared with the amplifier's LRC |
| SD | RXD | |

### Amplifier MAX98357A (I²S) and speaker
| MAX98357A | → board pad | Note |
|---|---|---|
| VIN | VBUS | 5 V |
| GND | GND | |
| BCLK | 7 | shared with the microphone's SCK |
| LRC | 8 | shared with the microphone's WS |
| DIN | TXD | |
| GAIN | — | leave open (9 dB) |
| SD | — | leave open |
| OUT + / OUT − | speaker + / − | 8 Ω, never to ground |

Microphone and amplifier share one I²S bus, so the key works half-duplex: the speaker stops while you hold the key.

### Temperature and humidity SHT31-D (I²C, address 0x44)
| SHT31-D | → board pad | Note |
|---|---|---|
| VIN | 3V3 | |
| GND | GND | |
| SCL | SCL | |
| SDA | SDA | |
| ADR | — | open = 0x44 |
| ALR | — | open |

Place it in room air, away from the ESP and the amplifier, which heat up.

No light sensor: the RoomKey doesn't get one (decided 2026-10-06).

### Presence radar HLK-LD2410C (UART 256000 baud)
| LD2410C | → board pad | Note |
|---|---|---|
| VCC | VBUS | **5 V** |
| GND | GND | |
| TX | 3 | radar sends, ESP receives |
| RX | 5 | ESP sends, radar receives |
| OUT | — | not used (the firmware reads the UART) |

It looks through plastic, but not through metal.

### Keys: two MX switches (read separately)
| Switch | Leg 1 → pad | Leg 2 → pad | In HA |
|---|---|---|---|
| top (KEY1) | 9 | GND | "Key top" |
| bottom (KEY2) | 6 | GND | "Key bottom" |

Don't wire them in parallel. Holding the top key while power comes on starts the board in download mode: release it and
power-cycle.

### Glow ring: 4 × WS2812B-MINI 3535 (one chain)
| From | → to | Note |
|---|---|---|
| pad 4 | LED 1 DIN | data, 3.3 V level |
| LED 1 DOUT | LED 2 DIN | the chain continues: LED 2 → 3 → 4 |
| VBUS | VDD of every LED | 5 V |
| GND | GND of every LED | |

The chain order is bottom right → top right → top left → bottom left. The firmware drives 4 × WS2812 with GRB colour
order on GPIO4.

3.3 V data into LEDs that run on 5 V is at the edge of their spec, though it usually works on a short wire. If the first
LED flickers, add a level shifter (74AHCT1G125), or feed that LED's VDD through a diode (about 4.3 V).

## Shared lines at a glance

| Line | Pad | Goes to |
|---|---|---|
| 5 V | VBUS | amplifier VIN, radar VCC, LED VDD |
| 3.3 V | 3V3 | microphone VDD, SHT31-D VIN |
| GND | GND (3 pads) | every part, the microphone's L/R, both keys |
| I²C | SCL, SDA | SHT31-D (0x44); on the board: touch 0x63, IMU 0x6B |
| I²S clock | 7 | microphone SCK, amplifier BCLK |
| I²S word select | 8 | microphone WS, amplifier LRC |

**One wire per board pad.** Where several parts share a line, don't put several wires on the board's pad. Run one wire to
the first part and **chain** on from part to part: solder the next wire to the same pin of that breakout, which has
bigger pads and no display next to it.

| Line | Chain | Wire |
|---|---|---|
| 5 V | USB power: VBUS → amp VIN → radar VCC → LED 1 VDD → LED 2 …; lab supply: from the 5 V node (see "Power without USB") | AWG 26–28 (the amp draws a few hundred mA) |
| 3.3 V | 3V3 → mic VDD → SHT31-D VIN | AWG 30 |
| GND 1 | GND (H1-3) → mic GND → amp GND | AWG 28 |
| GND 2 | GND (H1-4) → SHT31-D GND → radar GND | AWG 30 |
| GND 3 | GND (H1-6) → MX1 leg 2 → MX2 leg 2 → LED 1 GND → LED 2 … | AWG 30 |
| I²C clock | SCL → SHT31-D SCL | AWG 30 |
| I²C data | SDA → SHT31-D SDA | AWG 30 |
| I²S clock | 7 → mic SCK → amp BCLK | AWG 30, short |
| I²S word select | 8 → mic WS → amp LRC | AWG 30, short |

The mic's L/R goes to GND **on the mic board itself**: a short bridge from its L/R pin to its GND pin, so no extra wire runs
to the board.

On the bench with jumper wires, a small breadboard does the same job: one wire from each pad into its row, and the parts plug
into that row. For a tidy prototype, a small piece of stripboard with one strip per line works as a hub: the insert's hub
board does this later.

## Power without USB

VBUS is wired to the USB-C connector's VBUS. 5 V fed into the VBUS pad powers the board exactly as USB does, plus everything
on the 5 V chain.

**Bench: a lab power supply**
- Set it with the output off: **5.0 V** (5.2 V at most; the amp and LEDs allow 5.5 V).
- Current limit:
  - **0.5 A** for the board, mic and sensors. The ESP's Wi-Fi peaks need 0.3–0.4 A; less makes the voltage dip and the key
    restart.
  - **1.5–2 A** once the amp and LEDs are on.
- Feed a **5 V node at the parts**, not the board's VBUS pad, so the board's thin wires (0.05 mm²) never carry the
  amplifier's and LEDs' current:

```
lab supply +  ──►  5 V node ──┬── amplifier VIN
                  (≥0.14 mm²) ├── radar VCC
                              ├── LED 1 VDD → LED 2 …
                              └──►|── board VBUS   (Schottky SS34/1N5819, cathode toward the board; 0.05 mm² is enough)

lab supply −  ──►  GND node ──┬── amplifier GND
                              ├── radar GND, LED GND, …
                              └── board GND
```

- The board then draws only its own 0.1–0.35 A through its VBUS wire. With the diode you may plug in USB at the same time to
  flash or log: USB then powers only the board, and neither source feeds the other. Board VBUS is about 4.6 V behind the
  diode, which is fine.
- Without the diode, never plug in USB while the lab supply is connected.
- Wires: 0.14–0.25 mm² from the supply to the nodes and for the amplifier's VIN/GND; 0.05 mm² for everything else.
- If the supply goes into current limit (CC) right away, there is a short or a wiring fault: switch off and check.

| State | Current at 5 V (approx.) |
|---|---|
| board alone, display on, Wi-Fi connected | 0.1–0.2 A, short peaks to 0.35 A |
| + mic and sensors | a few mA more |
| + radar | +0.08 A |
| ringtone / door audio on the speaker | peaks to 0.5–0.8 A |
| glow ring full white | up to +0.25 A |

**Bench: a battery**

One LiPo cell gives 3.0–4.2 V, not 5 V. Don't wire it to the pads directly:
- **Not to the 5 V node.** The radar needs 5 V (rated 5–12 V) and the LEDs at least 3.5 V. The board gets the cell's
  voltage behind two diodes, ours and the board's own (D1), so the ESP browns out once the cell is below about 4 V.
- **Not to VBAT** (H1-2). The board's charger (ETA6098) charges at **2 A** (R18 = 82 kΩ) whenever USB or the 5 V node
  is live. That is 2C for a 1000 mAh cell, about twice what small cells allow. The round master board
  (ESP32-S3-Touch-AMOLED-1.32) has the same charger at 2 A.

Instead, feed the 5 V node from a 5 V source, in the lab supply's place:
- **A USB power bank** (simplest): a USB cable with bare ends, red to the 5 V node, black to the GND node. It brings
  the cell's protection, its charging and the 5 V converter. Some power banks switch off below about 0.1 A; the key
  draws more.
- **A LiPo through a step-up converter** to 5.0 V, at least 1.5 A out. Set it to 5.0 V before you connect anything.
  Use only cells with a protection board (the small board under the tape at the wires), and check red and black with a
  multimeter: the pads have no reverse-polarity protection. Charge the cell on its own at 0.5 A, attended: a lab supply
  at 4.20 V and 0.5 A (stop below 50 mA), or a LiPo charger set that low.

A 1000 mAh cell through a step-up runs the key for about 2–3 hours idle (board and radar), less with sound and the
ring.

**Later, in the wall:** a 12 V SELV feed, the hub's 12 → 5 V converter, then a Schottky diode into VBUS (insert design §8.2).

Without USB, flashing, logs and Home Assistant all run over Wi-Fi. Keep the USB-C port reachable for recovery: a firmware
that doesn't boot needs a USB flash.

## Rules
- Unplug USB before you solder or re-plug anything.
- **Never connect 5 V (VBUS) to a 3.3 V part:** microphone, SHT31-D.
- After a flash, leave the board powered for one minute. Otherwise ESPHome rolls back to the previous firmware.

## Where this lives in the firmware
- Pins: `esphome/packages/board_c6_touch_lcd_147.yaml` (substitutions `i2s_*`, `radar_*`, I²C, keys, glow ring)
- Microphone: `roomkey_mic.yaml` + `roomkey_voice_mic.yaml` (gain in HA: "Mic gain")
- Amplifier: `roomkey_voice_speaker.yaml`
- Sensors: `roomkey_sensors.yaml`
- Device: `esphome/roomkey_touch.yaml`

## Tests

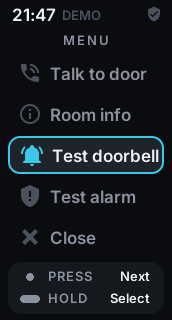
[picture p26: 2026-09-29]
docs/screens/04_menu_select_test_ring.png

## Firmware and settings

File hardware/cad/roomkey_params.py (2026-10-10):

"""RoomKey hardware — the ONE source of every part dimension (board, key switch, audio, sensors).

CAD generators, drawings and checks all read this file, so they cannot disagree.
`python3 roomkey_params.py` runs validate(): the quick key-level rules, then ERROR / WARNING / OK.
The wall insert (box, frame, both variants, mains parts) lives in insert_params.py, which imports
this file and adds its own, much longer validate().

Tags: [DS] datasheet or vendor drawing (source named) · [MEAS] measured on the real part ·
      [FREE] design choice · [TBD] placeholder until measured.
Units: mm. Front view: origin = rocker centre, x right, y up, d = depth into the wall (+),
d = 0 on the rocker FRONT face.

Changes 2026-09-30 (insert v0.2 draft, see hardware/docs/insert-design.md):
  * v0.4 (2026-10-01): both MX switches the same brown (same feel at both ends); no key stop bosses (insert doc §3).
  * v0.3 (2026-10-01): MX at (0, +15.0) / (0, −13.0) — smaller overhang for end presses.
  * v0.2: MX switches back on the long axis (0, +13.5) / (0, −10.5) — a diagonal pair leaves a free roll
    axis; the key gets a 3.8 mm skirt that slides in a fixed collar (0.25 clearance) as a linear guide.
    Key socket depth 3.4 = stem engagement, so the stem bottoms at the design position.
    Box values moved to insert_params.py (no duplicates). Antenna chip position read off the drawing.
  * MX key switch: 11.6 mm is PCB -> TOP OF HOUSING in the Cherry drawing, not "stem top above
    plate". Stem top is 10.2 above the plate top. The old key stack (36 mm) was 4.4 mm too deep.
  * MX_BELOW_PLATE 5.0 is measured from the plate TOP (not bottom) -> no extra plate thickness.
  * Keycap shell: wall 1.2 -> 1.0 and a 0.15 fit clearance around the board frame (the old KEY_W had
    zero clearance). Key 26.85 x 46.8, cut-out 28.85 x 48.8, bands stay 3.1 mm.
  * Board: PCB 1.2 and brass M2 standoffs 4.0 read from the side view; the two bottom holes are
    17.00 apart, the top ones 17.78.
"""
import math

# ============================================================== FROZEN
# Values the project owner has confirmed. validate() flags any drift as ERROR.
FROZEN = {
    "ROCKER_W": 55.0,   # [MEAS] 2026-09-29, existing rocker is 55 × 55
    "ROCKER_H": 55.0,
}

# ============================================================== wall / frame
ROCKER_W = 55.0          # [MEAS]
ROCKER_H = 55.0          # [MEAS]
# (box, frame and installation values live in insert_params.py only)

# ============================================================== touch board (target)
# Waveshare ESP32-C6-Touch-LCD-1.47, vendor dimension drawing:
# https://www.waveshare.com/img/devkit/ESP32-C6-Touch-LCD-1.47/ESP32-C6-Touch-LCD-1.47-details-size.jpg
TB_W, TB_H, TB_T = 24.55, 44.50, 10.60   # [DS] outline incl. black frame; total thickness incl. brass standoffs
TB_GLASS_W, TB_GLASS_H = 22.05, 42.00    # [DS]
TB_ACTIVE_W, TB_ACTIVE_H = 17.75, 32.93  # [DS] visible pixels
TB_CORNER_R = 5.75                       # [DS] frame corner radius
TB_FRONT_T = 5.40                        # [DS] black frame (display module) in front of the PCB
TB_PCB_T = 1.20                          # [DS] 6.60 (frame + PCB) − 5.40
TB_STANDOFF = 4.00                       # [DS] 10.60 − 6.60: brass M2 hex standoffs behind the PCB
TB_HOLE_DX, TB_HOLE_DY = 17.78, 39.00    # [DS] M2 holes: top pair 17.78 apart, top↔bottom 39.00
TB_HOLE_DX_BOTTOM = 17.00                # [DS] bottom pair 17.00 apart (3.77 from the frame edge)
TB_HOLE_EDGE = 2.75                      # [DS] bottom hole ↔ frame end; top one inferred by symmetry (2.75 + 39.00 + 2.75 = 44.50)
TB_HEADER_PITCH_X = 17.78                # [DS] 2 × 11 header columns, 7 × 2.54 apart
TB_HEADER_Y = (9.65, -15.75)             # [DS] first / last pin of each column (first pin 9.85 below the top hole), pitch 2.54
TB_STANDOFF_THREAD = None                # [TBD] brass standoffs female M2? (drawing says "M2") — check on arrival
TB_ANT = (0.0, -20.4, 3.2, 1.6, 1.1)     # [DS] ceramic chip antenna ("C3", red) on the PCB BACK, centred at the non-USB end:
                                         #      x, y, length, width [TBD], height [TBD]
TB_LEDS = "PWR (red, always on) + CHG next to USB-C"   # [DS] must not shine through the white key shell → black out

# ============================================================== PoC board (desk)
PB_W, PB_H = 20.32, 36.37                # [DS] ESP32-C6-LCD-1.47 bare PCB, portrait

# ============================================================== key switch (MX-style, no-name brown)
# Cherry MX1A datasheet drawing (datasheet.octopart.com/MX1A-11NW-Cherry-datasheet-34676.pdf):
#   PCB → top of housing 11.6 · stem above housing 3.6 · PCB → plate top 5.0 · pins 3.3 ·
#   plate cut-out 14.0 ± 0.05 · plate 1.5 ± 0.1 · pretravel 2.0 ± 0.6 · total travel 4.0 − 0.5
MX_CUT = 14.0            # [DS] plate cut-out — coupon tunes this per printer: 13.9 / 14.0 / 14.1
MX_PLATE_T = 1.5         # [DS] plate thickness the clips expect (± 0.15, drawing ± 0.006 in)
MX_TOP_W = 15.6          # [DS] top housing footprint
MX_HOUSING_ABOVE_PLATE = 6.6   # [DS] 11.6 (PCB → housing top) − 5.0 (PCB → plate top)
MX_STEM_ABOVE_HOUSING = 3.6    # [DS] stem top above the housing at rest
MX_ABOVE_PLATE = MX_HOUSING_ABOVE_PLATE + MX_STEM_ABOVE_HOUSING   # = 10.2 stem top above plate top
MX_BELOW_PLATE = 5.0     # [DS] plate TOP → housing bottom (PCB level)
MX_BODY_BELOW = 14.0     # [FREE] envelope of the bottom housing (just inside the cut-out)
MX_PINS = 3.3            # [DS]
MX_TRAVEL = 4.0          # [DS] total travel (tolerance −0.5)
MX_PRETRAVEL = 2.0       # [DS] actuation point ± 0.6
MX_FORCE_N = 0.56        # [DS] soft tactile operating force 2.0 oz (± 0.7 oz); tactile peak 2.3 oz ≈ 0.65 N
MX_POST_D = 5.5          # [TBD] keycap stem post Ø that dips into the housing at bottom-out (typical MX keycap 5.5; coupon v1 row E)
MX_WINDOW = 6.2          # [TBD] opening in the MX top housing the post enters at bottom-out (coupon v1 row E)
MX_STEM_ARM_L = 4.10     # [FREE] keycap socket cross: arm length (coupon: 4.05 / 4.10 / 4.15)
MX_STEM_ARM_W = 1.30     # [FREE] arm width (coupon: 1.25 / 1.30 / 1.35)
MX_STEM_DEPTH = 3.8      # [FREE] coupon v0 socket depth (the drawing gives no engagement value)
KEY_SOCKET_DEPTH = 3.4   # [FREE] key socket depth = stem top ↔ post end, so the stem bottoms at the design position
# v0.9 RIGID KEY (owner 2026-10-05: "Die Idee mit der Wippe ist an sich schlecht" — the v0.6–v0.8 rocker on stem forks
# scraped and did not stay in). Back to the v0.5 full cross sockets on Ø MX_POST_D posts (fit proven, coupon v0 row C), as a
# FIXED / FLOATING pair: the top socket (MX1) holds the stem in x and y; the bottom one (MX2) is slotted along y, so a pitch
# error between the plate cut-outs and the key's sockets cannot strain the two stems against each other (a rigid frame on
# two stems is over-constrained only along the line through them). Both switches are one key (firmware ORs them).
KEY_SOCKET_FLOAT = 0.25      # [FREE] MX2 socket: the y-arm slot runs through the post (open ends) and the x-arm slot is wider
                             #        by 2 × this → the stem floats ± this along y; still clamped in x by its y-arm's 1.30 width
KEY_END_TAPER = 0.2          # [FREE] the "funnel": the short-end walls are set back by this much from 5.6 behind the glass on
KEY_END_TAPER_RUN = 5.6      #        (linear from 0 at the glass); v0.6 rocker room, kept for the ±KEY_WOBBLE_DEG pitch
MX_PINCOUNT = 3          # [MEAS] 2 metal pins + centre post, no side pegs → plate mount (needs the 1.5 mm plate)

# ============================================================== audio
MIC_D, MIC_T = 13.14, 2.83               # [MEAS] INMP441 round module (2026-09-29) — desk rig only, 0.07 mm wider than a wing
MIC_MODULE = ("round black module with two flats; the LABELLED side carries the sound hole (≈ centre, ≈ 0.8 towards the "
              "L/R–GND row) → that side faces the room; mic chip on the back (bottom port). Pins: 2 columns × 3 at 2.54, "
              "columns ≈ 7.6 apart: SCK, WS, L/R | SD, VDD, GND")   # [PHOTO 2026-10-03]
LED_STRIP = ("owner's strip: black PCB, 5 V, pads +5V / Din / DO / GND, one cap per LED, ≈ 60 LED/m (≈ 16.7 pitch), 5050 "
             "LEDs with a white phosphor spot → most likely SK6812 RGBW (32-bit GRBW: tell the firmware). 5.0 × 5.0 LEDs do "
             "NOT fit the collar's LED windows (made for the 3.5 mm SK6812 MINI)")   # [PHOTO 2026-10-03]
MIC_CARRIER = (8.0, 8.0, 2.6)            # [FREE] v0.2: INMP441 (4.72 × 3.76 [DS]) on an 8 × 8 × 0.8 carrier PCB, bottom port;
                                         #        2.6 = PCB + mic + solder [TBD] — custom part
SPK_W, SPK_H, SPK_T = 19.32, 29.81, 4.57 # [MEAS] Waveshare 2030 cavity speaker, owner's calipers 2026-10-02 (vendor drawing:
                                         #        20 × 30 × 5.5). The "4PIN" item is a PAIR on one PH1.25 4-pin plug [DS].
                                         #        4.57 INCLUDES the white face ring (owner, 2026-10-02)
SPK_END_R = SPK_W / 2                    # [MEAS] "almost oval": near-semicircular ends (photo) → straight sides ≈ 10.5 long.
                                         #        v0.6: the hooks at the box corners catch nothing → move them onto the straight part
SPK_RING = (1.4, 0.1)                    # [TBD] white ring on the grille face: width (photo), thickness ("paper-thin", owner) →
                                         #        NOT a compressible gasket. Possibly the release liner of an adhesive ring [TBD]
SPK_TAB = (3.4, 0.5)                     # wire-exit tab at the CENTRE of one short end: width [TBD photo ±0.5], overhang [MEAS ≈ 0.5,
                                         #        owner 2026-10-06: it stopped the speaker at the cradle rib in the first kit print]
SPK_PORT_FACE = "large"                  # [DS] vendor outline: mesh grille on one 20 × 30 face
SPK_PORT_W, SPK_PORT_H = 16.5, 27.0      # [TBD] mesh inside the white ring, from the photo (±1); diaphragm behind it ≈ 8.6 × 12.6
AMP_W, AMP_H, AMP_T = 18.77, 17.7, 3.0   # [MEAS] MAX98357A breakout, owner's calipers 2026-10-03; 3.0 = PCB + tallest part
AMP_PCB_T = 1.56                         # [MEAS]
AMP_PARTS = ("7 pin holes (gold rings), header NOT soldered yet; a green 2-pin screw terminal for the speaker, loose — "
             "for a compact box, solder the wires straight to the pads instead (saves the terminal's height)")   # [MEAS]
AMP_BOARD = "purple MAX98357A 'I2S Amp' breakout (Adafruit 3006 layout); parts on the front only, back flat"   # [PHOTO]
AMP_PINS = ("LRC", "BCLK", "DIN", "GAIN", "SD", "GND", "Vin")   # [PHOTO] 2.54 pitch, row centred, ≈ 1.9 from the bottom edge
AMP_HOLE_PITCH = (13.97 + 12.9) / 2       # [FIT] 13.435: owner 2026-10-08 — 13.97 (photo) printed too wide, 12.9 (calipers: outer
                                          #        15.1 / inner 10.7, Ø 2.2) printed too close → the mean of the two
AMP_HOLE_D, AMP_HOLE_C = 2.2, ((AMP_W - AMP_HOLE_PITCH) / 2, 1.9)   # [MEAS Ø + pitch, holes assumed centred; y PHOTO ±0.5] top edge
AMP_PIN_D = AMP_HOLE_D - 0.3                # [FREE] printed locating pins for the 2 holes: 0.15 play per side
AMP_SPK_PADS = (3.5, 3.1)                  # [PHOTO ±0.5] speaker pads (−/+) pitch, centred, centre ↔ top edge

# ============================================================== optional sensors (bought 2026-09-29)
ALS_W, ALS_H = 16.36, 16.37              # [MEAS] VEML7700 breakout, owner's calipers 2026-10-03; I²C 0x10
ALS_PCB_T, ALS_T = 1.41, 3.85            # [MEAS] PCB thickness / total height at the tallest part
ALS_BOARD = "Adafruit VEML7700 breakout, product 4162 (silkscreen; vendor: 16.6 × 16.5 × 4.0)"   # [DS]
ALS_HOLE_D = 2.54                        # [DS] Adafruit 0.1" mounting holes (M2 / M2.5); 2 in the top corners
ALS_HOLE_C = (2.5, 2.0)                  # [PHOTO ±0.5] hole centre ↔ side edge, ↔ top edge (owner's photo on the mat, 2026-10-03)
ALS_PINS = ("VIN", "3Vo", "GND", "SCL", "SDA")   # [MEAS] pitch 2.54, row centred, ≈ 2.1 from the bottom edge [PHOTO ±0.5]
ALS_CHIP_C = (7.8, 8.5)                  # [PHOTO ±0.5] sensor window centre ↔ left edge, ↔ top edge; chip ≈ 2.1 × 7.1, long side
                                         #        top-bottom, same side as the 3.85 height → the light window goes there
RH_W, RH_H = 13.34, 10.5                 # [MEAS] SHT31-D breakout, owner's calipers 2026-10-03; I²C 0x44; needs room air, away
                                         #        from heat (ESP, amp, LDO)
RH_PCB_T, RH_T = 1.47, 2.57              # [MEAS] PCB thickness / total height at the tallest part
RH_PARTS = "6 pin holes (a 6-pin header comes loose) + 1 large hole"   # [MEAS]
RH_BOARD = "purple 'SHT3X' breakout (GY-SHT31-D style); the sensor chip side = front"   # [PHOTO 2026-10-03]
RH_PINS = ("VIN", "GND", "SCL", "SDA")   # [PHOTO] 4 pins at 2.54 along the bottom short edge, ≈ 1.6 from it; the two small
                                         #        holes at the top (AD = address, AL = alert) are not needed (0x44 default)
RH_HOLE_D, RH_HOLE_C = 2.3, (2.5, 2.9)   # [PHOTO ±0.5] the one large hole (top left, front view): Ø, centre ↔ left / top edge
RH_CHIP_C = (7.2, 3.75)                  # [PHOTO ±0.5] SHT31 chip (≈ 2.5 × 2.5) centre ↔ left / top edge (front view): it needs
                                         #        room air → vents in front of it, low in the box, walled off from ESP and amp heat
RADAR_W, RADAR_H, RADAR_T = 15.84, 22.03, 1.56   # [MEAS] HLK-LD2410C, owner's calipers 2026-10-03 (manual: 16 × 22); 5 V;
                                         #        H 22.03: caliper photo 2026-10-06 (10-03 said 22.26 → the v0.9.2 tray was
                                         #        ≈ 0.5 too long, the board slid about);
                                         #        sees through thin plastic, not metal
RADAR_T_PINS = 11.4                      # [MEAS] total height with the soldered pin header (thickest point)
RADAR_PINS = ("TX", "RX", "OUT", "GND", "VCC")   # [PHOTO] 5 pins at 2.54 along one LONG edge, ≈ 1.3 from it, roughly centred
RADAR_FRONT = ("antenna side = the two gold patch antennas (TX/RX) + the radar chip + a status LED → faces the room through "
               "thin plastic, nothing metal in front; the header's plastic body and pins are on the OTHER (component) side, "
               "pointing away from the room")   # [PHOTO 2026-10-03]
RADAR_B_W, RADAR_B_H = 7.0, 35.0         # [DS] HLK-LD2410B 7 × 35 (the slim version, 1.27 mm pin pitch)

# ============================================================== design choices
KEY_WALL = 1.0           # [FREE] keycap shell wall around the touch board
KEY_FIT = 0.15           # [MEAS] clearance board frame ↔ shell pocket, per side: real touch board in the PETG print
                         #        (A1, 0.4 nozzle, 0.10 layers) fits "extremely perfect" (owner, 2026-10-02); hard to get out
                         #        → §11. Still sets the key's OUTER size (KEY_W/H/R) — that stays fixed
KEY_POCKET_FIT = 0.10    # [FIT] the pocket's real clearance per side: the owner prints the RoomKey parts with a 0.2 nozzle
                         #        now (2026-10-08) and 0.15 came out loose → 0.10 (the radar tray needed the same −0.05);
                         #        the shell wall grows 0.05 inwards, the outside of the key is unchanged
KEY_GAP = 1.0            # [FREE] shadow gap key ⇄ rocker cut-out
KEY_PROUD = 8.0          # [FREE] key top above rocker front
KEY_W = TB_W + 2 * (KEY_FIT + KEY_WALL)      # 26.85
KEY_H = TB_H + 2 * (KEY_FIT + KEY_WALL)      # 46.80
KEY_R = TB_CORNER_R + KEY_FIT + KEY_WALL     # 6.90
CUT_W = KEY_W + 2 * KEY_GAP                  # 28.85
CUT_H = KEY_H + 2 * KEY_GAP                  # 48.80
KEY_BACK_T = 1.6         # [FREE] shell back wall; DIN 965 M2 countersunk heads (1.2) sit flush
KEY_BOTTOM_CLEAR = 0.5   # [FREE] shell back ↔ MX housing top at full travel
KEY_WELL_CLEAR = 0.25    # [FREE] key skirt ↔ fixed light-guide collar, per side (linear guide)
KEY_SKIRT = 3.8          # [FREE] skirt behind the key back (shell wall continued) — guided in the collar over the whole stroke
MX_SW_POS = ((0.0, 15.0), (0.0, -13.0))      # [FREE] two switches on the long axis, pitch 28: the key overhangs them by only
                                             #        8.4 (top) / 10.4 (bottom) — about a 1u keycap's stem-to-edge — so end
                                             #        presses act like edge presses on a keycap (desk-rig test, insert doc §3);
                                             #        MX2's spring stays ≈ 8 mm from the antenna chip (RF test)
MX_GUIDE = ("2 × the same brown (tactile) switch under one rigid key (v0.9): fixed socket on MX1, floating on MX2; wired on "
            "their own pins and ORed in firmware (key_raw) — end-press binding: desk rig R1")
SWITCH_PITCH_Y = MX_SW_POS[0][1] - MX_SW_POS[1][1]
SPK_ON_EDGE = True       # [FREE] speaker stands on its 5.5 mm edge behind the right wing
CLEAR = 0.5              # [FREE] minimum clearance between parts

# printer / material
XY_COMP = {"PLA": 0.10, "PETG": 0.12, "ABS": 0.20}   # [FREE] hole oversize, tuned by the coupon


def key_stack():
    """Depths (d, mm into the wall) of the key module at rest. Positive d = behind the rocker front."""
    s = {}
    s["glass"] = -KEY_PROUD
    s["pcb_front"] = s["glass"] + TB_FRONT_T
    s["pcb_back"] = s["pcb_front"] + TB_PCB_T
    s["standoff_end"] = s["pcb_back"] + TB_STANDOFF
    s["key_back"] = s["standoff_end"] + KEY_BACK_T
    s["mx_top"] = s["key_back"] + MX_TRAVEL + KEY_BOTTOM_CLEAR
    s["stem_top"] = s["mx_top"] - MX_STEM_ABOVE_HOUSING
    s["post_end"] = s["mx_top"] - 0.2
    s["skirt_end"] = s["key_back"] + KEY_SKIRT
    s["plate_front"] = s["mx_top"] + MX_HOUSING_ABOVE_PLATE
    s["plate_back"] = s["plate_front"] + MX_PLATE_T
    s["mx_bottom"] = s["plate_front"] + MX_BELOW_PLATE
    s["mx_pins"] = s["mx_bottom"] + MX_PINS
    return s


def validate(verbose=True):
    errs, warns, oks = [], [], []
    g = globals()
    for k, v in FROZEN.items():
        (errs if abs(g[k] - v) > 1e-9 else oks).append(f"frozen {k} = {g[k]}")

    wing = (ROCKER_W - CUT_W) / 2
    band = (ROCKER_H - CUT_H) / 2
    (errs if CUT_W >= ROCKER_W or CUT_H >= ROCKER_H else oks).append(
        f"key cut-out {CUT_W:.2f} × {CUT_H:.2f} inside the {ROCKER_W:.0f} × {ROCKER_H:.0f} rocker")
    (warns if band < 3.0 else oks).append(f"rocker band above/below the key {band:.2f} mm (≥ 3 for strength)")
    (oks if wing >= 10 else warns).append(f"side wing {wing:.2f} mm (room for perforation + a thumb)")


    for (x, y) in MX_SW_POS:
        mx_x = KEY_W / 2 + KEY_WELL_CLEAR - (abs(x) + MX_TOP_W / 2)
        mx_y = KEY_H / 2 + KEY_WELL_CLEAR - (abs(y) + MX_TOP_W / 2)
        post = KEY_W / 2 - KEY_WALL - (abs(x) + MX_POST_D / 2)
        ok = min(mx_x, mx_y) >= 0.3 and post >= 1.0
        (oks if ok else errs).append(
            f"switch at ({x:+.1f}, {y:+.1f}): housing {min(mx_x, mx_y):.2f} mm inside the key well, "
            f"stem post {post:.1f} mm inside the key back")
    gap_y = SWITCH_PITCH_Y - MX_TOP_W
    (oks if gap_y >= 6.0 else warns).append(
        f"{gap_y:.1f} mm between the two switch housings (ribbon cable passes there, needs ≥ 6)")

    s = key_stack()
    (oks if abs((s["post_end"] - s["stem_top"]) - KEY_SOCKET_DEPTH) < 1e-6 else errs).append(
        f"key socket {KEY_SOCKET_DEPTH} deep = stem engagement {s['post_end'] - s['stem_top']:.1f} → stem bottoms at the design depth")
    (oks if s["skirt_end"] + MX_TRAVEL <= s["plate_front"] - 1.0 else errs).append(
        f"key skirt ends at d {s['skirt_end']:.1f} ({s['skirt_end'] + MX_TRAVEL:.1f} pressed), switch plate at {s['plate_front']:.1f}")
    total = s["mx_pins"] - s["glass"]
    oks.append(f"key stack {total:.1f} mm total, {s['mx_pins']:.1f} mm behind the rocker front "
               f"(was 36.0 / 28.0 with the misread MX height)")

    if SPK_PORT_FACE is None:
        warns.append("speaker sound-port face unknown → duct design pending (measure when it arrives)")
    if AMP_W == 18.0:
        warns.append("MAX98357A board size is a placeholder → measure")
    if TB_STANDOFF_THREAD is None:
        warns.append("touch-board brass standoffs assumed female M2 (key shell screws into them) → check")
    warns.append("LD2410C 16 × 22 does not fit a 13 mm wing — see insert_params.py (radar deferred)")
    warns.append(f"INMP441 round module Ø{MIC_D} is wider than the wing → wall insert uses an 8 × 8 carrier (custom)")
    if MX_PINCOUNT == 3:
        oks.append("key switch is plate mount (3-pin) → 1.5 mm switch plate")

    if verbose:
        for m in errs:
            print("ERROR   ", m)
        for m in warns:
            print("WARNING ", m)
        for m in oks:
            print("OK      ", m)
        print(f"\n{len(errs)} error(s), {len(warns)} warning(s), {len(oks)} ok")
    return not errs


if __name__ == "__main__":
    raise SystemExit(0 if validate() else 1)

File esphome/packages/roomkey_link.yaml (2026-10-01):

# ─────────────────────────────────────────────────────────────────────────────
# RoomKey ⇄ door, device to device (voice v2, WIP; aikos features/sprechen.md §4b, contract in aikos_voice README #11):
#   key → door   key_state      0 idle, 1 in the call, 2 holding (talks). A sensor, not binaries: the door's call
#                               model needs the refresh every second, and a remote binary only fires on change.
#   door → keys  door_call_id   the door's call (0 = none), door_answered (someone answered, R19), floor_key (last
#                               octet of the key that has the floor, 0 = none → "besetzt" when another key holds)
# packet_transport over UDP 18511, encrypted with key_link_key (one key for all RoomKeys and the door), rolling code.
# The key sends unicast to the door talk computer (sent on change + every second); the door broadcasts.
# The key is compiled in (secrets.yaml). Owner's decision 01.10.: voice v2 runs on this; afterwards pairing in the
# HA GUI with a shared aikos_link block replaces this package (aikos features/kopplung.md).
#   bell → keys  boot_id, presses, ringing (provider aikos-intercom-bell, ring_transport_key, unicast from the bell):
#                the DIRECT ring path, so the key rings without Home Assistant (system test F1, 01.10.)
# secrets.yaml: key_link_key, ring_transport_key, door_talk_host (IP of the door talk computer).
# ─────────────────────────────────────────────────────────────────────────────
substitutions:
  door_talk_host: !secret door_talk_host

esphome:
  on_boot:
    - priority: -180
      then:
        - lambda: |-
            // a key that was never told where the door is uses the door talk computer from secrets (system test F3)
            if (id(door_address).state.empty()) {
              auto call = id(door_address).make_call();
              call.set_value("${door_talk_host}:${intercom_port}");
              call.perform();
            }
            id(doorbell_direct_sensor).update();   // both ring counters start at 0 (a baseline for tests)
            id(doorbell_rx_sensor).update();

udp:
  id: rk_link_udp
  addresses: ["${door_talk_host}"]

packet_transport:
  - platform: udp
    id: rk_link
    udp_id: rk_link_udp
    update_interval: 1s
    rolling_code_enable: true
    encryption: !secret key_link_key
    sensors:
      - key_state
    providers:
      - name: aikos-intercom-talk
        encryption: !secret key_link_key
      - name: aikos-intercom-bell
        encryption: !secret ring_transport_key

sensor:
  # key_state (0 idle, 1 in the call, 2 holding) comes from the voice package: roomkey_intercom.yaml (own audio) or
  # roomkey_voice.yaml (aikos_voice). Door messages go to the UI here and to the voice package's scripts.
  - platform: packet_transport
    id: rk_door_call_id
    provider: aikos-intercom-talk
    remote_id: door_call_id
    internal: true
    on_value:
      - lambda: |-
          const uint32_t call_id = std::isnan(x) ? 0 : (uint32_t) x;
          roomkey::ctl().set_door_call(call_id != 0);
          roomkey::ctl().door_call_id(call_id);   // R22: a new call (or none) empties the chat
          id(rk_door_msg).execute(call_id != 0, call_id, id(rk_door_answered).state);
  - platform: packet_transport
    id: rk_floor_key
    provider: aikos-intercom-talk
    remote_id: floor_key
    internal: true
    on_value:
      - lambda: |-
          // another key has the floor: this key's hold is "besetzt" (and sends nothing, see roomkey_intercom.yaml)
          int own = 0;
          for (auto &ip : network::get_ip_addresses()) {
            if (!ip.is_ip4()) continue;
            char buf[network::IP_ADDRESS_BUFFER_SIZE];
            const char *dot = strrchr(ip.str_to(buf), '.');
            if (dot != nullptr) own = atoi(dot + 1);
            break;
          }
          roomkey::ctl().set_floor_busy(x > 0 && (int) x != own);
          id(rk_floor_msg).execute(std::isnan(x) ? 0 : (int) x);
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

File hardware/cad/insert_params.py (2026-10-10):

"""RoomKey wall insert v0.8 (DRAFT / WIP, AI-assisted, not certified) — every dimension of the in-wall part, both variants.

    python3 hardware/cad/insert_params.py          # validate L and S
    python3 hardware/cad/insert_params.py L        # one variant
    python3 hardware/cad/insert_params.py --tbd    # every [TBD] value and what to measure

v0.2 (after review round 1): SELV-only insert; floating plate on 4 tactile switches; light-guide collar; mic carrier;
    cable U-loop; horizontal hub; installation topologies T1–T4 / S1–S3.
v0.3 (after review round 2, see hardware/reviews/insert-v0-review-log.md):
  * No foam gaskets: the mic carrier is bonded to the plate (moves with it); the speaker path is sealed at the speaker
    (face gasket + plenum floor), the plate–deck gap is part of the front volume. Three small soft pads preload the plate.
  * Glow ring = a translucent rim of the plate around the key opening (co-printed, natural PETG), lit from the collar
    behind it → visible from every angle. LEDs centred on the collar's thick (2.6) corners.
  * Nub-gap chain from the flange datum (carrier rests on the flange), explicit tolerance list, per-switch shims.
  * Key: the MX stems are the guide; the key skirt is on the long sides only (free pitch for edge presses), the collar
    limits roll.
  * Frame rims on all four sides; stainless load plates under the box screws; speaker snap hooks; island ribs.
  * Topologies: switch-box inventory first, TN-C precondition, core table, "new cable" outcome, T4 needs its own 12 V,
    power-limited SELV source, labelling, ES75/Kaiser facts corrected.
  * validate(): INFO lines for assumptions (never counted as OK), fit-critical [TBD] rules are hard.
v0.4 (after review round 3):
  * Plate switches: SMD Omron B3FS-1002P (3.1 ± 0.2) on flat-backed carriers (no solder under the datum); 1.4 mm more
    front-zone depth (works down to 7.6 mm rocker-to-wall).
  * Key: MX at (0, +15) / (0, −13) (overhang 8.4 / 10.4 like a keycap edge); no stop bosses, no pitch model (it was not
    physical); end presses are a desk-rig test with a stabiliser fallback.
  * Hub: 250 V entry fuse, eFuse on the hub branch (a hub short no longer collapses the 12 V of the light path), FMEA.
  * Terminal zone = 5 modelled WAGO 221-412; speaker preloaded onto its face gasket; key-back cable channel.
  * CAD checks the key + stems wobbled ±1.5° without the key ↔ housing exemption; one layer height (0.10) for plate,
    chassis and coupon; V-0 chassis mandatory.
v0.5 (after review round 4; NOT reviewed by a fresh round — the loop stopped, see the review log):
  * Q1 threshold derived from the retention (≥ 8.9 mm), not only from the switch stack.
  * Misconnection: matrix per conductor (the entry fuse protects only one case), verification + RCD as preconditions.
  * Hub: RELAY_DRIVE pull-down + qualifier (IO5 floats at reset), eFuse checked against the summed peak with tolerance
    (60 V class, OVLO 17 V, SMBJ24A), bleeder in L and S; SNT61 overload = Q4f.
  * RF spring distance corrected (sign error: 8.1 mm pressed, WARN); thicker speaker hooks; mic wire well with an S-loop;
    key channel along the real header; touch-vs-key and power-cut items with assumption, test and fallback.
v0.6 (the owner's first print and wishes; NOT reviewed):
  * Rocker key: both MX read separately, centre press = both (forks, stop bosses, tapered ends, rock + wobble checks).
  * Wider middle cable slot + header slots for pins / wires straight back from the touch-board header.
  * Real speaker dimensions, LED corner notches (WS2812B-MINI 3535, 2.0 high), push-out removal.
  * §6 practice box and §7 kit (whole RoomKey in one box, bench supply) — prototypes only.
v0.8 (the owner's first kit assembly, 2026-10-04: the rocker key fell out; NOT reviewed):
  * Key catch: a rigid nub on each side skirt in a groove of the collar (open to the back, closed to the room) → the key
    is captive; the collar is no longer glued. Stem fork gap 4.10 → 3.90 (the stem arm is ≈ 4.0: 4.10 clamped nothing).

Tags: [DS] datasheet / norm / vendor drawing (source in SOURCES) · [MEAS] measured on the real part ·
      [FREE] design choice · [TBD] placeholder or assumption until measured (listed by --tbd).
Coordinates: front view, origin = plate centre on the plate FRONT face; x right, y up;
      d = depth into the wall (+). CAD maps (x, y, d) -> (X, Y, Z = -d): +Z points into the room.
Nothing here is certified. All 230 V work: a qualified electrician of a registered installation company (NAV §13,
insert-design.md §9).
"""
import math
import os
import sys

HERE = os.path.dirname(os.path.abspath(__file__)) if "__file__" in globals() else os.path.join(os.getcwd(), "hardware", "cad")
sys.path.insert(0, HERE)
import roomkey_params as R  # noqa: E402

VARIANTS = ("L", "S")
VERSION = "0.10.4"
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

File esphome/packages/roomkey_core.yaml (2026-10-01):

# ─────────────────────────────────────────────────────────────────────────────
# RoomKey core: UI controller, fonts, key wiring, local entities.
# Board-agnostic — expects the board contract (lcd, backlight, key_raw, rk_led).
# ─────────────────────────────────────────────────────────────────────────────

esphome:
  includes:
    - src/roomkey_ui.h
  on_boot:
    - priority: -100   # after LVGL is set up
      then:
        - lambda: |-
            auto &c = roomkey::ctl();
            c.set_language("${language}");
            c.cfg.room = "${room_name}";
            c.cfg.door = "${door_name}";
            c.cfg.has_touch = ${has_touch};
            c.cfg.bright = id(screen_brightness).state / 100.0f;
            c.cfg.dim_after_ms = (uint32_t) id(dim_after).state * 1000;
            c.fonts.small = id(f_small)->get_lv_font();
            c.fonts.body = id(f_body)->get_lv_font();
            c.fonts.title = id(f_title)->get_lv_font();
            c.fonts.big = id(f_big)->get_lv_font();
            c.fonts.icon_sm = id(f_icon_sm)->get_lv_font();
            c.fonts.icon_md = id(f_icon_md)->get_lv_font();
            c.fonts.icon_lg = id(f_icon_lg)->get_lv_font();
            c.hooks.backlight = [](float b) {
              if (b <= 0.001f) { auto call = id(backlight).turn_off(); call.perform(); return; }
              auto call = id(backlight).turn_on();
              call.set_brightness(b);
              call.perform();
            };
            c.hooks.led = [](uint32_t col, const char *fx) { id(rk_led).execute((int) col, std::string(fx)); };
            c.hooks.gesture = [](const char *g) {
              static const char *const KNOWN[] = {"press", "hold", "tap", "swipe_up", "swipe_down", "talk_start", "talk_stop"};
              for (auto k : KNOWN) if (strcmp(k, g) == 0) { id(key_gesture).trigger(g); return; }
            };
            c.build(lv_screen_active());

binary_sensor:
  - id: !extend key_raw
    on_press:
      - lambda: roomkey::ctl().key(true);
    on_release:
      - lambda: roomkey::ctl().key(false);
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

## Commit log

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2026-09-30 HA-dev: real Home Assistant contract test, doorbell handover
    - homeassistant/dev/roomkey.yaml: RoomKey package for the shared dev Home Assistant
    (contract + roomkey_test_* stand-ins); doorbell stand-in removed now that the
    Klingelbox bell provides binary_sensor.doorbell_button
    - tools/ha_contract_test.py: 11/11 end-to-end checks against a real Home Assistant
    (lights, disarm policy NIGHT allowed / AWAY refused, ring → answer/talk/hangup events)
    - Key counts received doorbell presses (diagnostic sensor) to prove storm ringing
    arrives completely; every off→on rings, no cooldown
    - API reboot_timeout 0s: the key keeps working while Home Assistant is away
    - Intercom: the VoIP stack's E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
    [ha_contract_test.py, privacy_scan.py]
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2026-09-30 Talk transcripts: who is speaking, spoken language, push-to-talk end, audio fixes
    - tools/talk_identity.py: rules engine rewritten (token-based, side-aware, titles, several people,
    international names, dialect, apposition) + guarded local-LLM fallback; 57 self-tests
    - tools/transcribe_publish.py: German text first (0.7-1 s after release), spoken language and
    original words follow; non-German speech Whisper leaves as is (e.g. English) is translated by the
    local LLM; doorstep word-list hint with echo detection; padding; household names
    - tools/rtp_recorder.py: per-sender recordings, comfort-noise end packet (PT 13), adaptive silence split,
    drops sub-0.3 s snippets; tools/rtp_play.py: s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
    [roomkey_audio.h, roomkey_ui.h]
2026-10-01 Push-to-talk at the door: hold always talks, leak fixed, key switch on IO1/IO2
    - Room audio reaches the door only while the key is held; the test recording after a ring goes to the
    transcriber only (verified: 0 audio packets at the peer). The test switch stays off by default.
    - Hold = talk to the door, also without a ring ("Door address" entity as the standing peer); short press =
    lights (after 0.35 s), double press = menu; armed alarm: hold = disarm. No hang-up: a conversation ends
    after 2 min without audio; the call screen shows only while something happens (8 s after the last activity).
    - Fixed: an if/else split that stopped every transmission, and the 2-min timer that ended a fresh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
    [board_c6_lcd_147.yaml, insert_drawings.py, insert_wallcheck.py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]
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2026-10-01 Live text from the door on the RoomKey while the visitor is still talking
    Whisper does not stream, so tools/talk_live.py re-transcribes the growing utterance about once a second while
    the talk button is held and publishes sensor.talk_live_door (text grows, speaker as soon as the rules see it,
    final: true at the end); the finished transcript still follows ~1 s after release. rtp_recorder --live wires it
    in; the service script enables it for the door side (AIKOS_LIVE). The RoomKey shows the live text in place of the
    bell / ear and types new letters in, catching up when far behind; the final transcript replaces it.
    [roomkey_ui.h]
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2026-10-01 RoomKey: visitor-type icon, "?" for self-declared types, red line for emergencies
    The visitor line at the top of the ring and call views now reads
    [type icon] name [?]:
    - the icon comes from speaker_role (door transcript and live text), 29 types
    plus doorbell for "nobody said who" (aikos features/sprechen.md §2c; MDI has
    no "pharmacy" any more → mortar-pestle-plus)
    - "?" badge for types people claim to get in: police, officials, utility,
    trades ("laut Besucher")
    - urgent → the line turns red, with the alert icon if no other type is known,
    and the screen wakes up
    - reset with a new visitor / at the end of the call; re-applied on every new
    transcript (HA only resends changed att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
    [roomkey_core.yaml, roomkey_ui.h]
2026-10-01 RoomKey: bench link talk_held / in_call to the door (off); ignore secrets backups
    - packages/roomkey_link.yaml: packet_transport over UDP 18511, unicast to the
    door talk computer, key_link_key, rolling code, 1 s + on change (contract by
    the door thread). Not included yet: the door's v2 consumer doesn't exist, and
    the target is GUI pairing with a shared aikos_link block (features/kopplung.md)
    - door address and keys come from secrets.yaml (example updated); backups of
    secrets.yaml are git-ignored
    [roomkey_link.yaml]
2026-10-01 RoomKey voice v2: call settings on the key, speech-based call end, link on
    Settings (aikos features/sprechen.md §4b B), kept in flash, work without HA:
    - switch "Hear visitor before answer" + time "Hear visitor from/until"
    (R17.13; not in quiet hours unless urgent, R17.15)
    - switch "Front door ends call" (R17.8; edge closed → open of
    binary_sensor.aikos_front_door)
    - number "Call silence end" (10 s) and "Call max length" (300 s)
    A call now ends after "Call silence end" seconds without SPEECH either way:
    own talk, door audio above its noise floor (VoiceGate), or new visitor
    text. Packets no longer count (the v2 door mic sends all call long). The
    end rules also run without network.
    Vo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
    [roomkey_audio.h, roomkey_link.yaml, roomkey_ui.h]
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2026-10-01 RoomKey: the conversation as a chat on the key (R17.6)
    - reads sensor.aikos_call_log (messages_json), the one source for both
    screens; the last 10 messages
    - call view while listening: chat bubbles instead of the ear: visitor left
    with type icon and who (cyan), this house right (green), red frame for an
    emergency; the visitor's words in progress follow below (live text)
    - a new message brings the call view back; the visitor's final words replace
    the live text
    - short press in the call view = "Older": 100 px up, at the top back to the
    newest; back to the newest after 8 s by itself
    - laid out by hand (this LVGL build has no flex)
    Simulator tour: 07c chat, 07d older, 07e back to newe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
    [roomkey_ui.h]
2026-10-01 RoomKey: join a call answered elsewhere (R19); swipe through the chat (R18)
    R19 (owner, 01.10.): it rings, another room answers → this key stops hearing
    the visitor before answering (ringing stops) and shows "Answered · Press to
    listen in" while the door's call runs (binary_sensor.aikos_intercom_talk_in_call;
    2 min if unknown). One press joins (listen, chat), holding joins and talks.
    Waving the ring away (touch X / swipe down) offers no join.
    R18 (touch boards): the chat scrolls with a finger like on a phone; while the
    user reads, new text doesn't pull it back (after 8 s it returns to the
    newest). The chat hides the talk disc, so the meter strip below it becomes the
    press-and-hold talk b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
    [privacy_scan.py, roomkey_core.yaml, roomkey_ui.h]
2026-10-01 RoomKey link v2: key_state to the door; door_call_id, door_answered, floor_key from it
    As agreed with the door thread (aikos_voice README #11): one sensor key_state
    (0 idle, 1 in the call, 2 holding) replaces talk_held + in_call, because the
    door's call model needs the refresh every second and a remote binary only fires
    on change. Published on change; the transport resends it every second.
    From the door (broadcast, provider aikos-intercom-talk, key_link_key):
    - door_call_id (0 = no call) → the door's call for the join offer (R19)
    - door_answered → no more listening before an answer (R19)
    - floor_key (last octet) → another room has the floor: the hold shows
    "Busy · another room talk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
    [roomkey_link.yaml, roomkey_ui.h]
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2026-10-01 Live text: a Whisper revision appears at once; only new words are typed
    Every sensor.talk_live_door update carries the whole utterance so far, and
    Whisper revises earlier words now and then. The key used to retype from the
    first changed letter, so a long utterance (110 s on the v2 door before the
    transcriber split it) looked as if it streamed in several times. Now a
    revision of what is on screen is shown at once and only new words type in;
    a new utterance (the live sensor's state = its start) types from the start.
    The key always replaced the live line, never appended.
    Simulator tour: 22 revision shown at once.
    [roomkey_ui.h]
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2026-10-01 Direct ring path from the bell (F1); the simulator knows the door (F3)
    System test 01.10.: with Home Assistant down the key did not ring (F1), and
    the simulator never learned the door, so it could not join a call (F3).
    - F1: consumer for the bell's direct packets (provider aikos-intercom-bell,
    ring_transport_key, UDP 18511): a new press number rings without HA; the
    number seen first after the key boots is history; a bell reboot counts its
    presses. HA's ring of the same press within 1.5 s doesn't ring again, so a
    dismissed ring stays dismissed. Diagnostics: "Doorbell presses direct"
    next to "Doorbell presses received" (via HA), both 0 from boot, and
    "Bell boot id (direct)" (= the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
    [roomkey_link.yaml]
2026-10-01 A hold the timer never saw still counts where holding means talk
    F3 re-test 01.10.: a 250 ms press on the simulator toggled the light instead
    of joining. 250 ms is a hold (talk_hold_ms 220) and the desk key joined by
    talking; the simulator's loop was late (~1 s), so key-down and key-up arrived
    together, the hold timer never fired and the press counted as short. Now a
    key-up after the hold threshold without a fired hold counts as the hold where
    holding means talk (home, call). Never for disarming. Tour shot 21b.
    [roomkey_ui.h]
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2026-10-01 R21: offer "Press to listen in" also for a call nobody rang for
    Owner 01.10. (R21): when a call runs at the door that this key is not in,
    including one another room started without a ring, the key offers to join;
    one press joins (listen), holding joins and talks, as in R19. Titled "Call at
    the door" ("Gespräch an der Tür"); after a ring answered elsewhere it stays
    "Answered". The offer keeps the LED off and doesn't wake the screen (night);
    waving it away on a touch key holds until that call ends. Tour shot 16b.
    [roomkey_ui.h]
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2026-10-02 Versions 0.3.0 (voice v2) / 0.2.1 (own audio); diagnostic "Chat lines"
    W5 of the aikos stack's re-acceptance (02.10., 71/71 with the desk on v2):
    - the desk still reported 0.2.0 after the v2 flash, so the call archive and
    the register could not tell the builds apart. roomkey_v2.yaml is 0.3.0,
    roomkey.yaml (own audio, the fallback) 0.2.1. Shown with the next flash.
    - "Chat lines" (diagnostic): how many chat messages the key shows now, so a
    test can prove R22/R27 from HA (the screen is too small for bench photos).
    The tour logs it with every shot: 3 in a call, 0 after it ends and at the
    start of the next, 3 again after joining a running call.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
    [roomkey_ui.h]
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2026-10-02 Touch board on the bench (roomkey_touch.yaml); backlight/LED only on change
    - roomkey_touch.yaml: the same firmware as roomkey_v2.yaml on the Waveshare
    ESP32-C6-Touch-LCD-1.47 (aikos-roomkey-touch). First flash 02.10.: Wi-Fi,
    display driver, AXS5106L touch (0x63) and IMU (0x6B) come up, no errors.
    - Fix: render() runs with every door packet (~1/s) and re-sent the
    backlight and the status LED / glow ring each time, so the light entities
    published to HA every second. Now only a change is sent (touch board: from
    ~4 light updates/s to none while idle).
    [roomkey_ui.h]
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2026-10-02 Touch board: prod-like parts (WIP): sensors package, speaker, header plan
    The parts arrived 02.10.; the touch board gets all of them (bench, jumper
    wires first):
    - board_c6_touch_lcd_147.yaml: the header H1 from Waveshare's schematic, as
    RoomKey uses it. INMP441 L/R goes to GND (3 GND pins here), so IO3 is free
    for the radar: LD2410C TX -> IO3, RX <- IO5 (the IMU's INT1, high-Z unless
    enabled, which RoomKey never does).
    - roomkey_mic.yaml no longer drives an L/R pin; the desk board package keeps
    its GPIO0 held low (one GND pin there).
    - roomkey_sensors.yaml: VEML7700 (0x10) and SHT31-D (0x44) on the board's I2C
    bus, LD2410C on UART 256000 (presence, moving/still, distance).
    - roomk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
    [board_c6_lcd_147.yaml, board_c6_touch_lcd_147.yaml]
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2026-10-04 Hardware: insert v0.6 (rocker key, wire slots), practice box and kit v0.7, real FreeCAD renders
    All prototype work, WIP and not reviewed. SELV only; nothing here goes near 230 V.
    Insert v0.6, from the owner's first print and fit test:
    - The touch board fits; it comes out by pushing it through the screw hole. The insert has no USB port.
    - Rocker key: the two key switches are read separately, and a press in the middle triggers both. It has forks, stop bosses and tapered ends.
    The CAD checks it at rest, pressed, rocked both ways and wobbled.
    - The middle cable slot is wider, and new header slots let pins or wires run straight back from the touch-board header.
    - Real speaker dimensions, and c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
    [chassis_L.step, chassis_L_print.stl, chassis_S.step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]
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2026-10-06 Practice frame: humidity-sensor vents on the centre line
    The owner asked for the frame's vent holes to sit in the middle. The 3 × 3 vents sat over the SHT31-D chip, which is
    off-centre on its board, so they were 2.92 mm right of centre. Now the board sits 2.92 mm left of centre, so its chip
    and both vent groups (front grid, bottom inlets) are at x 0.
    Checks: 0 collisions, the same sensor gaps (0.2 to the frame, 1.0 to the chassis), validate() 0 errors. The renders
    and wire 38 (+5 mm) are updated.
    [kit-v0.7_assembly.step, kit-v0.7e_ansicht.FCStd, practice_frame_1x.step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]
2026-10-06 Kit carrier: wall round the pin holes (first print opened them over the edge)
    The owner's first print of the back carrier showed 3 of the 4 pin holes running over the part's edge. The CAD had only
    0.25–0.35 mm between those holes and the outline, so the slicer dropped the wall.
    - Each hole now has a round pad with 1.2 mm wall (KIT_PAD_WALL).
    - The radar window is cut cleanly open to its −x edge, so no 0.1 mm skin is left.
    - build_kit reports every carrier web from a section through the plate (rule ≥ KIT_MIN_WEB 0.8). The thinnest is
    0.8, between a hole and the window.
    Checks: 0 collisions at rest and with the key pressed; carrier ↔ speaker 0.58 (was 0.93); no new wire contacts.
    C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
    [kit-v0.7_assembly.step, kit-v0.7_printed-assembly.stl, kit-v0.7e_ansicht.FCStd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]
2026-10-06 Insert v0.8: the rocker key is captive (it fell out at the first kit assembly)
    The owner assembled kit v0.7: "nothing stops the rocker, with the ESP32 module, from simply falling out". My error had
    two parts:
    - The stem forks had a 4.10 mm gap. That is the cross socket's slot length, which has play; the stem arm is about
    4.0 mm. So the forks clamped nothing.
    - Even a tight fork is a weak spring and could not hold the key against a pull.
    v0.8:
    - Key catch: a rigid nub on each side skirt (6.0 × 1.0, 0.55 proud) runs in a groove in the collar's inner face. The
    groove is open to the collar's back and closed towards the room, 0.45 in front of the nub at rest. Pressing and
    rocking stay fre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
    [collar.step, collar_print.stl, desk-replica_assembly.step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]
2026-10-06 Hardware: build guide, retire the 2-box desk replica, version-free kit file names
    - New hardware/BUILD.md: the desk prototype, step by step.
    - Status table: what is printed and fits, and what is WIP. The rocker key concept was dropped by the owner on
    2026-10-05, and its replacement is in design.
    - Bought and small parts, the print list with settings, assembly order, service, power and first tests.
    - Wiring and bench power point to docs/wiring-touch-board.md (the firmware-checked pinout).
    - Retired and removed: the 2-box desk replica (sensor cover in a second box, rejected 2026-10-03). Removed
    make_desk_replica.py, its 13 model files, the sensor-cover builders in desk_lib.py and t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
    [desk-replica_assembly.step, desk-replica_printed-assembly.stl, desk_amp_tray.step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]
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2026-10-08 Insert v0.9: rigid key on both MX again (the rocker is dropped)
    The owner's verdict on 2026-10-05: the rocker idea is bad in itself. It may
    scrape instead of glide, and it did not stay in. Of three options (rigid key,
    one MX + 2u stabiliser, printed plunger) the owner chose the rigid key.
    - Key shell: the stem forks and rocking pads are gone. The v0.5 posts with
    cross sockets are back: fixed on MX1 (top), floating on MX2 (bottom; its
    y-arm slot runs through the post, the x-arm slot is 1.80 wide, so the stem
    floats +/-0.25 along y and a pitch error cannot strain the two stems).
    - The v0.8 catch (nubs in collar grooves) and the 4 stop bosses (3.4) stay.
    - CAD: the rocked state is replac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
    [insert-L_assembly.step, insert-L_printed-assembly.stl, insert-S_assembly.step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]
2026-10-08 Insert v0.9.1: speaker tab slot and full-width radar window (first kit fit)
    The owner's kit fit on 2026-10-06: key, amplifier and microphone fit; two
    parts did not.
    - Speaker: its ~0.5 mm wire tab at the centre of one short end hit the
    cradle rib. The +y rib now has a blind slot for it, open to the back
    (speaker and wires come from behind), closed to the front, with the rib
    thickened so 0.8 of wall stays behind it (no fork). The +y snap hook is
    dropped: the slot cut its root and left it as a loose second solid.
    - Radar: SMD parts along the long edge opposite the header sat on the
    carrier plate. The antenna window now spans the full board width; the
    board rests on its two short e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
    [chassis_L.step, chassis_L_print.stl, chassis_S.step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]
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2026-10-08 Kit view file named after the parts' version, no FreeCAD backups in git
    The overview was kit-v0.7e_ansicht.FCStd (the kit concept's version, hard-
    coded) although the parts are v0.9.1. view_kit.py and render_kit.py now
    build the name from insert_params.VERSION: kit-v0.9.1_ansicht.FCStd.
    A FreeCAD backup (.FCBak) had slipped into the last commit; removed and
    *.FCBak ignored.
    [kit-v0.7e_ansicht.FCStd, kit-v0.9.1_ansicht.FCStd]
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2026-10-08 Insert v0.9.2: radar on ledges, tray a closed frame again
    v0.9.1's full-width antenna window removed the plate strip under the
    radar's parts edge; beside it the cable-loop keep-out takes the tray wall,
    so the tray became an open "C" (owner's slicer view, 2026-10-06).
    The owner's photo of the antenna face shows SMD parts along the whole
    edge opposite the header, corners included. The board now sits on two
    1.3 mm ledges at its short ends (header side only), every part floats
    >= 0.2 above the plate, and the v0.8 window and the plate strip are back.
    build_kit now fails if the tray frame is open there; the radar's front
    parts are no longer exempt from the collision check. Kit: 0 collisions.
    Co-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
    [kit-v0.9.1_ansicht.FCStd, kit-v0.9.1_assembly.step, kit-v0.9.1_printed-assembly.stl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]
2026-10-08 Insert v0.9.3: radar tray fitted to the real board (22.03, 0.15 play)
    The owner's v0.9.2 print: the radar slid about, the tray about 0.5 too
    long, the short side just too loose. The board is 22.03 long (caliper
    photo 2026-10-06), not 22.26: RADAR_H corrected, KIT_RADAR derived from
    RADAR_W/H, tray play 0.2 -> 0.15 per side (= KEY_FIT, measured fit).
    Kit: 0 collisions, tray frame closed.
    [kit-v0.9.2_ansicht.FCStd, kit-v0.9.2_assembly.step, kit-v0.9.2_printed-assembly.stl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]
2026-10-08 Insert v0.10: every part prints without supports (key 2 prints, chassis 3)
    The owner's kit print (2026-10-07, 0.2 nozzle, PETG supports with a PLA
    interface): the key shell and the chassis still broke when the supports
    came out. Owner: open to CA glue or pins.
    - Key = ring + back plate (inside the ring like a lid, 0.1 play, CA).
    - Chassis = front / flange / rear, split by chassis_parts() for every
    variant; 1->2 glued with the collar as the jig, 2->3 on two pins on
    the island ribs (the only free spots).
    - Switch plate glued onto the ledge (owner's choice): no screw bosses;
    the cable anchor now stands on the switch plate.
    - Kit mic tube flush with the deck (front foam 1.5 compressed): i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
    [chassis_L.step, chassis_L_1_front.step, chassis_L_1_front_print.stl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]
2026-10-08 Kit carrier: amplifier pins from the owner's measurement (pitch 12.9)
    The owner's calipers (2026-10-07): the MAX98357A's two mounting holes are
    15.1 outer / 10.7 inner -> centres 12.9, Ø 2.2. The photo estimate gave
    13.97, so the carrier pins sat about 1 mm too wide (the 0.2-nozzle print
    no longer bent to fit). AMP_HOLE_PITCH [MEAS], AMP_HOLE_D 2.2, new
    AMP_PIN_D = hole - 0.3 (0.15 play per side), also for the desk replica.
    Kit: 0 collisions, tray closed, all parts pass the print check.
    [kit-v0.10_ansicht.FCStd, kit-v0.10_assembly.step, kit-v0.10_printed-assembly.stl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]
2026-10-08 Insert v0.10.1: chassis 2->3 pins fit (play, lead-in, pointed pin)
    The owner's v0.10 print (2026-10-08): the two pins of the flange part did
    not go into the rear part's holes. The holes open on the rear part's bed
    face, where the first layers' squish closed the Ø1.4 mouths (0.1 play).
    Now 0.15 play, a 0.25 x 45° lead-in at the mouth and a 0.3 point on the
    pin. L, S, kit: 0 collisions, all parts pass the print check.
    [chassis_L_2_flange.step, chassis_L_2_flange_print.stl, chassis_L_3_rear.step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]
2026-10-08 Insert v0.10.2: one-piece key again, amp pitch 13.435, radar play 0.10
    The owner (2026-10-08):
    - the one-piece key printed with supports fit perfectly; only the chassis
    broke on its supports -> the v0.10 ring/back-plate split is removed, the
    key shell is the v0.9 one again (print file byte-identical). ceilings()
    reports it but does not fail it (PRINT_WITH_SUPPORTS); never the chassis.
    - amplifier pins: 13.97 printed too wide, 12.9 too close -> the mean.
    - radar tray: the same geometry fit once and was loose on the next print
    -> play 0.15 -> 0.10 per side (sand if tight).
    Kit, L, S: 0 collisions, key captive, radar tray closed.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
    [insert-L_assembly.step, insert-L_printed-assembly.stl, insert-S_assembly.step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]
2026-10-08 Insert v0.10.3: collar wider inside (the key scraped), outside unchanged
    The owner (2026-10-08): the collar fits its seat perfectly, but the key
    scrapes its inner walls. Only the inside changes: inner face 0.15 back
    per side (COLLAR_IN_EXTRA) -> key/collar 0.40 per side; the catch-nub
    grooves 0.15 deeper (groove back wall 0.65, rule >= 0.6 at the 0.2
    nozzle). The nubs still overlap the inner face by 0.15; the pull check
    now shifts the key by the full 0.40 -> still captive. 0 collisions.
    [collar.step, collar_print.stl, insert-L_assembly.step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]
2026-10-08 Kit print set: Bambu A1 files (0.4 / 0.2 nozzle), English assembly guide
    - hardware/print/README.md: part list (material, orientation, supports),
    the Bambu files, assembly and gluing steps, the fits found on prints.
    - hardware/print/bambu/: sliced .gcode.3mf for a Bambu Lab A1 + AMS lite,
    0.4 and 0.2 nozzle, three plates each: A white PETG (plate, chassis
    2a/2b/2c, switch plate, carrier), B the key shell with tree supports
    (body PETG, interface clear PLA, top Z 0, no prime tower - the A1 purges
    into its chute; a tower failed the G-code check), C the collar in clear
    PLA. 0.10 layers, 3 walls, outer walls 25 mm/s, first layer 15 mm/s.
    - tools/bambu_kit.py rebuilds them (resolves th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
    [desk-replica_assembly.step, desk-replica_printed-assembly.stl, desk_amp_tray.step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]
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
